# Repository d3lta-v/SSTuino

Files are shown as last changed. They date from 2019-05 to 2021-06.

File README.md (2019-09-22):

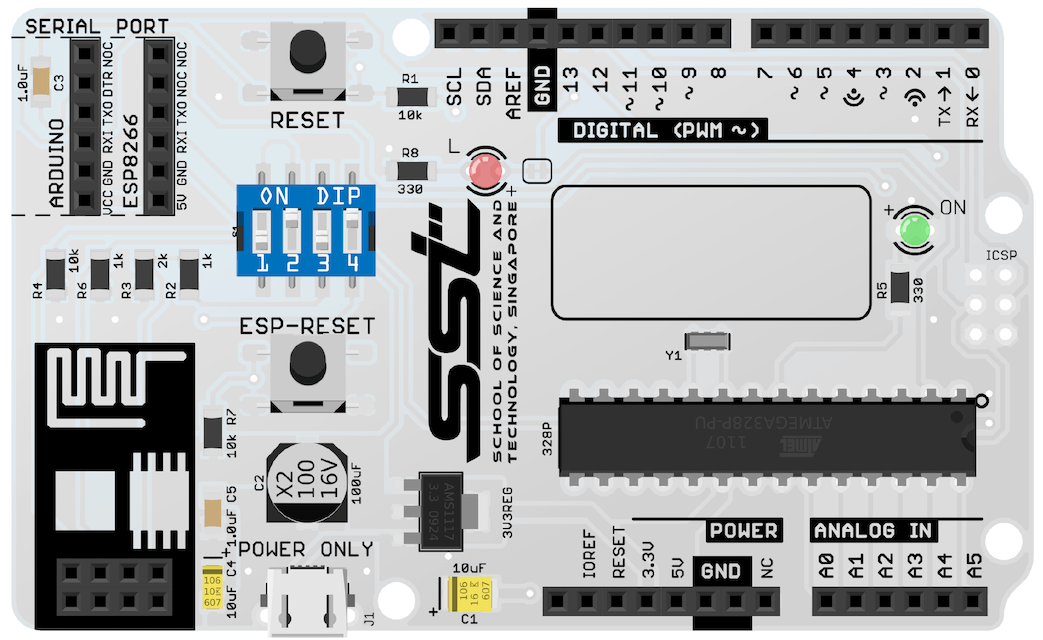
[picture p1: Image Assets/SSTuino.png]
SSTuino


Designed by FourierIndustries LLP | Designed, assembled and tested in Singapore

# SSTuino

SSTuino is an easy to use Wi-Fi enabled microcontroller, designed and fabricated by SST Alumni. Users can write programs to connect or control things over the Internet. It is derived from the SPEEEduino 1.1 with some improvements.

**SSTuino Official Website: [https://sstuino.fourier.industries](https://sstuino.fourier.industries)**

Related projects:

* [SSTuino Companion Library](https://github.com/d3lta-v/SSTuino_Companion)
* [Ultra Light Wi-Fi Interface](https://github.com/d3lta-v/ULWI)
* [ESPblaster](https://github.com/d3lta-v/ESPblaster)

## Technical information

### Repository Layout

* **SSTuino**: EAGLE files for SSTuino
* **Image Assets**: Image assets for websites related to the SSTuino and markdown pages.

### Startup states table

This table controls the various startup states of the ESP8266-01 Wi-Fi module, which allows it to operate, or be reprogrammed with your custom firmware, or even be electrically isolated from the rest of the SSTuino entirely.

|  | GPIO0 (1) | GPIO2 (2) | ESP-RX connect to D4 (3) | ESP-TX connect to D2 (4) | ESP-RESET Button |
|---|:---:|:---:|:---:|:---:|:---:|
| Wi-Fi Enable | ⬆️ | ⬆️ | ⬆️ | ⬆️ | Leave open |
| Disconnect ESP-01 | ❎ | ❎ | ⬇️ | ⬇️ | Leave open |
| Reset ESP-01 | ❎ | ❎ | ❎ | ❎ | Press down |
| Flash ESP-01 | ⬇️ | ⬆️ | ⬇️ | ⬇️ | Press down, set switches, release |

## Contributing

Contributing to the SSTuino Git Repository requires you to have EAGLE 8.4 or newer which supports Managed Libraries.

SSTuino primarily uses EAGLE's Managed Libraries made by Sparkfun, but also contain our own custom footprints and SMD component footprints from Cytron.

## Our team

* Chief Designer: Pan Ziyue ([@sammy0025](https://twitter.com/sammy0025))
* Assistants/Advisers: Goh Qian Zhe ([@QianZheGoh](https://twitter.com/QianZheGoh))
* The awesome folks at Arduino, Sparkfun and Adafruit for technical reference and ECAD models.

OSHW

Open Source Hardware (OSHW)

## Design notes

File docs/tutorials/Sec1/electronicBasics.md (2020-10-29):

---
title: How to not burn your LEDs!
date: 2019-07-03
author: Goh Qian Zhe
---

# How to not *burn* your LEDs!

Before we go into electronics, here is what will happen when if you do not handle them well.

sparkfunGIF

## Some essentials...

In your SSTunino kit, we have provided some components for you to use, and is listed inside the [parts list page](https://d3lta-v.github.io/SSTuino/tutorials/partsList.html). **Note:** If there are any components missing from the kit when you first recieve it, please approach your ICT teachers.

This tutorial will cover the details of the components that are included in the SSTuino Kit, along with some theory behind electronics to help you to build your first circuit in the meantime. This tutorial page is very useful as you can reference to the components in the event you forget what it is.

## Table of Contents

* [SSTuino Board](#sstuino-board)
* [USB C to Micro USB Cable](#usb-c-to-micro-usb-cable)
* [CP2102 MicroUSB Serial Converter](#cp2102-microusb-serial-converter)
* [ESP01S WiFi Chip](#esp01s-wifi-chip)
* [The Resistor](#the-resistor)
* [Light Emitting Diode (LED)](#light-emitting-diode-led)
* [Breadboard](#breadboard)
* [Wires](#wires)
* [Push Button](#push-button)
* [Light Dependant Resistor](#light-dependant-resistor)
* [Buzzer](#buzzer)
* [Potentiometer](#potentiometer)
* [Ultrasonic Sensor](#ultrasonic-sensor)
* [TMP36 Temperature Sensor](#tmp36-temperature-sensor)
* [PIR Proximity Sensor](#pir-passive-infra-red-sensor)
* [DHT11 Temperature and Humidity Sensor](#dht11-temperature-and-humidity-sensor)
* [Servo](#9g-micro-servo)
* [RGB LEDs](#rgb-led-common-cathode)
* [Last but not least](#last-but-not-least)

## SSTuino Board

<p align="center">
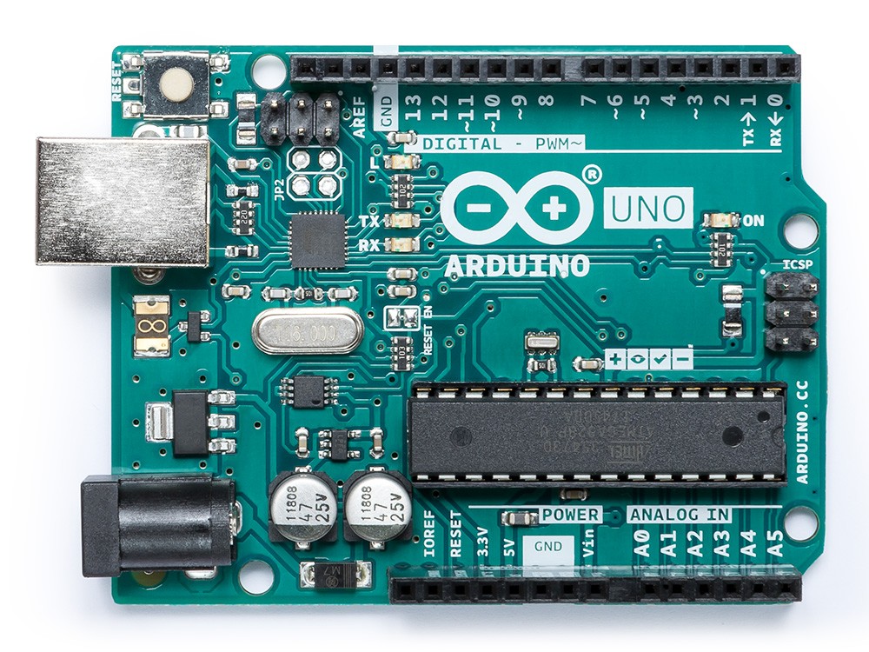
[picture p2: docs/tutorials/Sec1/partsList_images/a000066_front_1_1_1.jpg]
  
   
</p>

*Notice any difference?*

For students who are familliar with the Arduino UNO, you would realise that it looks pretty simillar to the SSTuino. This is because that the SSTuino is an adapted design from the Arduino UNO. This device shares a lot of similarities as the UNO such as:

- Coding compatability
- Shield compatability as the SSTuino shares the same I/O Pins as the Arduino Uno
- Sharing the most of the same components

The major design difference with this board is that it has a extended board footprint to accept a WiFi chip, resulting the SSTuino to be an Internet-Of-Things (IoT) enabled product. This means that the SSTuino can connect to the internet to send/recieve data!

## USB C to Micro USB Cable

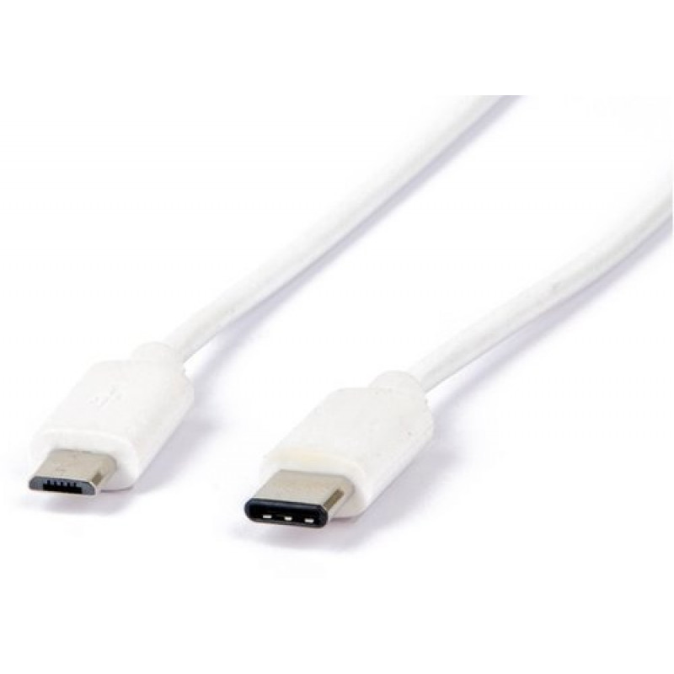
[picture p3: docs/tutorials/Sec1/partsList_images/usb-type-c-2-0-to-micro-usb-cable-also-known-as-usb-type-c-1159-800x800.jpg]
USBC to MicroUSB


The USB C to Micro USB Cable is a unique cable that helps you connect your USB C Mac to the CP2102 MicroUSB Serial Converter. As this type of cable is less commonly seen in the market, please take good care of this wire as it is not easy to obtain one.

## NEU (New Enhanced UART) CP2102

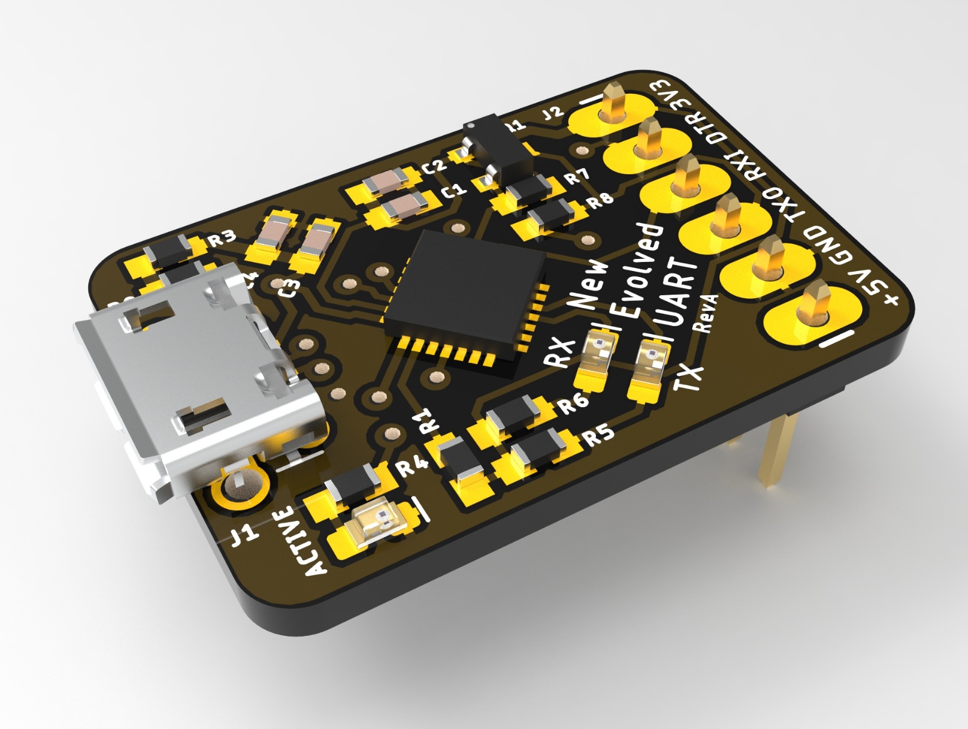
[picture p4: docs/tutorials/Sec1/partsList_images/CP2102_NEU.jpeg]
MicroUSB CP2102


The CP2102 MicroUSB Serial Converter is a very important device to have as it is the communication tool between the computer and the microcontroller (SSTuino). We designed SSTuino to have a external Serial Converter as not only is it modular, where you could change the chip in the event it is spoilt, you could also use the CP2102 to communicate with other serial devices such as the ATTiny85 or the Raspberry Pi.

This is where you would use your USB C to Micro USB cable to plug into this chip for uploading of code from your computer to the SSTuino.

The NEU (New Enhanced UART) is a custom designed serial converter designed by Pan Ziyue for the SSTuino Innovator's Kit, and is designed to work with your Mac and SSTuino. As there are limited production quantities in each run, please refrain from losing the chip. Moreover each chip is expensive to manufacture so again please take good care of the chip.

## ESP01S WiFi Chip

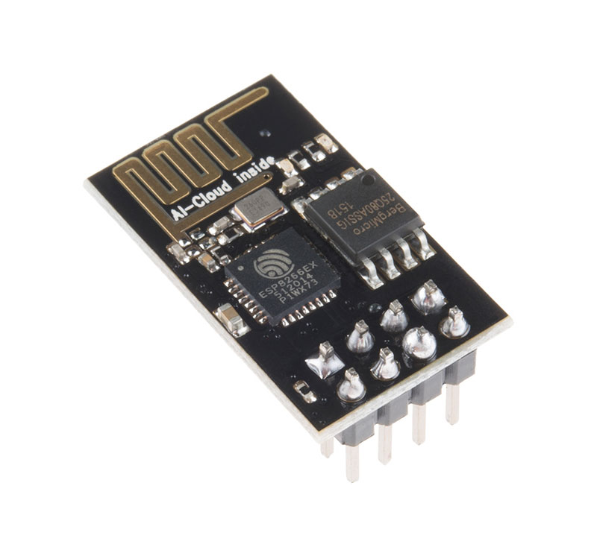
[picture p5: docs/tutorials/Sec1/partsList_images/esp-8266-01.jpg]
ESP-01S


The ESP01S WiFi Chip is what sets the SSTuino different from the Arduino UNO. It allows the SSTuino to be able to connect to the internet, allowing the SSTuino to have smart home, automation and internet connected sensor abilities.

Our team is developing more content to help you get started in developing IoT products, so do watch this space for more details.

## The resistor
### Ohms Law

For a more detailed read, click [here](https://www.allaboutcircuits.com/textbook/direct-current/chpt-2/voltage-current-resistance-relate/)

Ohm's Law is the most basic relationship between voltage, current and resistance. A circuit is formed when there is a conductive path for electric charge to move. 

The movement of the electric charge is **current**, expressed in Amperes (A). 

The force that enables the electric charge to move, or the potential energy is **voltage**, expressed in volts (v). 

In the circuit, there is bound to be some "friction" that resists the movement of electric charge, and that is **resistance**, expressed in Ohms (Ω). 

ohmLawTable

Resistors are essential in every circuit. They limit the flow of current in your circuit so *hopefully* there are no burnt components. 

### Types of resistors

For generic resistors, there is generally two types of resistors: Carbon Composite Resistor or Film Type Resistor. Carbon resistors are popular due to their extremely low cost and good accurancy with low enough tolerance (usually about +- 5%). Flim Type Resistor, while being slightly costlier, provide closer tolerances (up to +-1%) from the rated resistance.

<p align="center">
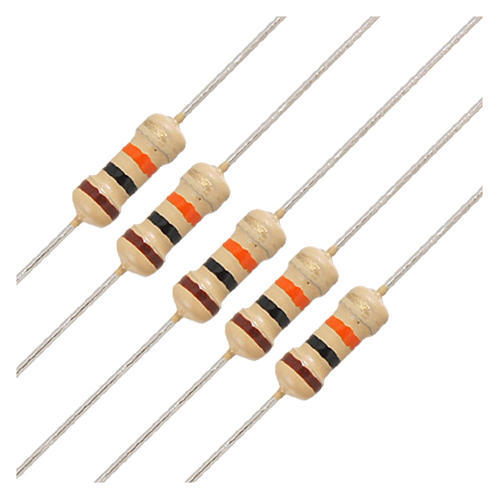
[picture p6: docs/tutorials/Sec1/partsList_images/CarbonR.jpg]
  
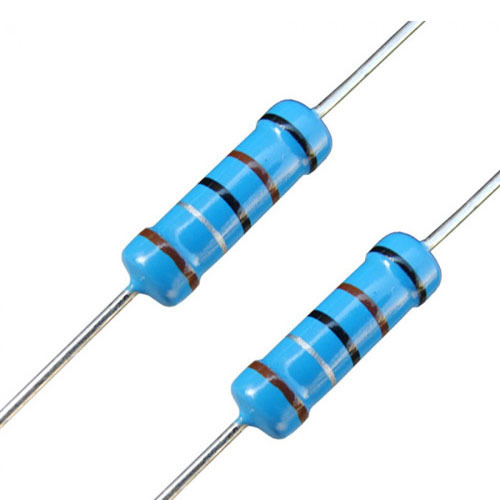
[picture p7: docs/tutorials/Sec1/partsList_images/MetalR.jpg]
   
</p>

*Carbon Film Resistors (left) and metal oxide resistors (right).*

The resistors provided in the kit is metal oxide resistors and have values of 330 Ohm and 10K Ohm. You can read the values of the resistor from the colour band on the component.

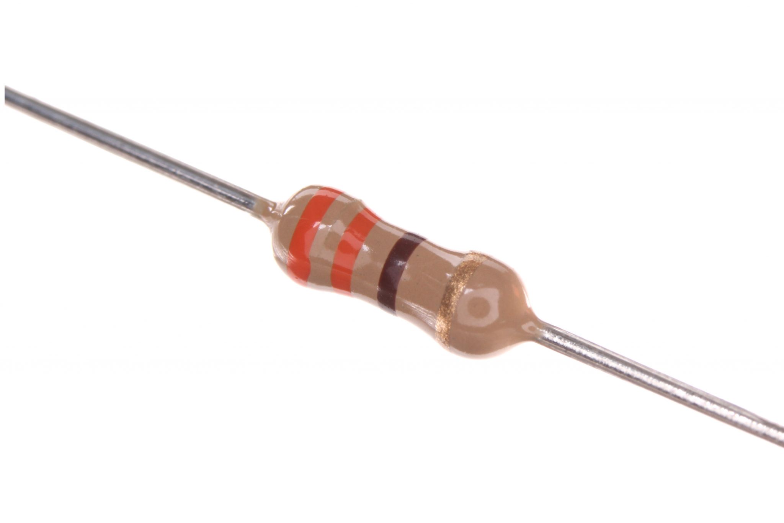
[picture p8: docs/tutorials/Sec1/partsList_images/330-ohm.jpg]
330Ohm


This is a **330 Ohm** resistor.

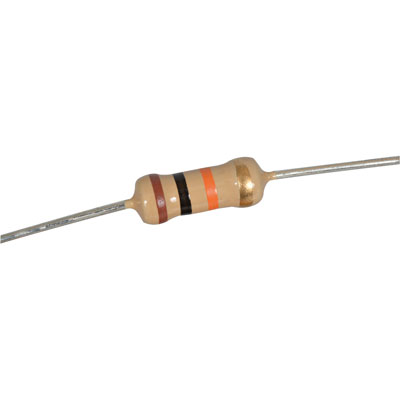
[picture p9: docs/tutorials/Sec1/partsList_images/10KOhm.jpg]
10KOhm


This is a **10K Ohm** resistor.

If you are wondering how to read the values of resistors, refer to the infograpic below:

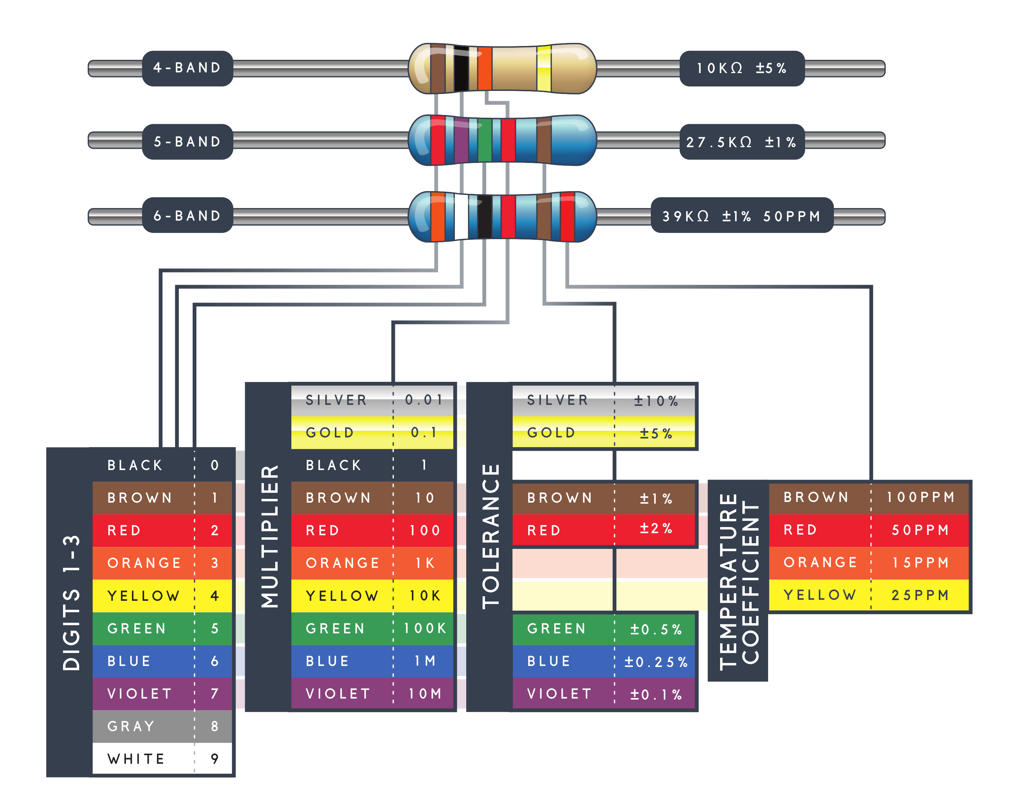
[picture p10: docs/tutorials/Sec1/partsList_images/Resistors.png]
resistorChart


## Light Emitting Diode (LED)

Somehow or another, you would realise that you would need something to light up! Say hello to the LED! LEDs are small, efficient lightbulbs (that are rather bright). They are found in a large variety of devices like mobile phones, computer screens, the headlamps of the car and even spotlights!

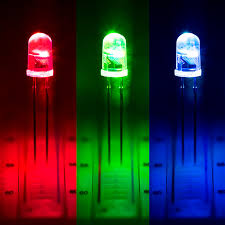
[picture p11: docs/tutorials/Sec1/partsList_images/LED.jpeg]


So, you might be wondering how should you place an LED in a circuit? Here are the 3 most important things to take note:

### Polarity is important

As LEDs are essentially diodes, it will only allow current flow in one direction. This is why if you take a look at your SSTuino Innovator's Kit, you would realised that your LEDs have legs that are of different lenghths. Does the different lengths of legs indicate manufacturing defect? On the contary, the legs are specifically manufactured like this so that the you can identify the polarity of the LED easily.

The longer leg of the LED is the **positive** leg and is called the **anode**. The shorter leg of the LED is the **negative** leg and is the **cathode**. 

*But what if you just nice happen to connect it the wrong way? Would it explode?* 

The LED would not light up, so not to worry. You can just simply reverse the polarity of the LED (i.e flip the thing around) and it will work again!

### More current = More light!

As the LED is brighter (with the same voltage applied), the current draw would be higher. If you happen to purchase super-bright LEDs, you would realise that they drain your battery easily. With this, you can change the brightness of the LED by adjusting the amount of current that goes through it.

### BOOM!

As with most electronics, there is always a limit to everything. Once an LED draws current beyond a certain limit, you can see the colour change and then... it dies. RIP.

So to prevent tragic things like this from happening, we introduce resistors into the circuit to limit the amount of current the LED can draw. But what resistor would be most suitable?

## Some simple circuit theory...

Let us assume that we have some LEDs, resistors and a power source. Without any knowledge about datasheets and calculation, how should we go about connecting them together?

connection

It is that simple.

Moreover, a good resistor value for LEDs is 330Ohms (can be more or less), so we can simply use this resistor. *Easy, right?*

## Breadboard

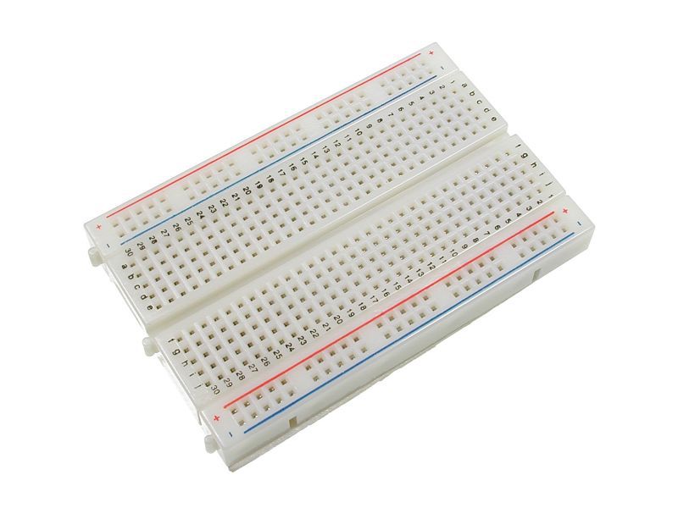
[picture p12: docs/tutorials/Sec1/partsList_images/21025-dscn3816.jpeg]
Breadboard


So you happened to see a retangular shaped block with holes in it and wondered what it was? This block is called a **breadboard** or **prototyping board**. The breadboard is a very important part of your prototype when you develop new things!

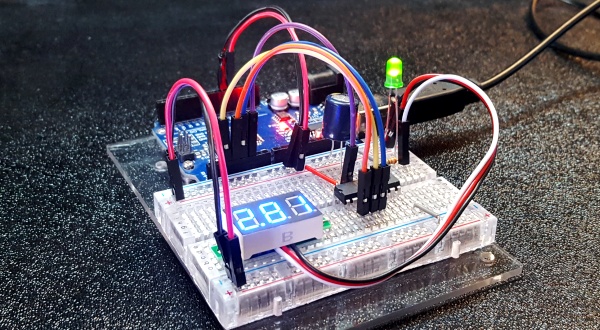
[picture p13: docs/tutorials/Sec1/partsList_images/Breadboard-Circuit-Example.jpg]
Breadboard with circuit


In your ICT lessons, your teacher would go through with you on how to connect up your circuit. Moreover, you would be using TinkerCAD to simulate and view your *virtual* circuit before actually building it, preventing any (touch wood) *magic smoke*.

The layout of the breadboard is done such that you can assemble your circuits easily.

<p align="center">
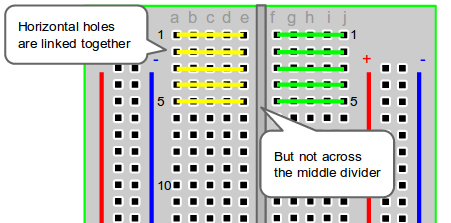
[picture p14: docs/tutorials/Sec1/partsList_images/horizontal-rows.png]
  
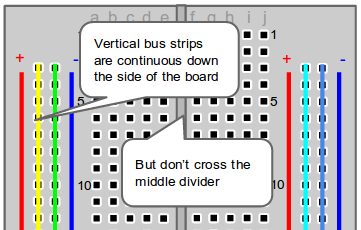
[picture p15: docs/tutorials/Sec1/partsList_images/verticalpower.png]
   
</p>

## Wires

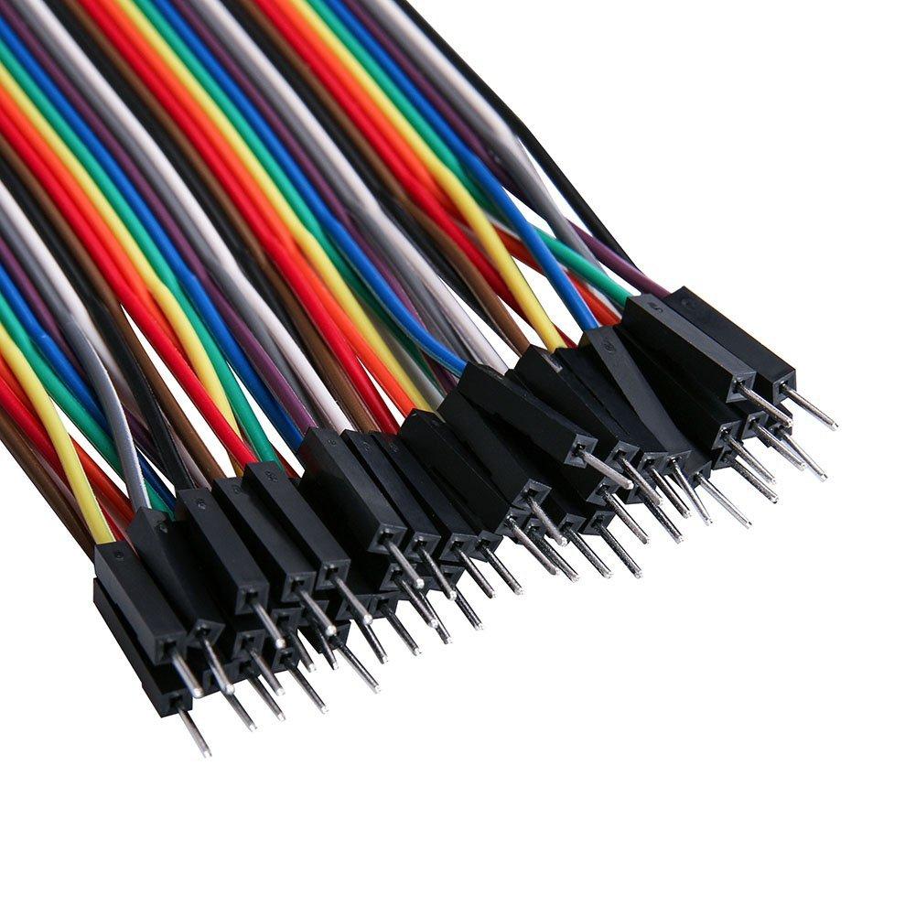
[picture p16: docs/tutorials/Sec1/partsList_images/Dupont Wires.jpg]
Wires


Wires are the most important part of your circuit. Without them, you would not be able to have electricity flowing through your circuit as there is simply nothing connecting them together! The wires provided in the kit are Male - Male Dupont wires (*I dont think I have to explain why the ends of the wire is male, right?* *wink*), and are the right size for you to be able to connect from your SSTuino to the breadboard or the component.

## Push Button

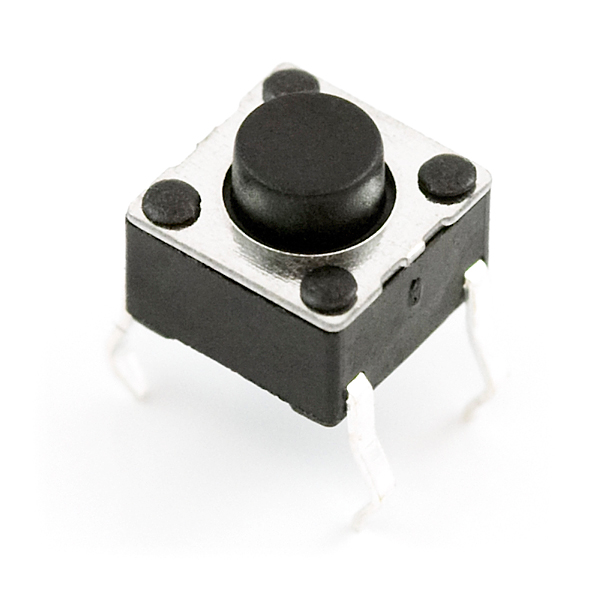
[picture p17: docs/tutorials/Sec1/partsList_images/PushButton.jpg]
Push Buton


This push button is a very simple example of a switch. But before you connect this push button into your house's mains, please do not do so :). The push button is meant for the breadboard instead.

When the push button is pressed down, the circuit is closed and current would flow through the two terminals of the button. Likewise, when the push button is not pressed down, the circuit will be open and current would not flow through the two terminals of the button. One good example would be your Macbook keyboard. As you depress the key, the circuit is closed and the computer can detect wether the key is pressed down or not

## Light Dependant Resistor

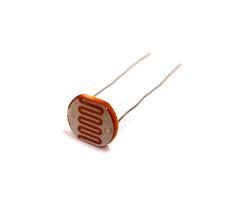
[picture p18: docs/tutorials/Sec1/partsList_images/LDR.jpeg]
LDR


As the name suggests, the Light Depedant Resistor (or Photoresistor) is a component that changes resistance when the light intensity changes. For the LDR that is provided in the kit, the resistance of the LDR **decreases** when the light intensity **increases**.

Like a normal resistor, there is no polarity for the LDR and can be connected in both sides.

## Buzzer

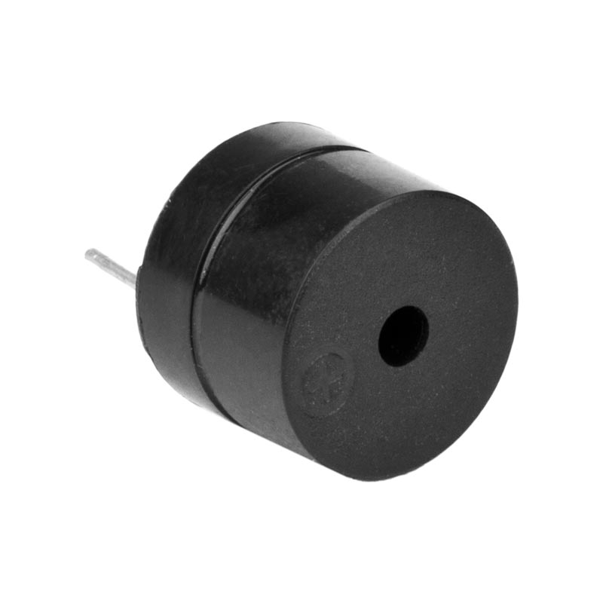
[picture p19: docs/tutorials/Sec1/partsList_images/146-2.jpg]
Buzzer


This buzzer is a Piezo Buzzer. If you try to open up the buzzer, you would see that there are a few embedded components inside the buzzer. What happens when you connect it to power is that it is converted to an oscilating signal, which is amplified and applied to the piezo disc. This causes the material to expand and contract rapidly, which results in sound waves being produced. 

**Note:** The sound from the Piezo buzzer can be quite sharp and loud. Do be careful when using these components.

## Potentiometer

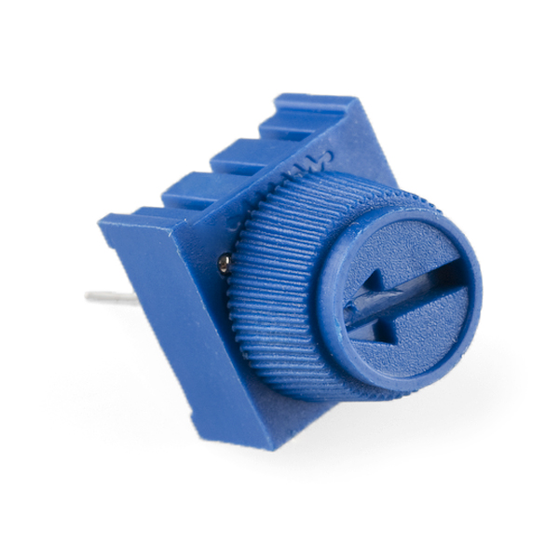
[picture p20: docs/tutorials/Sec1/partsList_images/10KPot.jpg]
10K pot


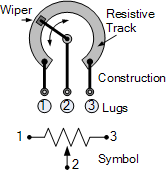
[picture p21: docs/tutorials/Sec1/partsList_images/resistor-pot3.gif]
Pot Sch


The potentiometer is a variable resistor, with a adjustable knob. As the knob is turned from one side to another, the resistance changes. Potentiometers are used for controlling devices, such as the brightness of the LED, and with the appropriate circuit, the speed of a motor.

## Ultrasonic Sensor

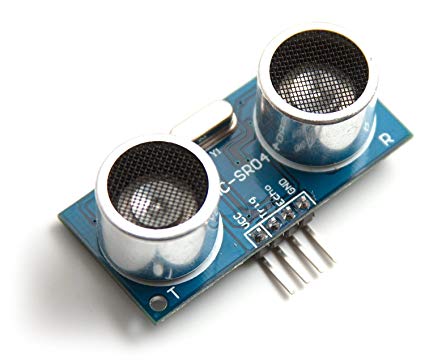
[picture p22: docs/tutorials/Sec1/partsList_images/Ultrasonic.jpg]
Ultrasonic


The ultrasonic sensor is a device that measures distance by emitting ultrasonic waves, waits for the wave the bounce back and then measure the time taken.

## TMP36 Temperature Sensor

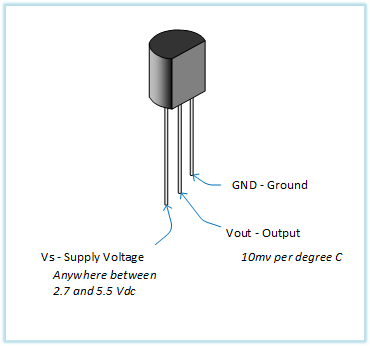
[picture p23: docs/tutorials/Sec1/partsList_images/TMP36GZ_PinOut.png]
TMP36Pinout


The TMP36 temperature sensor is a rather accurate sensor despite is low price. For more information, visit the [Adafruit Website](https://learn.adafruit.com/tmp36-temperature-sensor/overview).

**Note:** You may notice that this package may resemble that of other components such as transistors. **Please do not mix them up and read the respective manuals carefully.** The component model would be marked out on the **flat** side of the component for this package. Use the model number to search for the pinouts for you to make sure you are connecting the component the right way.

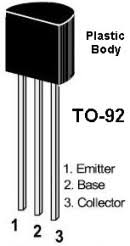
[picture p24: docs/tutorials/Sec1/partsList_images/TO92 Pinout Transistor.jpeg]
TransistorPinout


This shape and pinouts is called the TO-92 Package and is a very cheap and easy to manufacture method for transistors.

## PIR - Passive Infra-Red Sensor

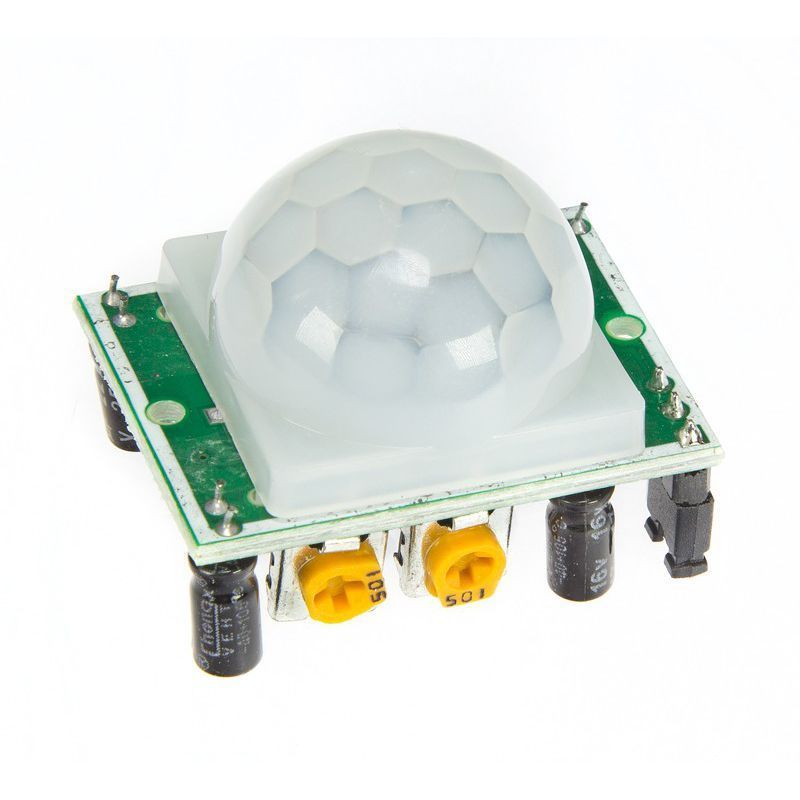
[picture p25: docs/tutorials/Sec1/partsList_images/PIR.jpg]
PIR


PIR sensors are low-power, inexpensive and easy to deploy devices that detect if a person is in range of the sensor. A common use would be the light sensor installed in toilets that automatically turns on the lights when someone steps into the toilet.

To find out more about how it works, check out this detailed explanation from Adafruit: [https://learn.adafruit.com/pir-passive-infrared-proximity-motion-sensor/how-pirs-work](https://learn.adafruit.com/pir-passive-infrared-proximity-motion-sensor/how-pirs-work)

## DHT11 Temperature and Humidity Sensor

DHT11

The DHT11 Temperaure and Humidity sensor is an excellent hobbyist sensor, albeit with low refresh rates. It is also cheap to purchase and has relatively good accuracy for basic data logging. The data from the sensor can also be easily read from any microcontroller.

## 9g Micro Servo

servo

This Micro Servo has a lot of cool uses! Being a servo, it has precise control from 0 to 180º and is a very good component for prototyping.

## RGB LED (Common Cathode)

RGB LED

The RGB LED is a more complex version of the conventional coloured LED. It combines 3 LEDs (Red, Green and Blue) into one package. By configuring the intensity of the various LEDs, you can create lots of different colours from this LED.

## Last but not least

 This tutorial is meant for you to know that with every component that you use, you will need to decide for yourself wether it fits the circuit or not; be it simple components like LEDs and buzzers to more advanced (*and more expensive*) components like LCD displays and sensors!

One thing that is great when you explore the Arduino ecosystem is the immense amount of community support. When in doubt, always ask. As an individual learning 21st century digital skills, there are lots of platforms where your queries can be answered. It is just a matter of wether you would want to go and find the correct resources or not.

Therefore, before giving up on your design, maybe consider:

* Refering to your component manual. They will include essential infomation about the properties of the component
* Google the issue. Usually people would have posted this issue online in places like forums (StackOverflow, Arduino forum, Reddit etc.)
* Ask around about that issue. You can also post your questions in the appropriate channels, and if the question is good, others can learn from the issues that you faced!

If you would like to know more about:

* Ohm's Law : [(Link)](https://learn.sparkfun.com/tutorials/voltage-current-resistance-and-ohms-law/all)
* LEDs : [(Link)](https://learn.sparkfun.com/tutorials/light-emitting-diodes-leds/all#introduction)

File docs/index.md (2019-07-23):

---
---

## SSTuino Official Webpage

Populated PCB

SSTuino is an easy to use Wi-Fi enabled microcontroller, designed and fabricated by SST Alumni. Users can write programs to connect or control things over the Internet. It is derived from the SPEEEduino v1.1 with some improvements.

### Documentation

For documentation on this project, please refer to our [Github Wiki](https://github.com/sammy0025/SSTuino/wiki) (currently WIP) for more information.

For tutorials regarding SST lessons, please refer to the tutorials here:

* [https://d3lta-v.github.io/SSTuino/tutorials/](https://d3lta-v.github.io/SSTuino/tutorials/)
* [https://sites.google.com/sst.edu.sg/sstuino/home](https://sites.google.com/sst.edu.sg/sstuino/home)

OSHW

Open Source Hardware (OSHW)

### Interested to make a difference?

Students who are interested to deveop our product further can express their interest in **[this form](https://forms.gle/ntMWiXFDy3Ya1Pq5A)**.

### Our team

The Team

*Pan Ziyue (Left) and Goh Qian Zhe*

### Support or Contact

Pan Ziyue: [random.rrr3@gmail.com](mailto:random.rrr3@gmail.com)

Goh Qian Zhe: [goh_qian_zhe@s2012.sst.edu.sg](mailto:goh_qian_zhe@s2012.sst.edu.sg)

If you need anything to be replaced, please email us!

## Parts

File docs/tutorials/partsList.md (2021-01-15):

---
title: Parts List
date: 2019-04-18
author: Goh Qian Zhe
---

# Parts List for the SSTuino Innovator Kit (2021)

This parts list applies to the kits for the 2021 batch.

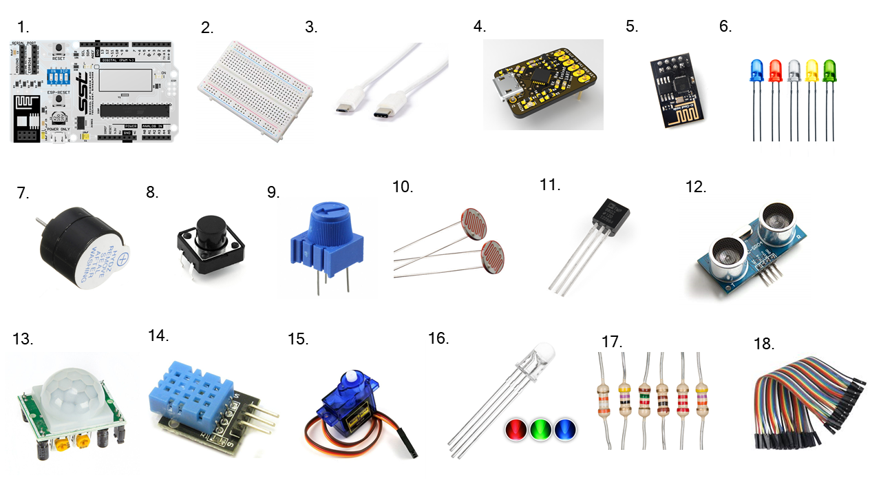
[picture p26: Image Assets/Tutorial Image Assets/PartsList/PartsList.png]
Parts List


| No. | Component Name | Quantity  |
|--- |:---:| ---:|
| 1 | SSTuino Board | 1 |
| 2 | Breadboard | 1 |
| 3 | USB C to MicroUSB Cable | 1 |
| 4 | NEU (New Enhanced UART) | 1 |
| 5 | ESP01S WiFi Chip | 1 |
| 6 | Assortment of LEDs | 1 bag |
| 7 | Buzzer | 1 |
| 8 | Push Button | 2 |
| 9 | Potentiometer (10K Ohm) | 1 |
| 10 | Light Dependent Resistor | 1 |
| 11 | TMP36 Temperature Sensor | 1 |
| 12 | Ultrasonic Sensor | 1 |
| 13 | PIR Proximity Sensor | 1 |
| 14 | DHT11 Temperature and Humidity Sensor| 1 |
| 15 | Servo | 1 |
| 16 | RGB LEDs | 1 |
| 17 | 330Ohm and 10KOhm resistor reel | approx 25 |
| 18 | Dupont cables (wires) | 1 |

In the event of any missing components for the kit, feel free to bring this up to your ICT teacher.

The explanation of the components included in the kit is in this particular tutorial: [*How to not **Burn** your LEDs*](https://d3lta-v.github.io/SSTuino/tutorials/Sec1/electronicBasics.html)

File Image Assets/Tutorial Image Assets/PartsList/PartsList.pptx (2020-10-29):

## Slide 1

1.

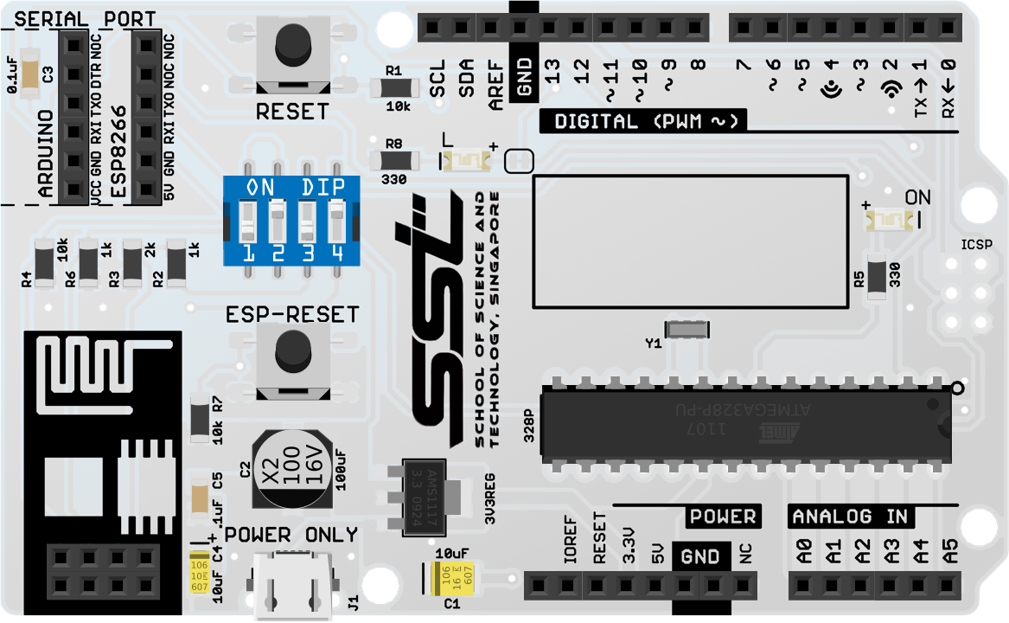
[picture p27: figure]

2.

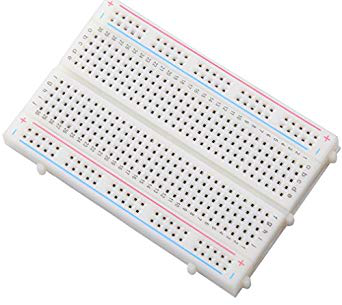
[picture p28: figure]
Image result for mini breadboard

3.

Image result for usb c to micro usb cable

4.

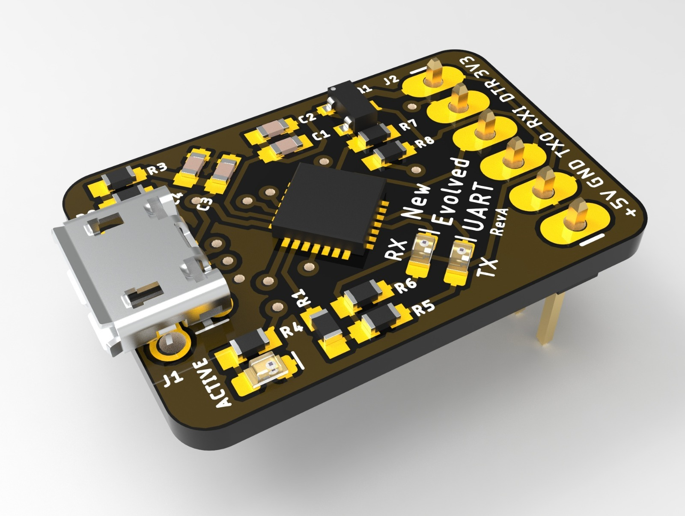
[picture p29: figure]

5.

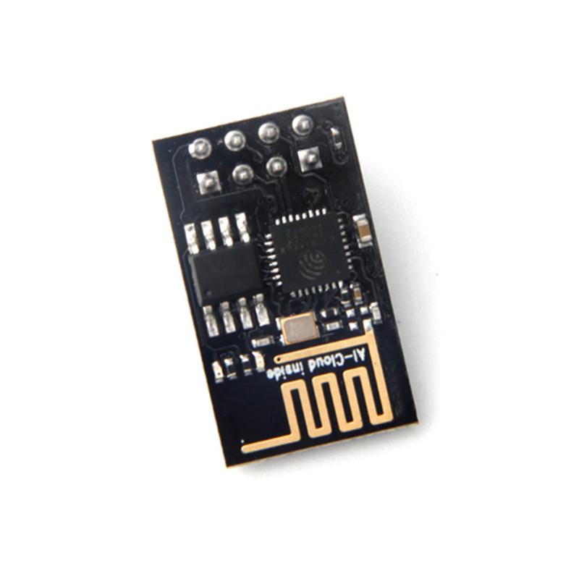
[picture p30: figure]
Image result for ESP 01

6.

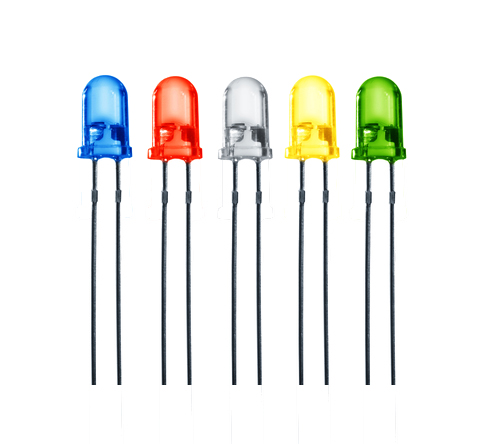
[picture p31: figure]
Image result for LEDs

7.

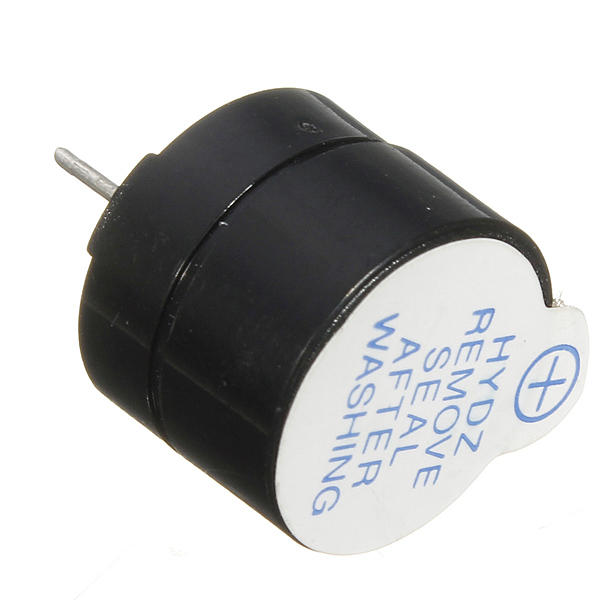
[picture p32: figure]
Image result for 5v buzzer

8.

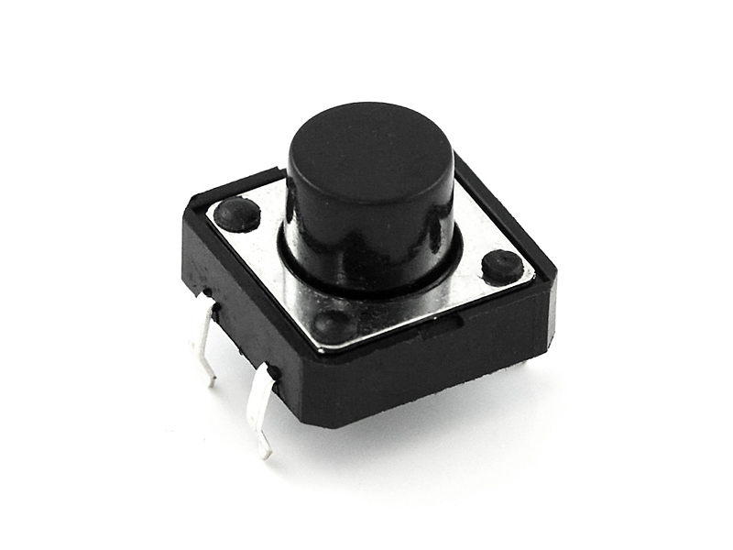
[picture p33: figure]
Image result for push button

9.

Image result for BOURNS 3386F potentiometer

10.

Image result for ldr
Image result for tmp36

11.

12.

Image result for ultrasonic sensor

13.

14.

15.

16.

17.

18.

HC-SR501 PIR Motion Sensor Module - Elektor
Using DHT11 - Hackster.io
SG90 Micro Servo
Electrobot 100 Pcs 5mm RGB LED Diode Lights Tricolor (Multicolor Red Green Blue 4 pin Common Cathode Clear DC 20mA/Color) Super Bright Lighting Bulb Lamps Electronics Components Light Emitting Diodes: Amazon.in: Industrial
Image result for resistors
Image result for dupont wires

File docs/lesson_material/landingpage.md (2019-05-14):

---
title: Setup
date: 2019-04-18
author: Goh Qian Zhe
permalink: /tutorial/
---
# Tutorials
Tutorials can help you get started with using your SSTuino, or bring you further.

## Before you start
Before you begin playing around with the SSTuino kit here are some things to do:

* Click here to access list of items provided in your kit.
* [Click here to setup your laptop and SSTuino kit ready for use.](https://d3lta-v.github.io/SSTuino/gettingStarted/)

## Sec 1 Tutorials

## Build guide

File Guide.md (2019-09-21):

# Getting started with the SSTuino

*This section has unconfirmed steps/the steps require further testing. However, just follow though this guide, as it currently works with most of the Macs for SST.*

SSTuino is an easy to use Wi-Fi enabled microcontroller, designed and fabricated by SST Alumni. Users can write programs to connect or control things over the Internet. It is derived from the SPEEEduino 1.1 with some improvements.

This tutorial is a simple guide on how to get started with the SSTuino. Further guides will be posted and linked to this page in the future.

## Setting up...

Here are a list of things you require to start using the SSTuino. **Installation of the Arduino IDE and Silicon Labs driver for the CP2102 provided in the SST kit will be covered in the later sections**
* A computer loaded with the Arduino IDE, available [here](http://https://www.arduino.cc/en/Main/Software)
* For MacOS users (and Windows users who have to manually install the driver), please download the Sillicon Labs driver from [this website](https://www.silabs.com/products/development-tools/software/usb-to-uart-bridge-vcp-drivers)
* The ESP01 Module (WiFi Chip)
* USB to serial converter. The ones included in the **SST kit** is the CP2102.

## Installation of the Arduino IDE

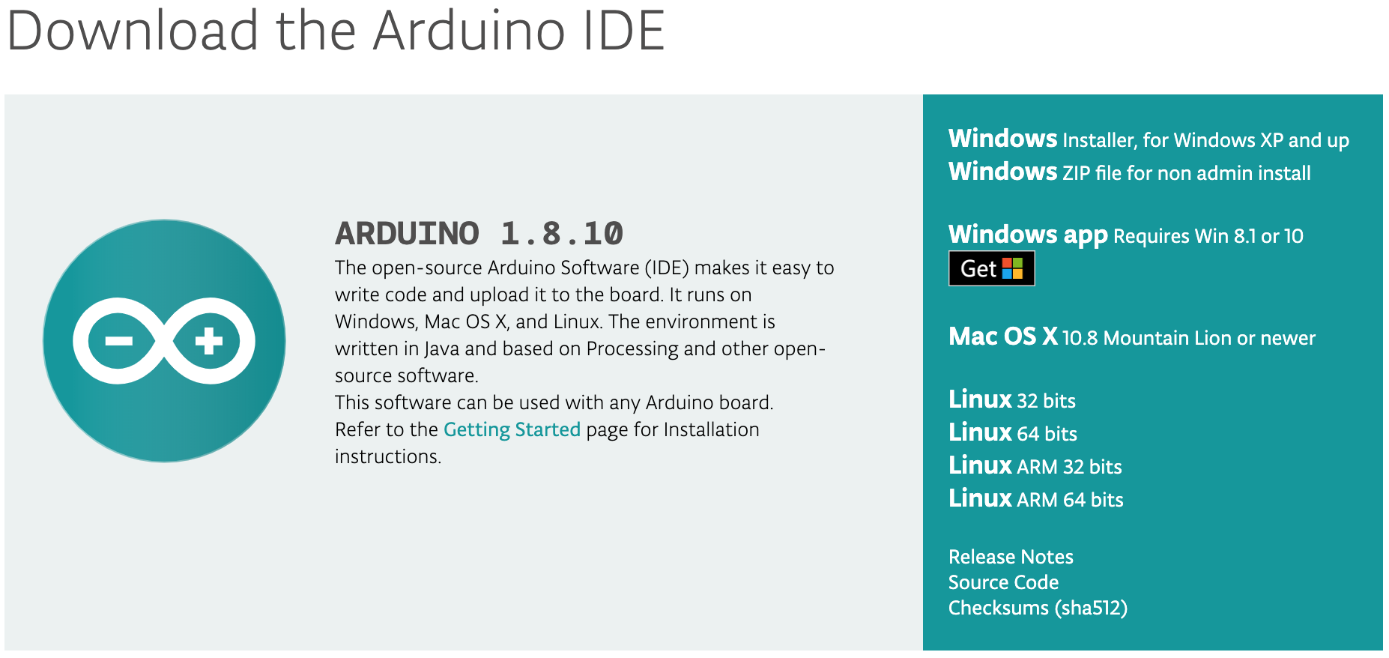
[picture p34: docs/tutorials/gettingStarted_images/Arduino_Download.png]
Arduino.cc Download Page


*  Go to the the downloads page [here](http://https://www.arduino.cc/en/Main/Software)
*  Download the version of the application you require.
   * For MacOS users download the Mac OS X version (10.7) and newer.
   * For Windows users, there are quite a few options:
      * For all devices, you can download either the installer or the zip file. I personally prefer the zip file (as it can be done as a non-admin install, and it is convinent.) However, it is your personal preference for the installation method.
      * Alternatively, for Windows 8.1 and 10, you can go to the Microsoft Store and download it.

### Installation for MacOS
After download of the zip file from the Arduino website, simply copy the .app file into your *Applications* folder. 

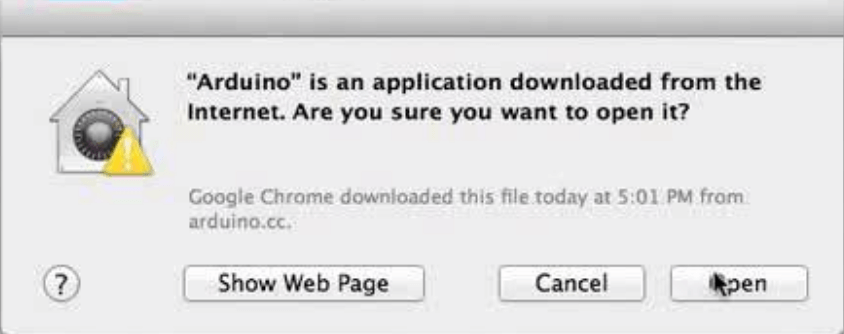
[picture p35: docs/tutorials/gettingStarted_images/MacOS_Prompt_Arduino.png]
MacOS prompt


In any event the system asks you whether to open the app, just click open

## Installation of the CP2102 Driver
We are using the CP2102 USB to serial converter for our SSTuino.

### Installation for MacOS

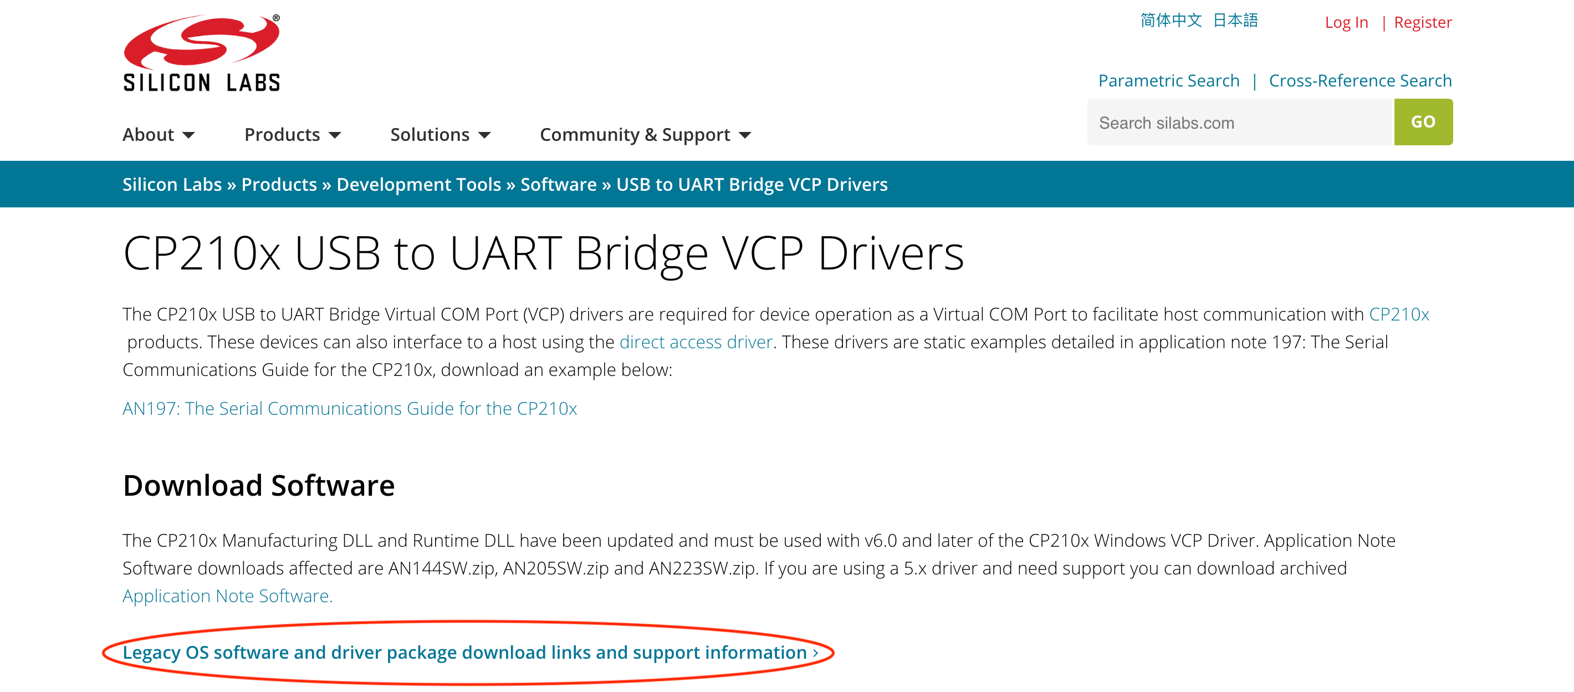
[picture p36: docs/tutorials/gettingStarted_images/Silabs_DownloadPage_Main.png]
Silabs_Download_Main


For MacOS users, the Silicon Labs driver has to be manually downloaded and installed. The driver can be downloaded [here.](https://www.silabs.com/products/development-tools/software/usb-to-uart-bridge-vcp-drivers)
After the page has loaded click the link circled in the picture. *Note - this procedure is not finalised. This method will be used for the time being due to incompatability with the new Macbooks.*

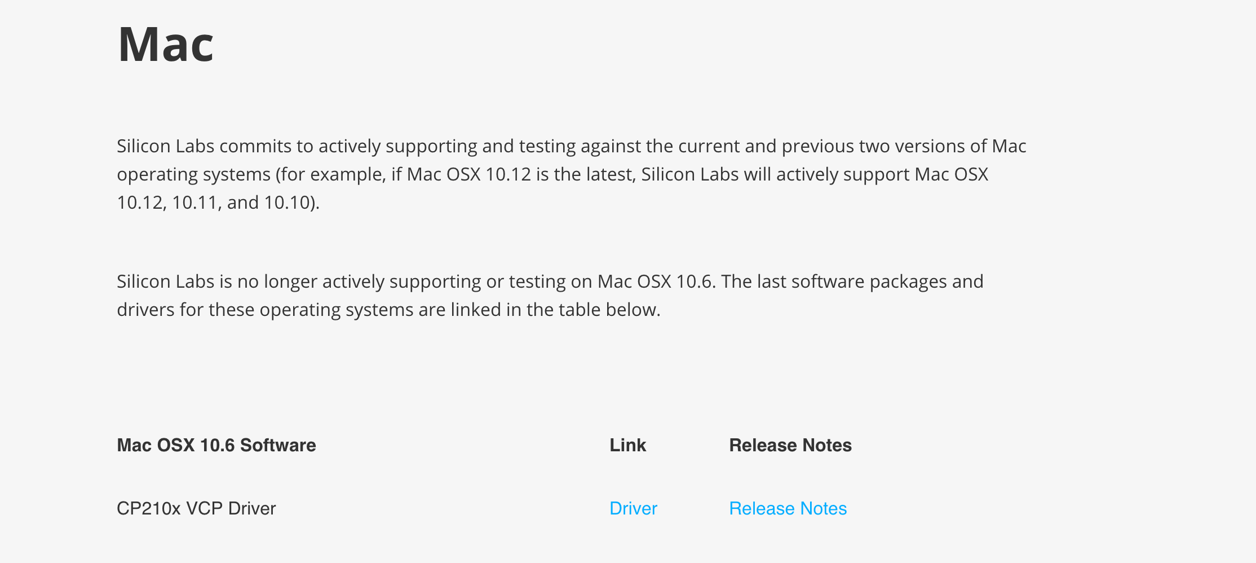
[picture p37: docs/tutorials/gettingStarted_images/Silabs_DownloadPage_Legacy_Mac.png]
Silabs_Download_Mac_legacy


Navigate to this area and download the driver.

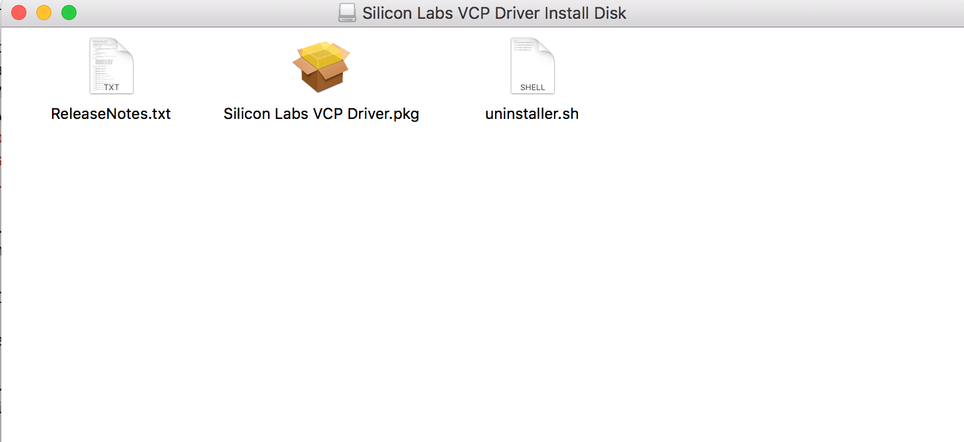
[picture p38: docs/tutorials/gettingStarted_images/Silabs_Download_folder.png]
Silabs_Download_Folder


After the driver has been downloaded, *unzip* the file and launch the **disk image.** You will now see three files, as pictured below. Run the package (.pkg) file.

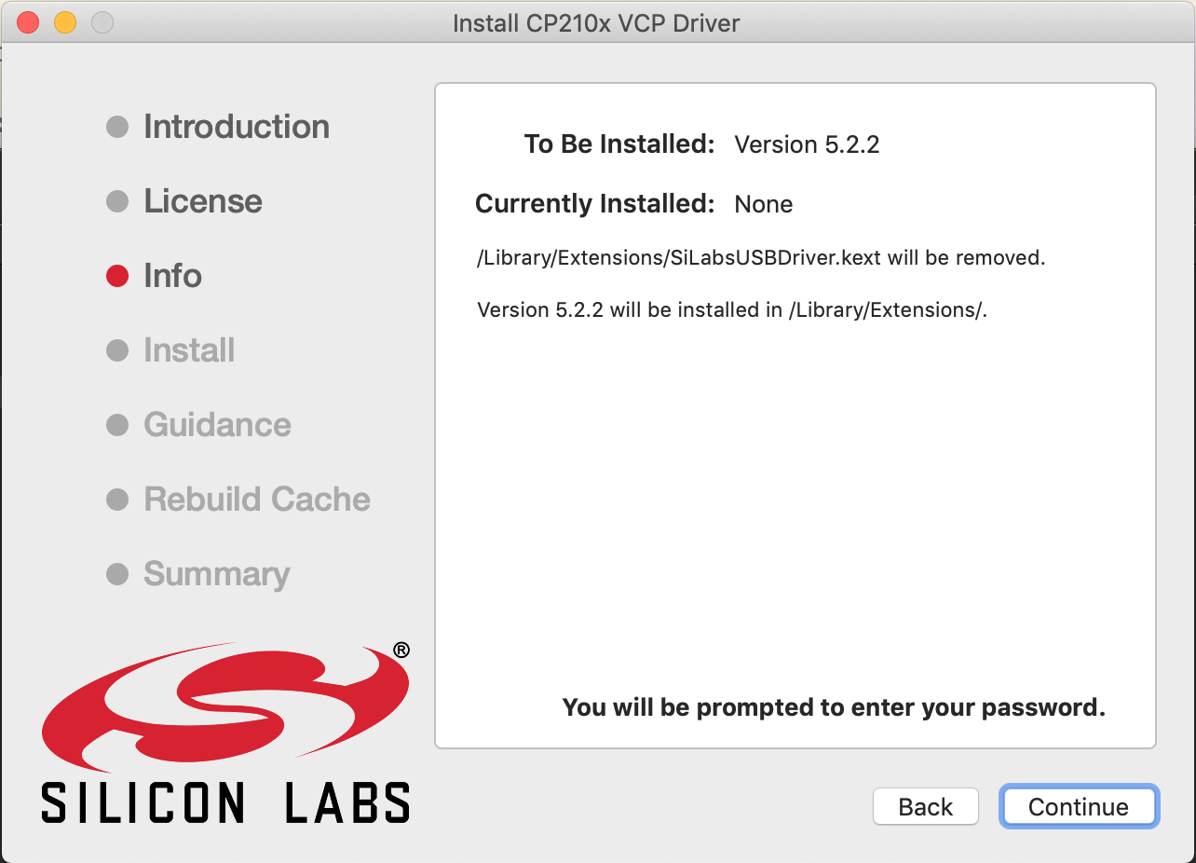
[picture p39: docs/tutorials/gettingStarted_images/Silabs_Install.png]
Silabs_Installation_App


Install the drivers.  **This requires elevated admin rights (devices with parental controls will not be able to install unless an admin allows the installation.)**

During installation, you may encounter a pop-up which would ask you to go to your system preferences. Click ok first. *This is still undergoing tests as we have issues with this part.* 

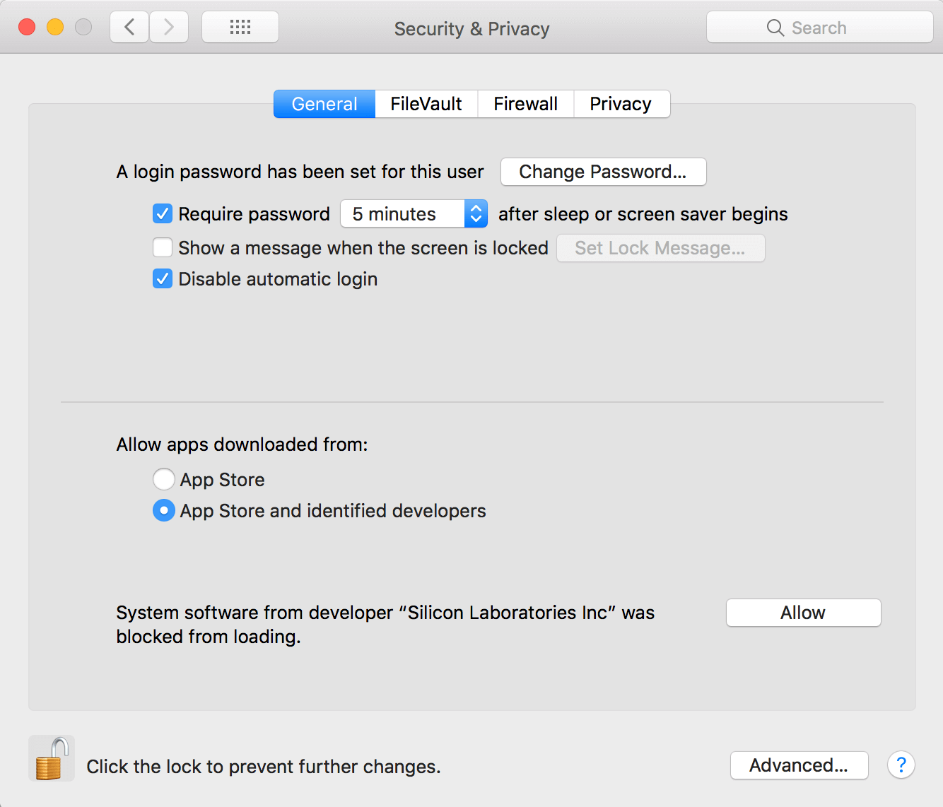
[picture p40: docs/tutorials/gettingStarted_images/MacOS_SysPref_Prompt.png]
SiLabs Prompt


While the installer is running, go to System Preferences -> Security and Privacy and allow the Silicon Labs prompt. 

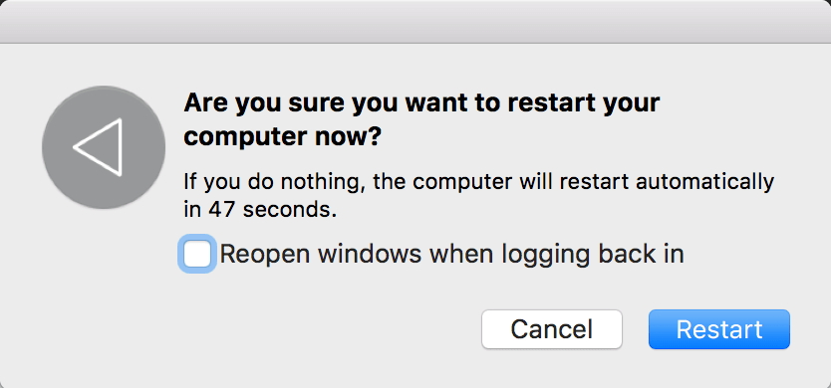
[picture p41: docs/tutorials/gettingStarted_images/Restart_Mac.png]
Restart Mac


After the installation has finished, simply restart your mac.

To check if the USB to serial converter can be detected, go to Terminal and type in this line

`ls /dev/tty.*`

and press *enter/return.*

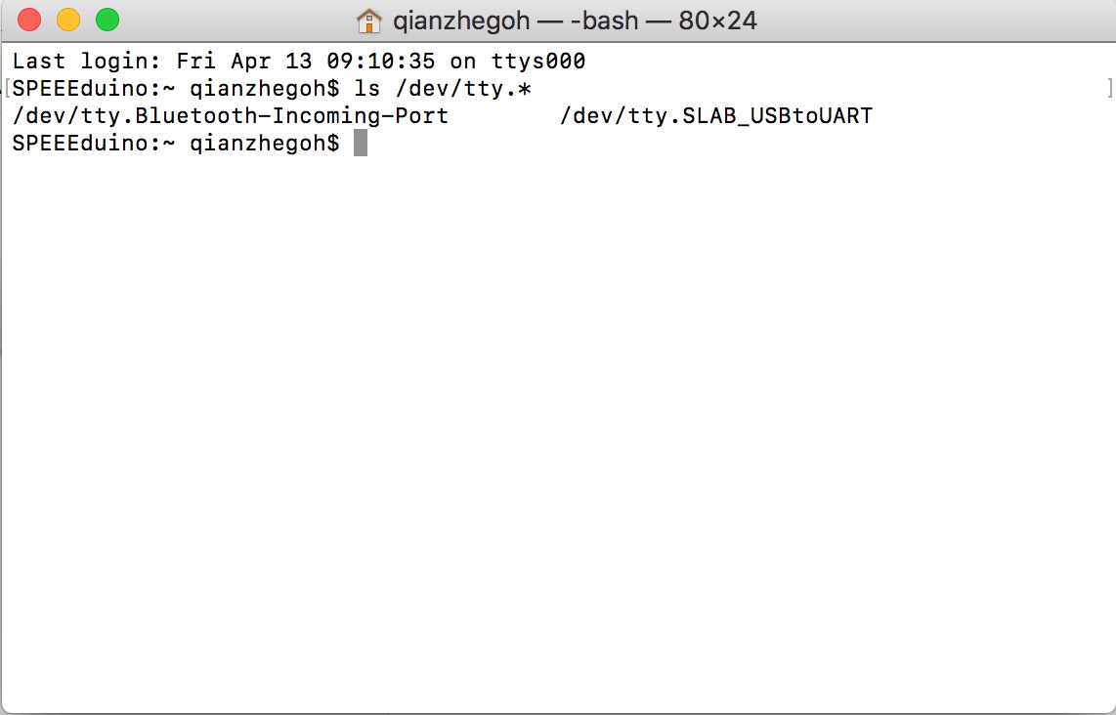
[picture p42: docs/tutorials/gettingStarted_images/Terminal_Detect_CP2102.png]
Terminal detect CP2102


You should see the device called `/dev/tty.SLAB_USBtoUART` appear.

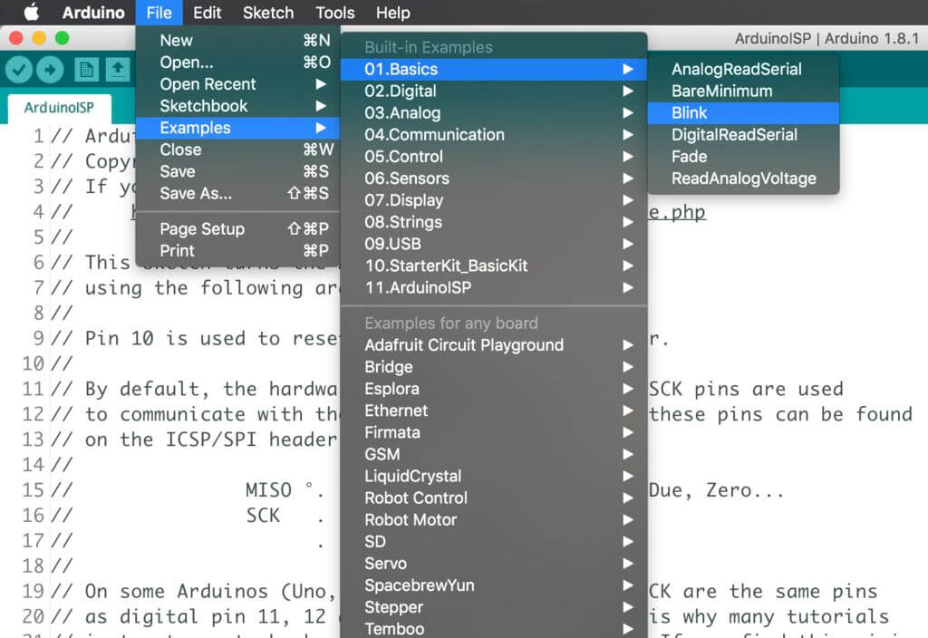
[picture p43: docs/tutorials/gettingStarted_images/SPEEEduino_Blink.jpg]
SPEEEduino_Blink


After you see the device appear, now we can start doing something basic! Launch your Arduino IDE, go to
`File -> Examples -> 01. Basics -> Blink`
Blink is a very simple example code included in the Arduino IDE. Due to the resemblance of the SSTuino with the Arduino (especially the Uno), any code that can be used with the Arduino Uno can be used with the SSTuino, with the exception that the SSTuino has a WiFi module attached. It is normally also the example code I use to check if the device is working.

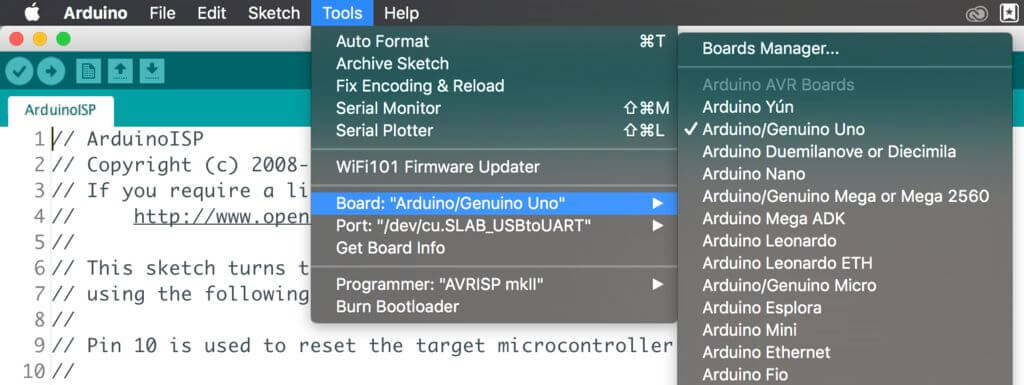
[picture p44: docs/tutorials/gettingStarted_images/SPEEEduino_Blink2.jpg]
SPEEEduino_Blink2


Before uploading the example code, make sure that you have selected the Arduino Uno as the device. Again, this is due to the resembalance of the SSTuino with the Arduino Uno, and most code that can be run on that platorm can also be run on the SSTuino.

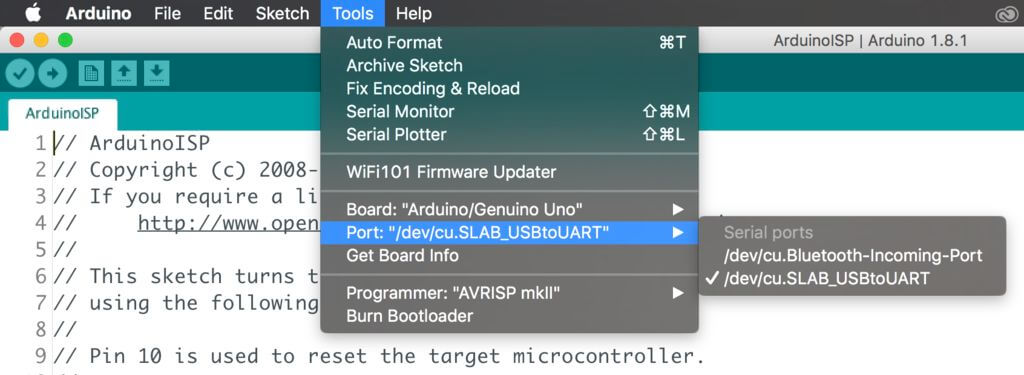
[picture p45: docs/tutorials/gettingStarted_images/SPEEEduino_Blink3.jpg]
SPEEEduino_Blink3


Also, please make sure that you have the correct port as shown above. Since this board is designed for SST, and used in the MacOS environment, the port that appears should be the same as shown in the picture above.

Now you can upload your code and you should see your onboard LED blinking! Have fun!

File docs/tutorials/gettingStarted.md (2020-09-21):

---
title: Setup
date: 2019-04-18
author: Goh Qian Zhe
---

# Getting started with the SSTuino

SSTuino is an easy to use Wi-Fi enabled microcontroller, designed and fabricated by SST Alumni. Users can write programs to connect or control things over the Internet. It is derived from the SPEEEduino 1.1 with some improvements.

This tutorial is a simple guide on how to get started with the SSTuino.

> Note: This article was last updated on 25th October 2019.

## Setting up...

**Note**: Please take your time and carefully go through this tutorial as it is the most crucial step to get your product working. It is also recommended to set this up before the SSTuino lessons starts with your parents to allow the smoothest possible experience. Learning devices with **parental control** will need to have their parents approve the driver installation.

Here are a list of things you require to go through this tutorial.

1. Your learning device
2. An active internet connection
3. The SSTuino Innovator's Kit

## Installation of the CP2102 Driver

We are using the NEU (New Enhanced UART) for our SSTuino. It is our custom made CP2102 USB to serial converter for the computer to "talk" to the SSTuino. To use the NEU with the MacOS, a firmware is reqruied to be installed.

### Installation for MacOS

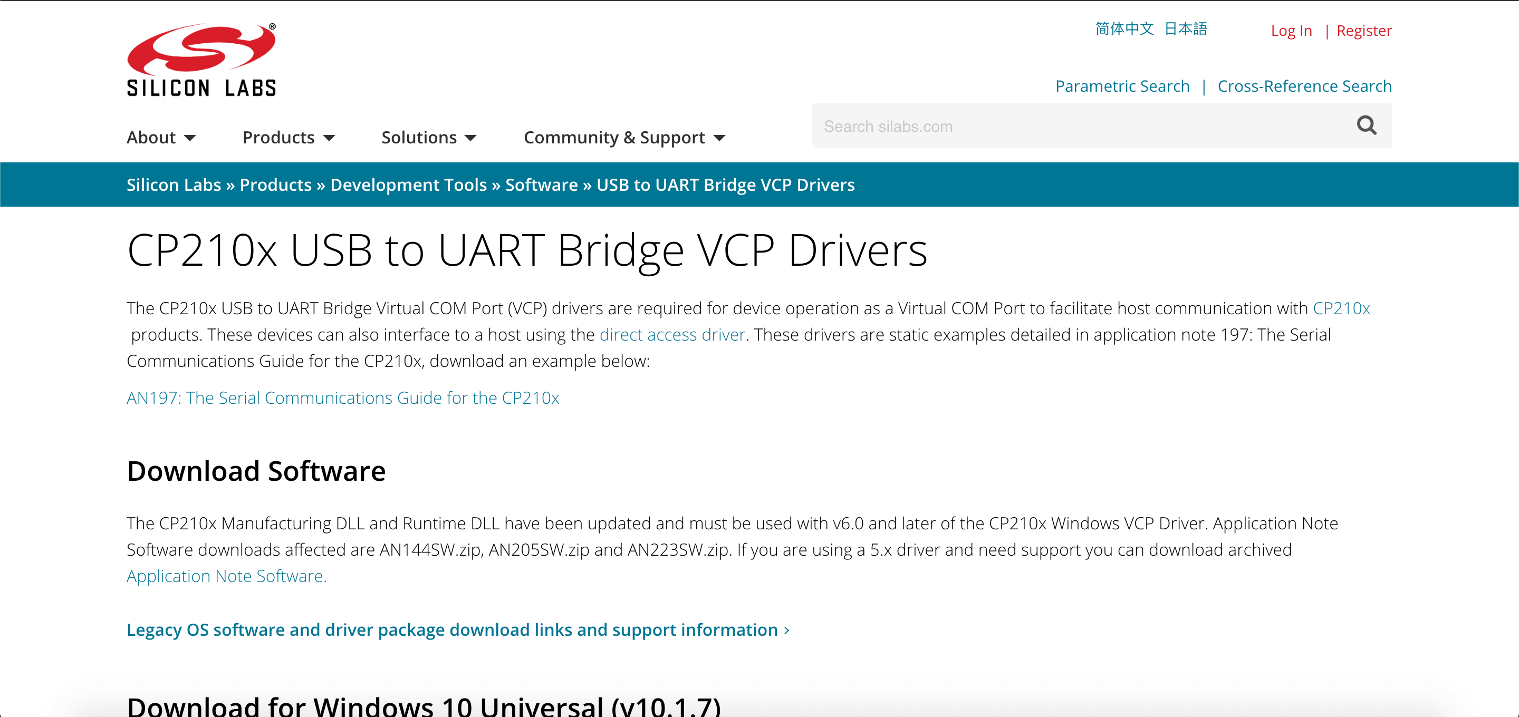
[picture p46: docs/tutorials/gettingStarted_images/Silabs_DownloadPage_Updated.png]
Silabs_DownloadPage_Updated


For MacOS users, the Silicon Labs driver has to be manually downloaded and installed. The driver can be downloaded here: [https://www.silabs.com/products/development-tools/software/usb-to-uart-bridge-vcp-drivers](https://www.silabs.com/products/development-tools/software/usb-to-uart-bridge-vcp-drivers)

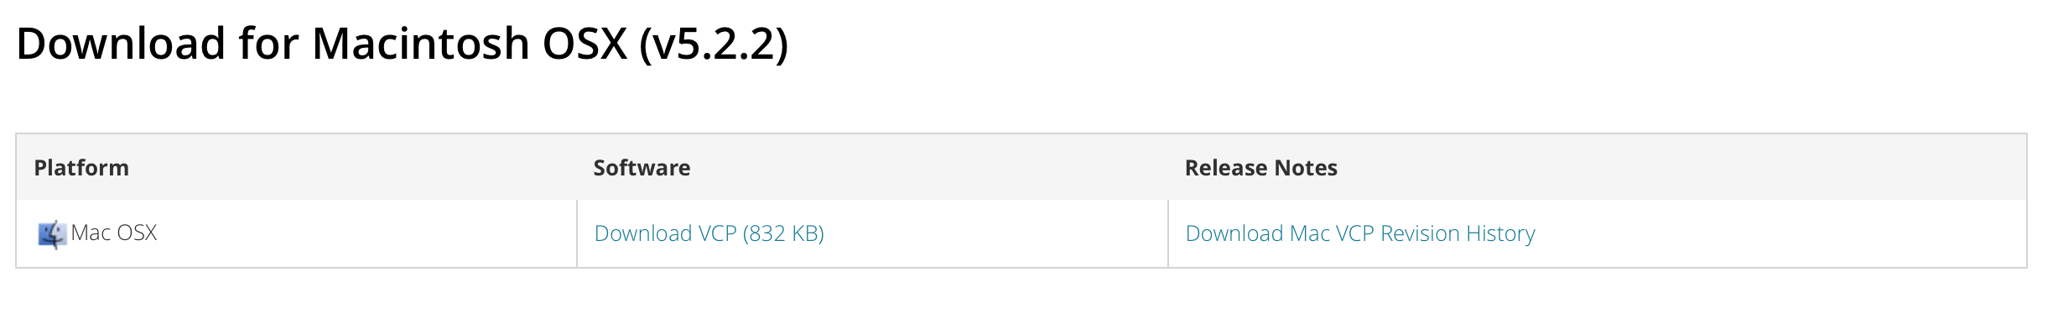
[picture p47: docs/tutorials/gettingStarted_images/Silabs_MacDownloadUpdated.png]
Silabs_MacDownloadUpdated


Navigate to this area and download the driver. After the driver has been downloaded, launch the `SiLabsUSBDriverDisk.dmg` located inside the folder you have downloaded. You will need to run the `Install CP210x VCP Driver` app, as demonstrated below: 

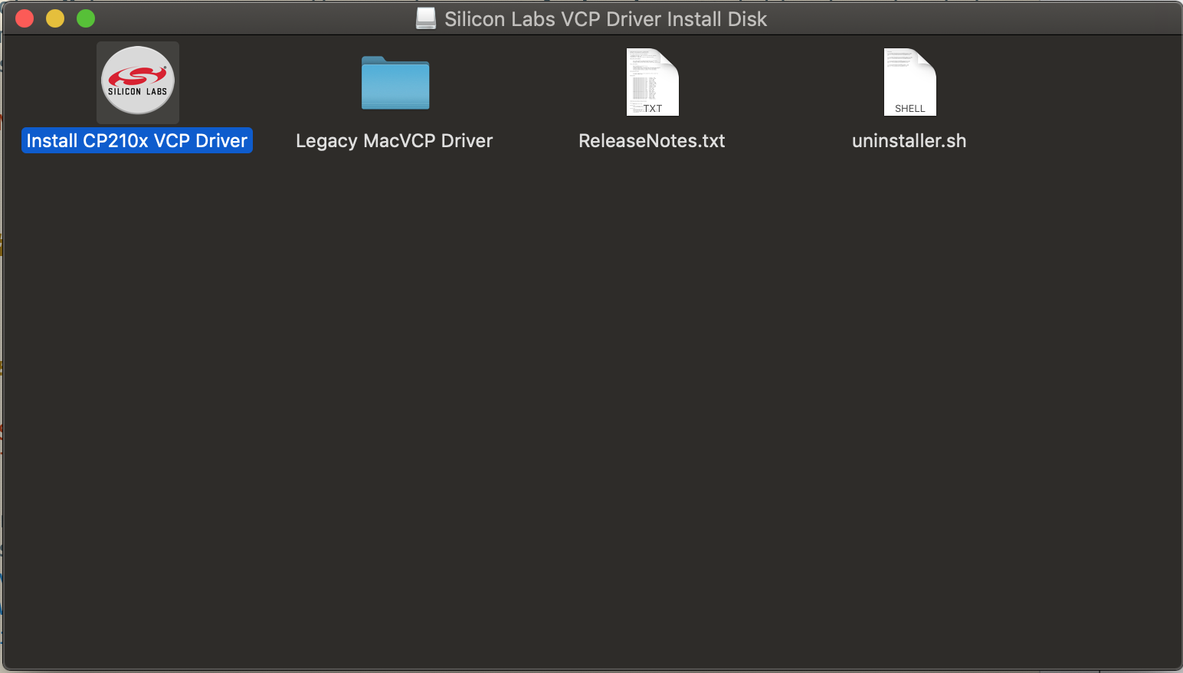
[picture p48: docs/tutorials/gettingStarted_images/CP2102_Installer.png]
CP2102_Installer


Follow the instructions from the installation app. Note that you will be prompted to enter your password.

Silabs_Install

## Installation of the Arduino IDE

Arduino.cc Download Page

- Go to the the downloads page here: [https://www.arduino.cc/en/Main/Software](https://www.arduino.cc/en/Main/Software)
- Download the version of the application you require.
    - For MacOS users download the Mac OS X version 10.8 Mountain Lion and newer. For MacOS Catalina users, please download the newest version available, as versions before 1.8.10 will not work with MacOS Catalina.

After download of the zip file from the Arduino website, simply copy the .app file into your **Applications** folder. 

>Note: Make sure you copy the app to your **Applications** folder for elevated admistrative rights. Those learning devices with parental controls will have a password prompt for administrative access.

MacOS prompt

In any event the system asks you whether to open the app, just click open.

### Installation of the SSTuino Companion Library

We have some additional examples that are specially catered for the SSTuino. 

First, we need to install a library to your Arduino IDE. Simply copy and paste this command into your Terminal:

```sh
curl -fsSL https://sstuino.fourier.industries/library_install.sh | bash
```

...and hit enter! The installation should complete without any errors. You can always update your library by running the same command if there is a new release of the library available.

## Ready to roll?

After these two important things are installed, you should be pretty much ready for our further tutorials! If you are ready, proceed on to the next tutorial: [Hello World!](helloWorld.md)

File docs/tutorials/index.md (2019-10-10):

---
title: Tutorials
date: 2019-04-18
author: Goh Qian Zhe
---

# Tutorials

Tutorials can help you get started with using your SSTuino, or bring you further.

## Before you start

Before you begin playing around with the SSTuino kit here are some things to do:

* [Click here to access list of items provided in your kit.](partsList.md)
* [Click here to setup your laptop and SSTuino kit ready for use.](gettingStarted.md)
* [Click here to make your SSTuino come to life!](helloWorld.md)

## Sec 1 Tutorials

* [How to not *burn* your LEDs! - Explanation of components inside your SSTuino Innovator's Kit.](Sec1/electronicBasics.md)
* [My first circuit! - Setting up TinkerCAD and creating a few basic circuits without programming.](Sec1/tinkercad.md)
* [Introduction to Arduino Programming - Basic Arduino programming and some explanation.](Sec1/sstuinoProgram.md)
* [My SSTuino can read! - DigitalRead and DigitalWrite](Sec1/digitalRead.md)
    * This tutorial covers:
        * Pull up resistors
        * Push Buttons
        * If/Else Statements
        * Flashing Lights
        * Variables
        * Drag Race / AND and OR Operators
        * Toggle Switch
* [Data at my fingertips! - AnalogRead and AnalogWrite](Sec1/dataInput.md)
    * This tutorial covers:
        * Potentiometer
        * Light Dependent Resistor/Photoresistor
        * Ultrasonic Distance Sensor
        * TMP36 Temperature Sensor
* [The SSTuino can connect to the internet?! - Interfacing the SSTuino with Adafruit.io](Sec1/sstuinoIoT.md)
    * This tutorial covers:
        * [What is the Internet of Things (IoT) all about?](Sec1/sstuinoIoT.md/#what-is-the-internet-of-things-iot-all-about)
        * [Creating your Adafruit.io account](Sec1/sstuinoIoT.md/#creating-your-adafruitio-account)
        * [Connecting SSTuino to Adafruit.io](Sec1/sstuinoIoT.md/#connecting-sstuino-to-adafruitio)
        * [MQTT Example](Sec1/sstuinoIoT.md/#mqtt-example)
        * [Controlling your SSTuino!](Sec1/sstuinoIoT.md/#controlling-your-sstuino)
        * [Connect SSTuino to Thunkable!](/Sec1/sstuinoIoT.md/#connect-sstuino-to-thunkable)

## Additional Tutorials

Coming soon!

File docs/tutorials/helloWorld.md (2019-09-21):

---
title: Hello, World!
date: 2019-05-26
author: Goh Qian Zhe
---

# Hello, World!

So, you have just completed the setup of your computer and familarised yourself with the SSTuino Kit. What would be the next step?

**Before you begin**

Do not plug anything wrongly or [expensive failures](https://youtu.be/WFZwI10HEsw?t=591) may happen...

## Connecting up your SSTuino

1. Insert the CP2102 and WiFi Chip as shown.
plugIn
2. Plug in the cable to the CP2102 and your computer (mac).
3. Watch it light up!

## Preflight Checks...

We first check if the USB to serial converter is detected by System Information. If it is detected, it would look something like this:

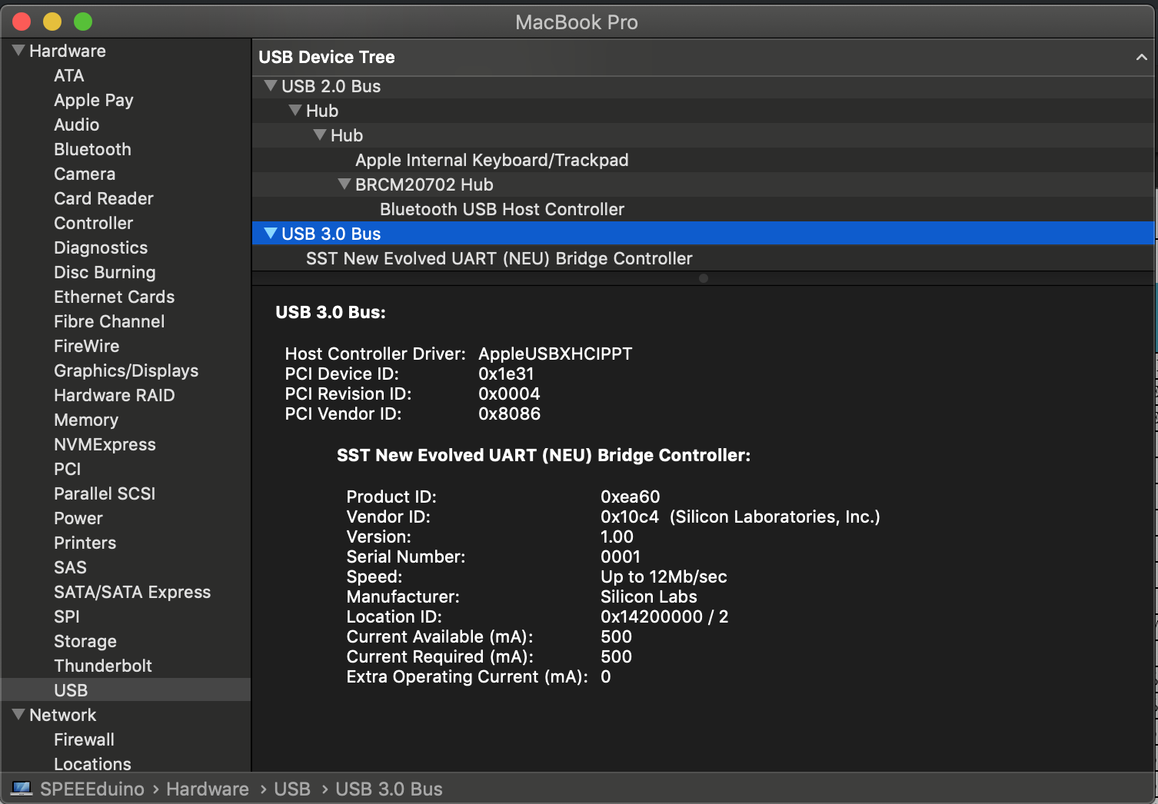
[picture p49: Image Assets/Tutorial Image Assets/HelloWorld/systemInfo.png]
System Info


Nice name right?

We first check if the USB to serial converter can be detected. To do so, launch the Terminal app from your mac and type in this line:

`ls /dev/tty.*`

and press *enter/return.*

Terminal detect CP2102

You should see the device called `/dev/tty.SLAB_USBtoUART` appear.

## Almost there!

You are almost ready to launch! But first, open the Arduino app you downloaded from [this tutorial](https://d3lta-v.github.io/SSTuino/tutorials/gettingStarted.html).

SPEEEduino_Blink

Once the app is open, go to:

`File -> Examples -> 01. Basics -> Blink`

Blink is a very simple example code included in the Arduino IDE. Due to the resemblance of the SSTuino with the Arduino (especially the Uno), any code that can be used with the Arduino Uno can be used with the SSTuino, with the exception that the SSTuino has a WiFi module attached. It is normally also the example code I use to check if the device is working.

SPEEEduino_Blink2

Before uploading the example code, make sure that you have selected the Arduino Uno as the device. 

SPEEEduino_Blink3

Also, please make sure that you have the correct port as shown above. Since this board is designed for SST, and used in the MacOS environment, the port that appears should be the same as shown in the picture above.

Now you can upload your code and you should see your onboard LED blinking! Have fun!

## But wait, there's more!

How about I change how the LED blinks?

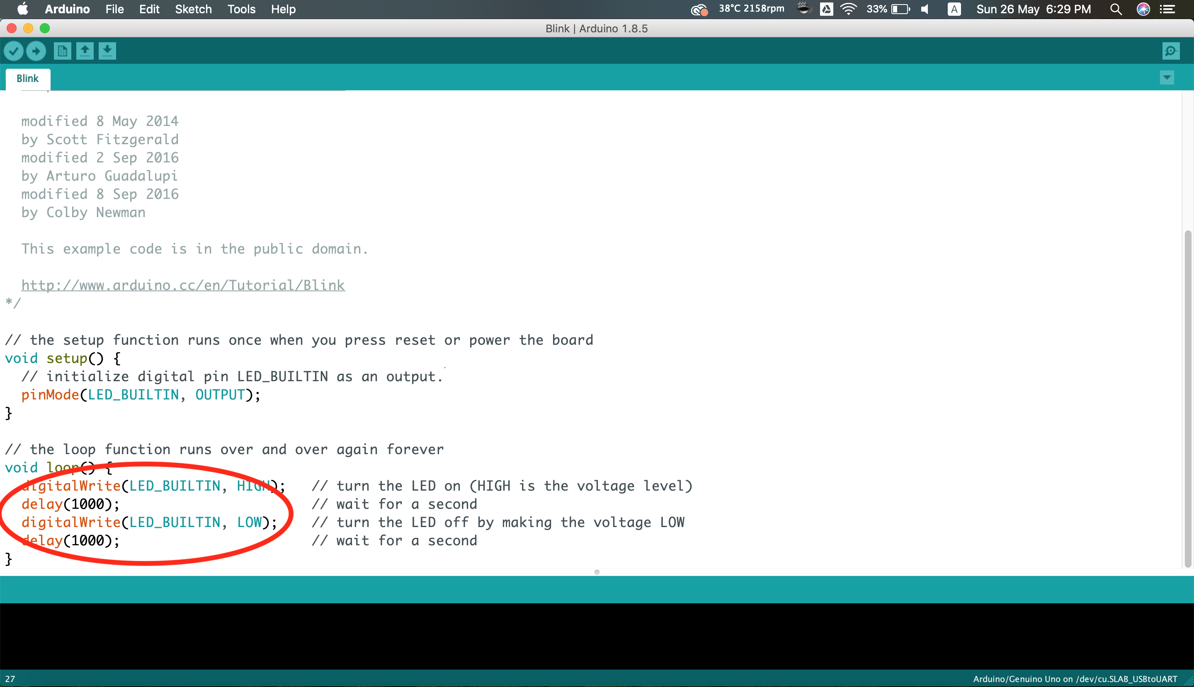
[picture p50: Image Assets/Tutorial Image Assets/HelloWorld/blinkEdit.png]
blinkEdit


In the circled section you can see a few lines of code.

```C++
void loop() {
  digitalWrite(LED_BUILTIN, HIGH);   // turn the LED on (HIGH is the voltage level)
  delay(1000);                       // wait for a second
  digitalWrite(LED_BUILTIN, LOW);    // turn the LED off by making the voltage LOW
  delay(1000);                       // wait for a second
}
```
So what did the `HIGH` and `LOW` mean? Digital electronics only have 2 states. Think of it as a switch. When it is `HIGH` it means that it is turned **on**. When it is `LOW`, it is turned **off**.

The `delay(1000);` tells the microcontroller to wait for a second. This means that this entire section of code tells the LED to turn on for 1 second and then turn off for 1 second!

 The `1000` is in miliseconds, and you can change that value, before uploading the code again! Bear in mind that if you have too small or too large of a number, you would either not see the LED not doing anything, or takes ages to do something.

*So, have fun and enjoy the tutorials that lie ahead!*

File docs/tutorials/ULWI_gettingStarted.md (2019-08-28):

---
title: [Advanced] ULWI Setup
date: 2019-08-28
author: Goh Qian Zhe
---

# Getting started with ULWI

**Ultra Light Wi-Fi Interface Firmware - ULWI**

The ULWI firmware aims to convert the original AT command line interface of the ESP8266 into an extremely lightweight and robust command-reply style interface, with a command set inspired by assembly mnemonics.

This firmware is developed for devices that intend to interface to the ESP8266 in a master-slave configuration, whereas the device in question acts as the master while the ESP8266 acts as the slave.

This firmware is designed to be optimised for the SPEEEduino and SSTuino family of Arduino-ESP8266 hybrid boards, with a 9600/8-N-1 software serial link connecting the ATmega328 with the ESP8266, with an ATmega328P acting as the master to the ESP8266.

## What you will need
- Your mac (this tutorial was written for MacOS, testing not done for Windows yet.)
- SSTuino
- CP2102 NEU

## Installing dependancies...

We will need to install some stuff before we can continue.

### Installing Mongoose OS Tools

First, install Homebrew by copying this into your Mac Terminal:

`/usr/bin/ruby -e "$(curl -fsSL https://raw.githubusercontent.com/Homebrew/install/master/install)"`

Next, install and initiate mos tool using these commands in the Terminal:

`brew tap cesanta/mos`

`brew install mos`

`mos`

This should appear:

mos

### Installing Coolterm

Download coolterm here: https://freeware.the-meiers.org/

Install and open the app.

### Connecting the board

With your Rev A SSTuino, connect the NEU to the ESP pins:

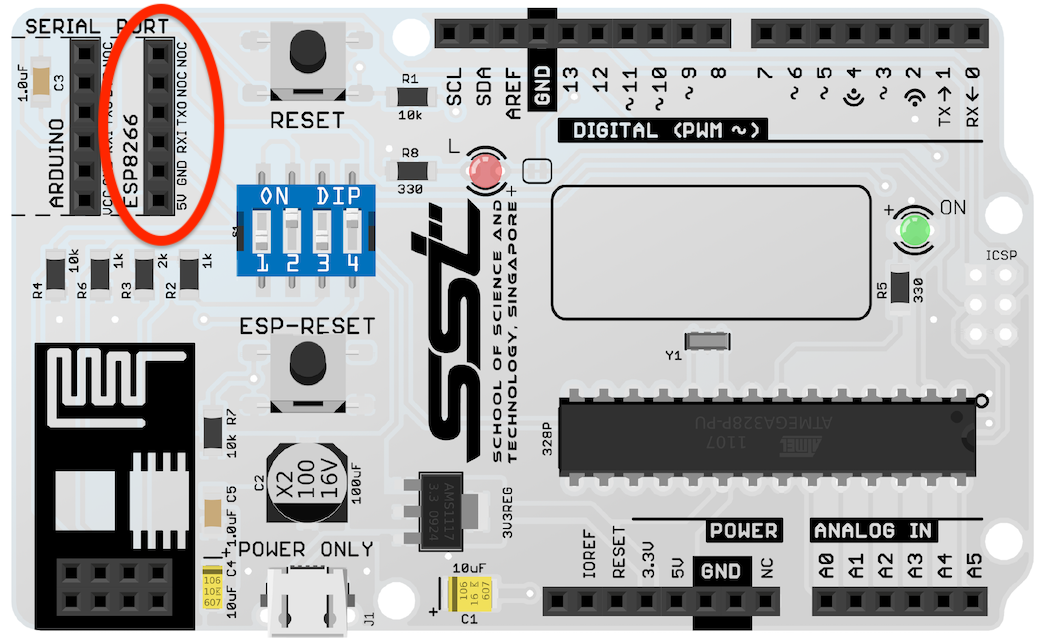
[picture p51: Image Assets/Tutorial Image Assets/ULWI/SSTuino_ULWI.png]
LMAO


For the DIP switches, set it to ON, ON, OFF, OFF

### Cloning the GitHub Repo

For new users, I recommend downloading the GitHub Desktop App.

Create an account in Github.com and go to the ULWI repo: https://github.com/d3lta-v/ULWI 

At the top right hand corner, there is the clone or download option. With the Github Desktop installed, click on Open in Desktop.

### Flashing Firmware

After the repo has been cloned, run the flash.command file and it should be working properly.

### Connecting with CoolTerm

Open CoolTerm and connect to the SLAB_USBtoUART thing, then select baud rate 115200.

you can start testing...

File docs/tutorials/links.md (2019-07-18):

---
title: Useful Links
date: 2019-07-17
author: Goh Qian Zhe
---

# Useful Links

* Arduino Website - [https://www.arduino.cc/](https://www.arduino.cc/)
* TinkerCAD - [https://www.tinkercad.com](https://www.tinkercad.com)
* Thunkable - [https://thunkable.com/#/](https://thunkable.com/#/)
* CP2102 Drivers - [https://www.silabs.com/products/development-tools/software/usb-to-uart-bridge-vcp-drivers](https://www.silabs.com/products/development-tools/software/usb-to-uart-bridge-vcp-drivers)
* Blockly Games - [https://blockly-games.appspot.com/](https://blockly-games.appspot.com/)
* Sparkfun Website - [https://www.sparkfun.com/](https://www.sparkfun.com/)
* Adafruit Website - [https://www.adafruit.com/](https://www.adafruit.com/)
* SG Botic (Local arduino store) - [https://www.sgbotic.com/](https://www.sgbotic.com/)
* RS Online Singapore - [https://sg.rs-online.com/web/](https://sg.rs-online.com/web/)
* Element 14 Singapore - [https://sg.element14.com/](https://sg.element14.com/)
* Continental Electronics (Physical Store, located at Basement 1, Sim Lim Tower (near Bugis/Rochor/Jalan Besar MRT)) - [http://www.continental.sg/](http://www.continental.sg/)

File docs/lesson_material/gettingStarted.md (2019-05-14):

---
title: Setup
date: 2019-04-18
author: Goh Qian Zhe
permalink: /gettingStarted/
---
# Getting started with the SSTuino

SSTuino is an easy to use Wi-Fi enabled microcontroller, designed and fabricated by SST Alumni. Users can write programs to connect or control things over the Internet. It is derived from the SPEEEduino 1.1 with some improvements.

This tutorial is a simple guide on how to get started with the SSTuino.

## Setting up...

**Please take your time and carefully go through this tutorial as it is the most crucial step to get your product working.**

**For Learning Devices with parental control, not to worry, you can do this tutorial out of class with your parents.**

Here are a list of things you require to go through this tutorial.

1. Firstly, and most importantly, yourself.
2. Your learning device or computer.
3. An active internet connection.
4. The SSTuino kits.

## Installation of the Arduino IDE

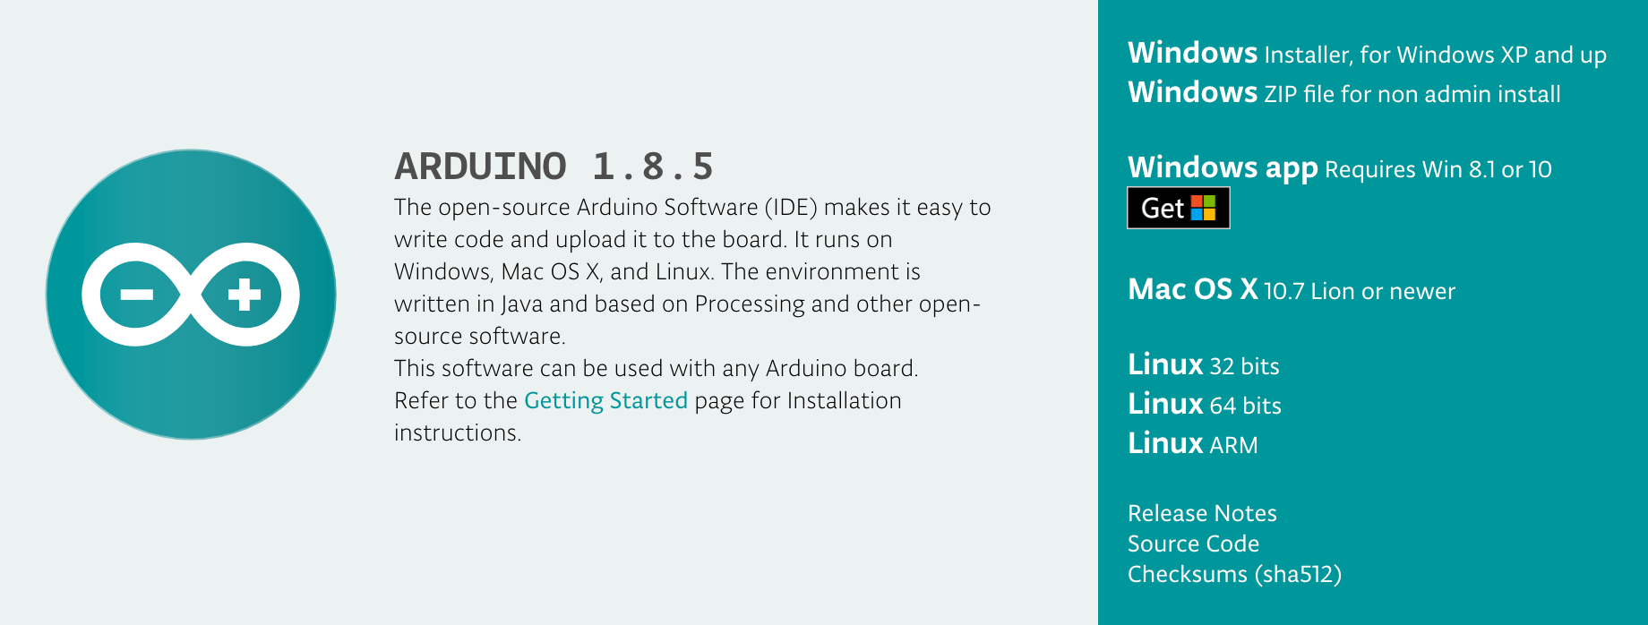
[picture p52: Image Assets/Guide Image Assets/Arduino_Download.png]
Arduino.cc Download Page


 - Go to the the downloads page here: [https://www.arduino.cc/en/Main/Software](https://www.arduino.cc/en/Main/Software)
 - Download the version of the application you require.
    - For MacOS users download the Mac OS X version (10.7) and newer.
    - For Windows users, there are quite a few options:
       - For all devices, you can download either the installer or the zip file. I personally prefer the zip file (as it can be done as a non-admin install, and it is convinent.) However, it is your personal preference for the installation method.
       - Alternatively, for Windows 8.1 and 10, you can go to the Microsoft Store and download it.

### Installation for MacOS
After download of the zip file from the Arduino website, simply copy the .app file into your *Applications* folder. 

MacOS prompt

In any event the system asks you whether to open the app, just click open

## Installation of the CP2102 Driver
We are using the CP2102 USB to serial converter for our SSTuino.

### Installation for MacOS

Silabs_DownloadPage_Updated

For MacOS users, the Silicon Labs driver has to be manually downloaded and installed. The driver can be downloaded here: [https://www.silabs.com/products/development-tools/software/usb-to-uart-bridge-vcp-drivers](https://www.silabs.com/products/development-tools/software/usb-to-uart-bridge-vcp-drivers)

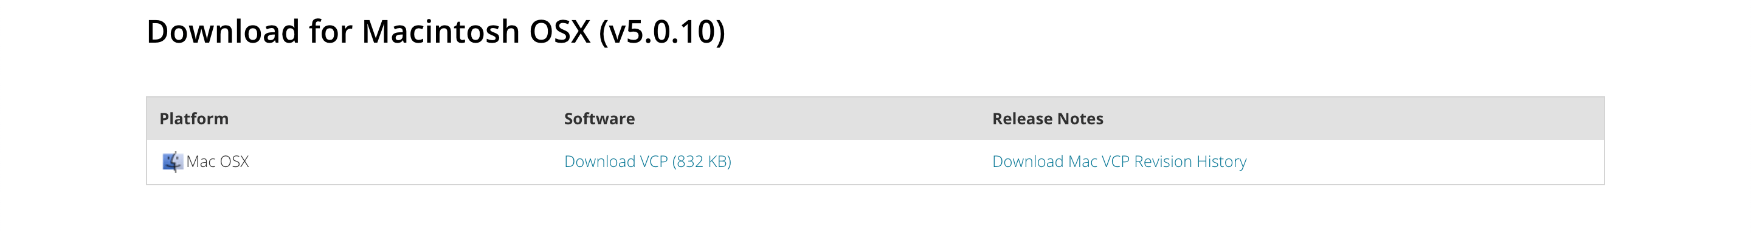
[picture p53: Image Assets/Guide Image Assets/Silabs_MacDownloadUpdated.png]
Silabs_MacDownloadUpdated


Navigate to this area and download the driver.

Silabs_Download_Folder

After the driver has been downloaded, *unzip* the file and launch the **disk image.** You will now see three files, as pictured below. Run the package (.pkg) file.

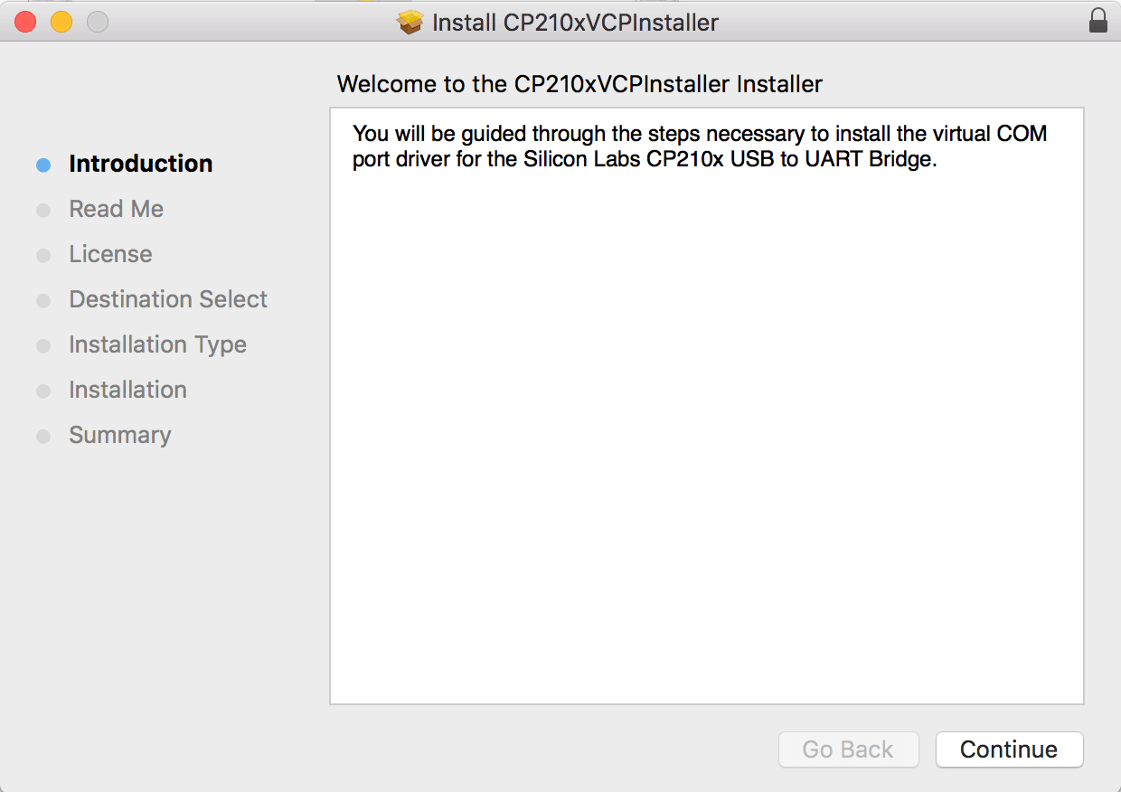
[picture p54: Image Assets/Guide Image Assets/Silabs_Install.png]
Silabs_Installation_App


Install the drivers.  **This requires elevated admin rights (devices with parental controls will not be able to install unless an admin allows the installation.)**

During installation, you may encounter a pop-up which would ask you to go to your system preferences. Click ok first.

SiLabs Prompt

While the installer is running, go to System Preferences -> Security and Privacy and allow the Silicon Labs prompt. 

Restart Mac

After the installation has finished, simply restart your mac.

## Setting up your SSTuino with your Mac

Your teacher will guide you through this process. You will need your SSTuino Kit with you.

To check if the USB to serial converter can be detected, go to Terminal and type in this line

`ls /dev/tty.*`

and press *enter/return.*

Terminal detect CP2102

You should see the device called `/dev/tty.SLAB_USBtoUART` appear.

SPEEEduino_Blink

After you see the device appear, now we can start doing something basic! Launch your Arduino IDE, go to
`File -> Examples -> 01. Basics -> Blink`
Blink is a very simple example code included in the Arduino IDE. Due to the resemblance of the SSTuino with the Arduino (especially the Uno), any code that can be used with the Arduino Uno can be used with the SSTuino, with the exception that the SSTuino has a WiFi module attached. It is normally also the example code I use to check if the device is working.

SPEEEduino_Blink2

Before uploading the example code, make sure that you have selected the Arduino Uno as the device. Again, this is due to the resembalance of the SSTuino with the Arduino Uno, and most code that can be run on that platorm can also be run on the SSTuino.

SPEEEduino_Blink3

Also, please make sure that you have the correct port as shown above. Since this board is designed for SST, and used in the MacOS environment, the port that appears should be the same as shown in the picture above.

Now you can upload your code and you should see your onboard LED blinking! Have fun!

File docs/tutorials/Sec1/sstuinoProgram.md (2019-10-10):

---
title: Introduction to Arduino Programming
date: 2019-07-18
author: Goh Qian Zhe
---

# Introduction to Arduino Programming

So, let us move on into the programming stage of the SSTuino Innovator's Kit!

## Table of Contents

* [Virtual Programming](#virtual-programming)
* [Pin 13](#pin-13)
* [Blink!](#blink)
* [How does the code work?](#how-does-the-code-work)
* [It WORKS!!!](#it-works)

## Virtual Programming

Before we go into programming with the Arduino app, let us take things slow with the coding functionality on TinkerCAD!

The Arduino programming language is very simillar to the [C/C++ Language](https://en.wikipedia.org/wiki/C%2B%2B) and are actually C/C++ functions that can be called into your code. When the code is uploaded onto the SSTuino, the compiler inside the Arduino IDE will convert it to something that the microcontroller can read.

Create a new circuit on TinkerCAD, and set it up like this:

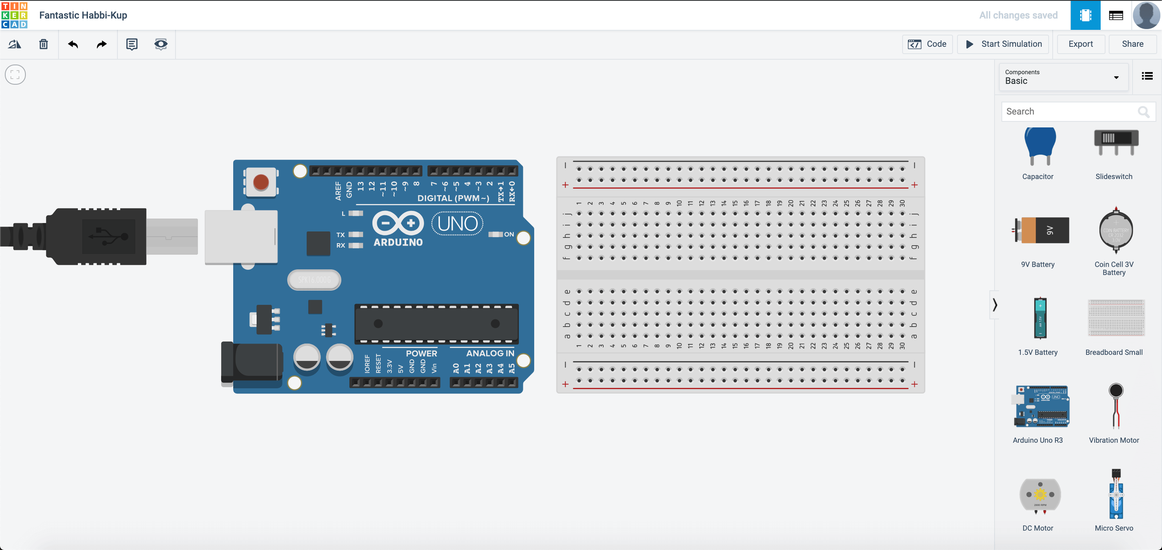
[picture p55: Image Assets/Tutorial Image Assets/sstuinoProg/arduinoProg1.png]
arduinoProg1


Once you set it up and press start simulation, notice the LED on the Arduino blinking? Why does this happen?

arduinoProg2

The reason this happens is that TinkerCAD places in a sample code when you insert the Arduino into the circuit.

> Stop the simulation and press the **CODE** button. You should see something like this:

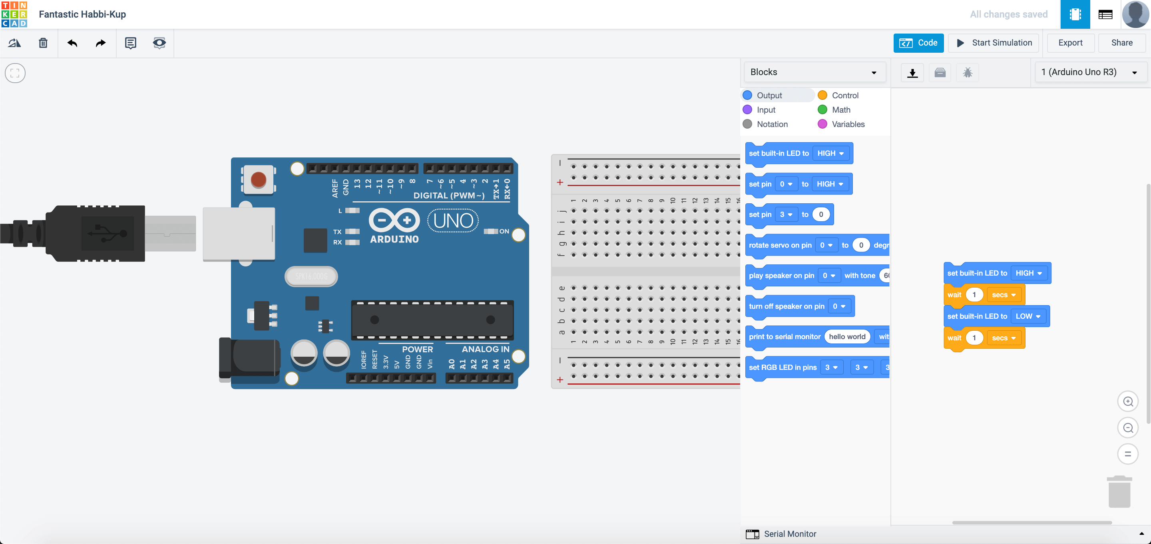
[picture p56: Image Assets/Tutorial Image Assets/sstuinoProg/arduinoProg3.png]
arduinoProg3


TinkerCAD is very simple to use as you can use block coding to program the Arduino. You would have had experience in block coding with Scratch, Thunkable and Blockly Games. The programming environment would be very simillar to those you had used before.

If you would like to program with text in TinkerCAD, you can also do so like this:

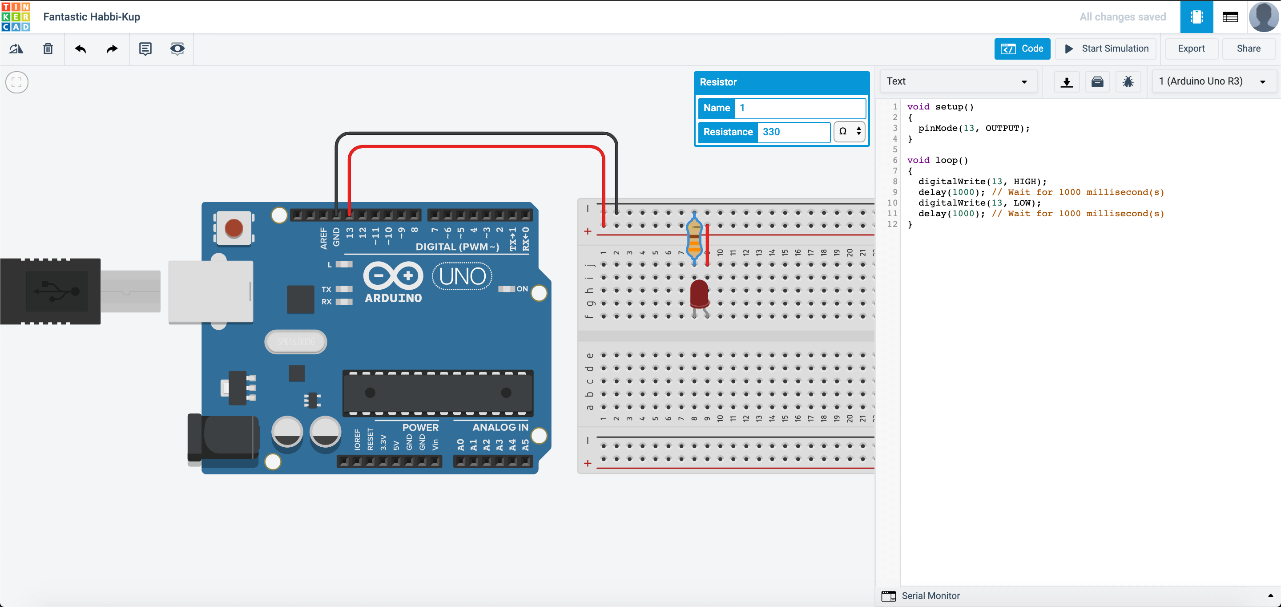
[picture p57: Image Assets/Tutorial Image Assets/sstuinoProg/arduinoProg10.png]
arduinoProg10


They also have another format called Blocks + Code. The text code changes according to the blocks that you place.

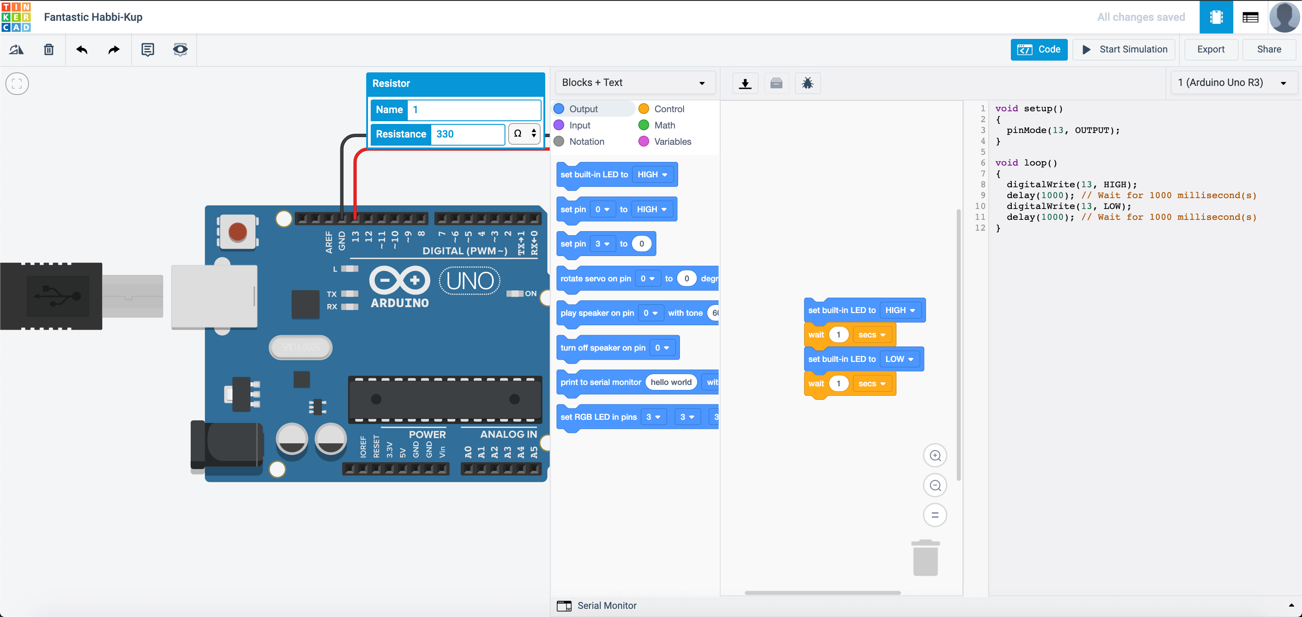
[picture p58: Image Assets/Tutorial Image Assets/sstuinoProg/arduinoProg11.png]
arduinoProg11


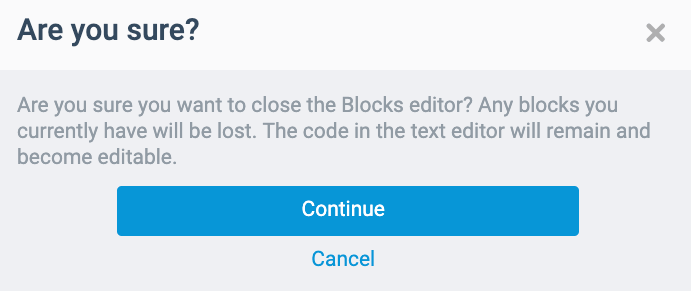
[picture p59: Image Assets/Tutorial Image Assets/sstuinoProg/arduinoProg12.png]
arduinoProg12
> **Note:** In TinkerCAD, when you program in blocks, the text that you coded will be deleted, and when you program in text, the blocks that you placed will be deleted when you change the programming mode. This is to prevent any internal application error with the website.

So what does this block of code do? It tells the Arduino to:

* Turn on the `built-in` LED for one second
* Turn off the `built-in` LED for one second

and it repeats all over until you turn off the circuit by unplugging the Arduino from the power source.

In programming, **HIGH** means to turn something on or give it power, while **LOW** means to turn something off or to not give it power. For this code, there are only **2 STATES, HIGH or LOW**. This means that it is either on or off and there is no value in between (either 1 or 0).

Now change the value of the `wait ___ seconds` to something that you like. What happens then?

## Pin 13

Now, let us connect up the circuit:

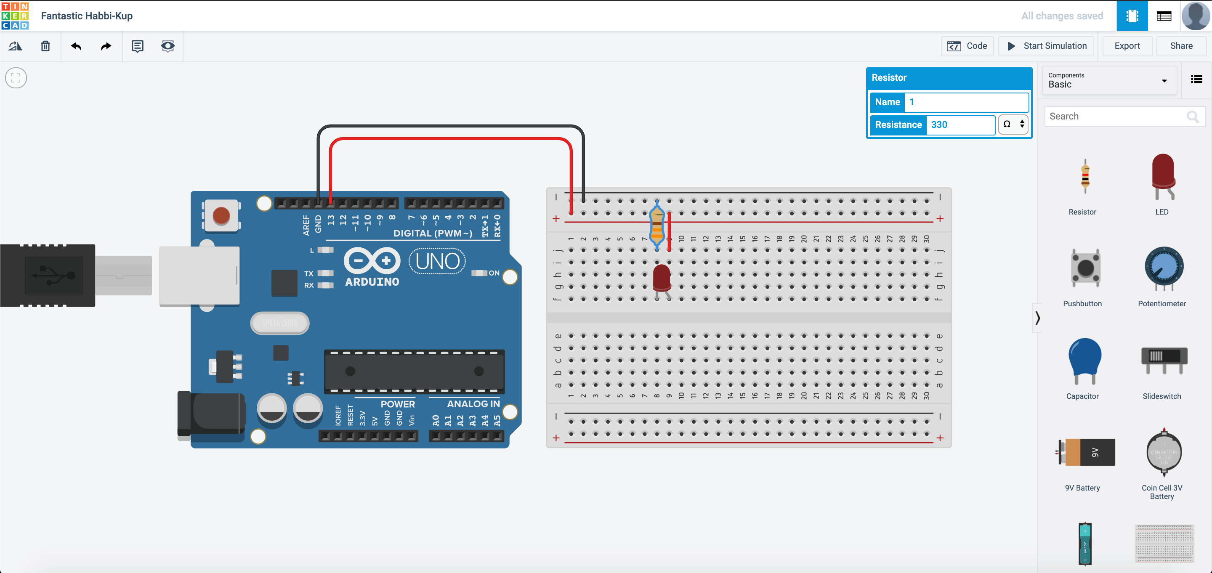
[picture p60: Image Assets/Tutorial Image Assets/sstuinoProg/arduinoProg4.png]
arduinoProg4


After you start simulation, it should look something like this:

arduinoProg5

*Wait a minute...* How come the LED attached turns on and off even though I did not program it? Well the reason behind it is that the `built-in` LED pin is also connected to pin 13. This means in the program, `LED_BUILTIN` is also pin 13.

## Blink!

In TinkerCAD, another awesome feature is the ability to download the program that you have coded just now! You just have to press the download button as shown here:

> Go to code, and press the download button

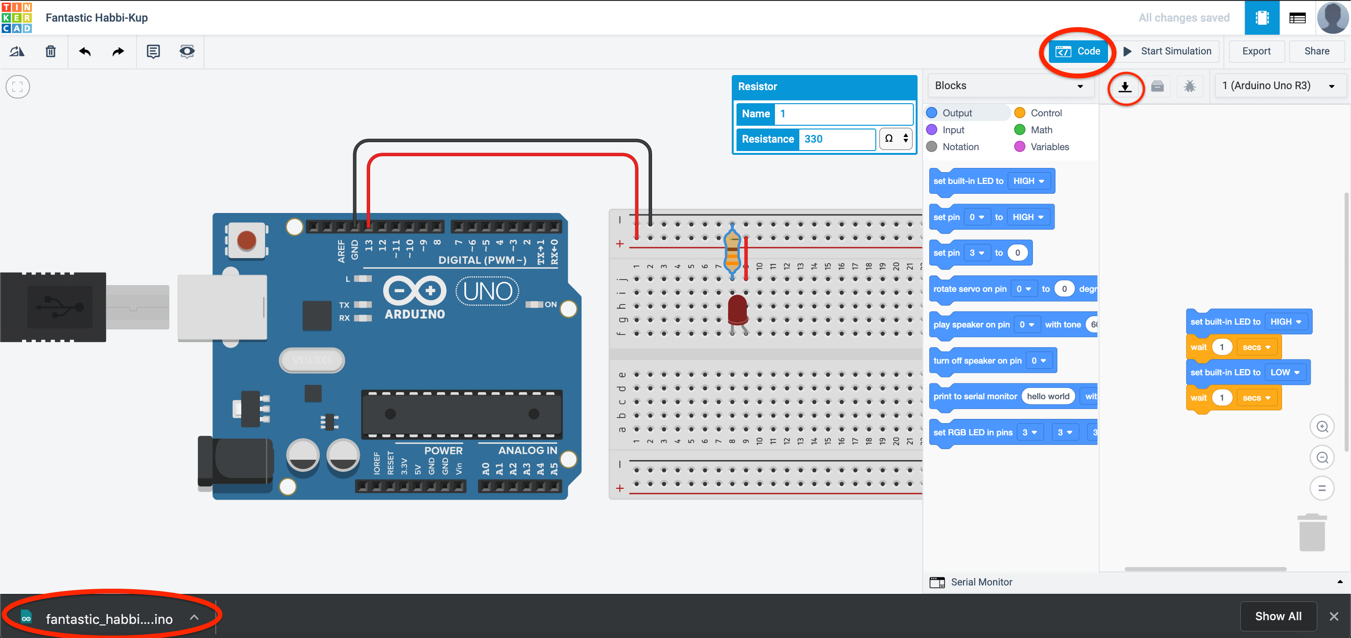
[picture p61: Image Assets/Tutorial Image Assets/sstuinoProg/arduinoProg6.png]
arduinoProg6


A `.ino` file will be downloaded on your mac and can be used on the Arduino IDE. Open the file and you would see this:

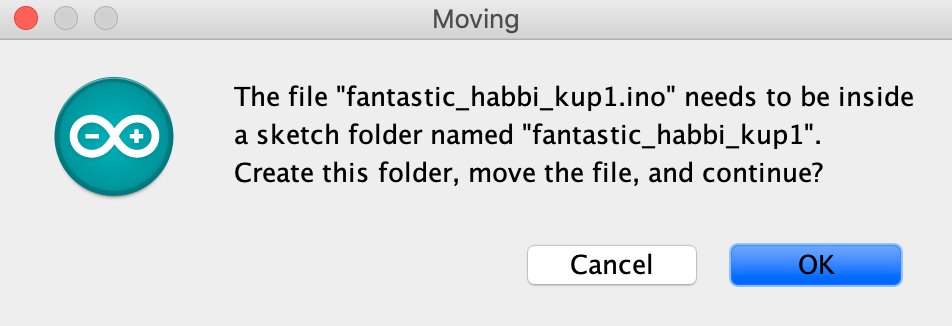
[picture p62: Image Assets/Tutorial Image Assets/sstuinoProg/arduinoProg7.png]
arduinoProg7


Click **OK**.

A folder will then be created and you will be able to see this code appear.

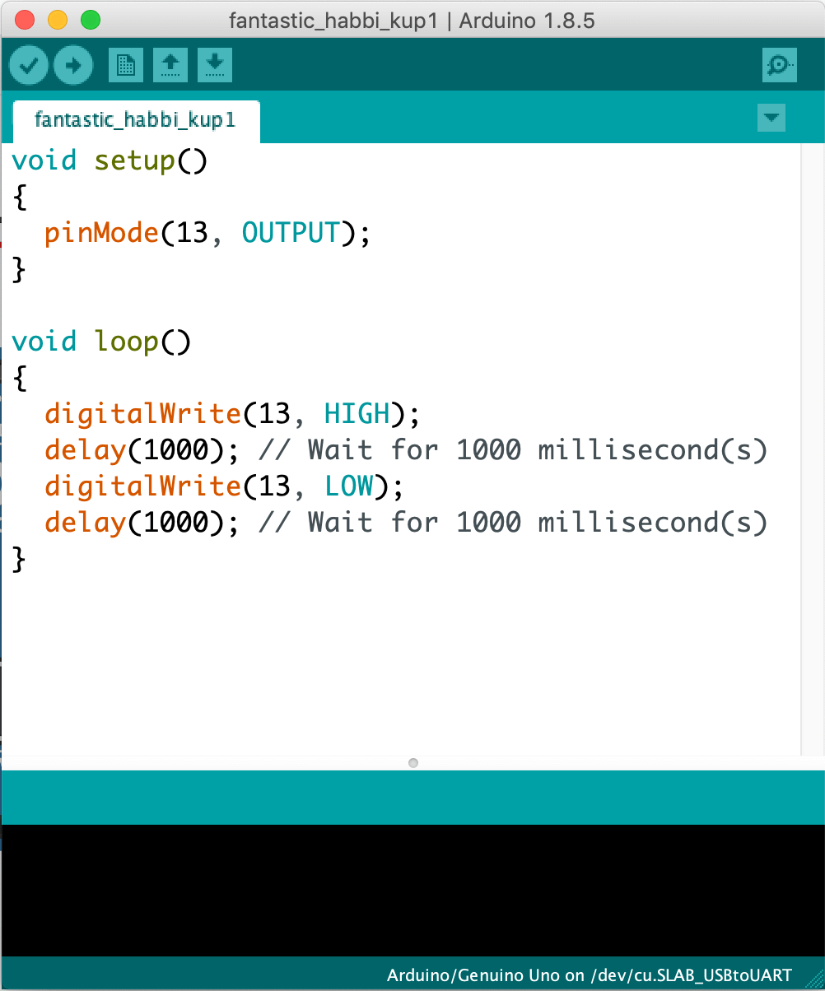
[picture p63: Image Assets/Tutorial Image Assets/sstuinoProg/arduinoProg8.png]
arduinoProg8


## How does the code work?

You would probably have noticed that this code looks rather different than the blocks you see in TinkerCAD. The Arduino app that you are using right now is called an **Integrated Development Environment** or **IDE** for short and is one of the places that you can program your SSTuino in.

For example, I use another IDE called Visual Studio Code to modify this website for you! (in [Markdown](https://en.wikipedia.org/wiki/Markdown))

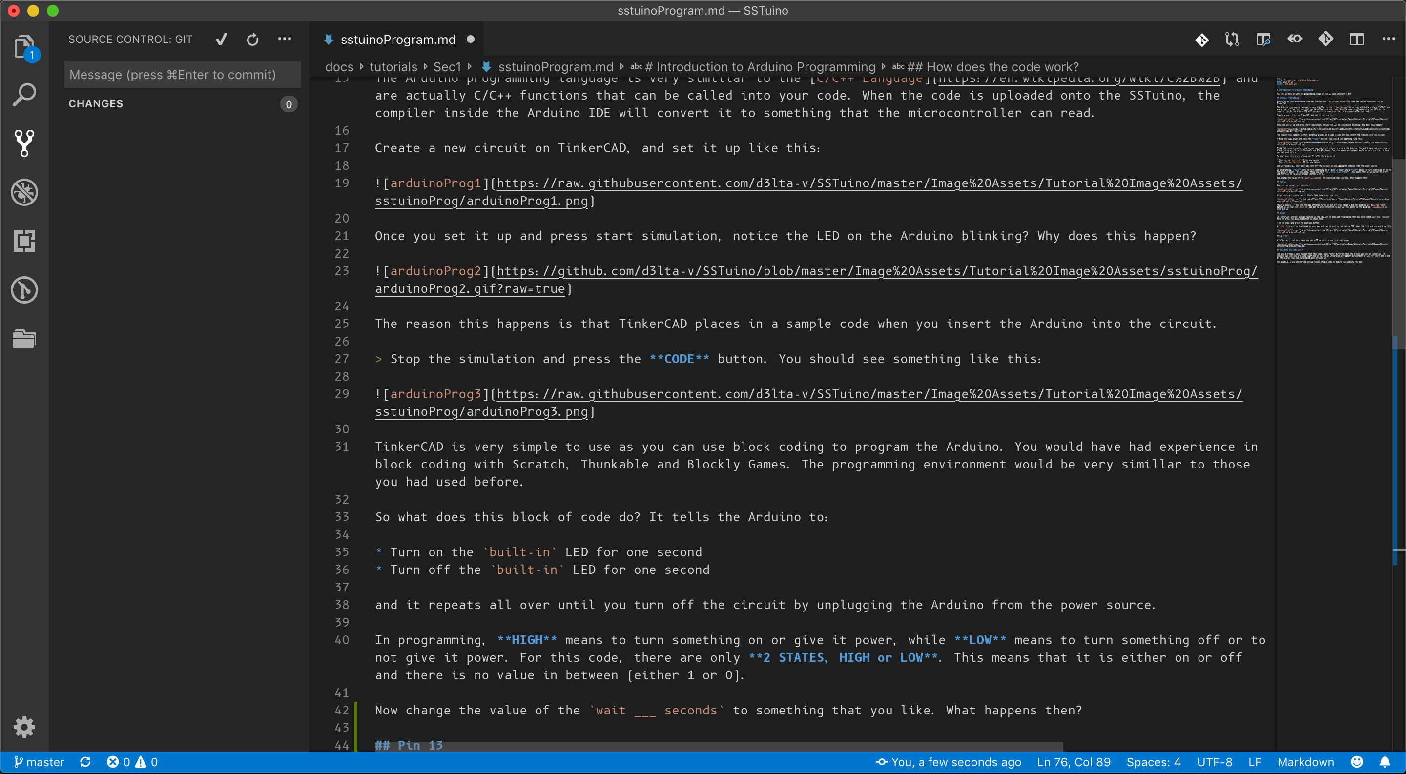
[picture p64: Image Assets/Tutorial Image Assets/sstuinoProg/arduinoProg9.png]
arduinoProg9


Let us analyse the code we see here

arduinoProg8

Here is an explanation on how most basic Arduino code works:

``` c++
// These two slashes indicate a comment
/* This also indicates a comment 
The brackets () indicate a function e.g. int main()
*/
void setup() //This is only run once when the device first powers up
{ //<- The curly brackets are very important. Place them carefully to avoid confusion.
    pinMode(13,OUTPUT); 
    /*
    Why is pinMode written as so? That is due to the practice of using camelCase for writing code.
    We declare pin 13 as the output pin. It can also be written as pinMode(LED_BUILTIN, OUTPUT).
    The state "OUTPUT" must be written in CAPITAL LETTERS.
    
    It is also very important to place a semicolon ";" when you finish your "sentence", just like
    your English sentences.
    */
    
}

void loop() //loop = runs forever till the end of time (or until you turn off the power)
{
  digitalWrite(13, HIGH);// Turn on pin 13
  delay(1000); // Wait for 1000 millisecond(s)
  digitalWrite(13, LOW);// Turn off pin 13
  delay(1000); // Wait for 1000 millisecond(s)

  /* 
  The section above will turn on and off the LED. Note the CAPITAL LETTERS on the "HIGH" and "LOW"
  */
}
```

Learn more about camelCase here: [https://en.wikipedia.org/wiki/Camel_case](https://en.wikipedia.org/wiki/Camel_case)

Learn more about the "()" :[http://www.cplusplus.com/reference/functional/function/operator_func/](http://www.cplusplus.com/reference/functional/function/operator_func/)

If you want to read up about C++: [http://www.cplusplus.com/](http://www.cplusplus.com/)

Arduino language reference: [https://www.arduino.cc/reference/en/](https://www.arduino.cc/reference/en/)

## It WORKS!!!

Now, let us connect our SSTuino like this:

>**NOTE:** To prevent damage to your computer or the components, please **disconnect all power from the SSTuino board** when you are wiring up your circuit!

Connect the SSTuino to your mac after you have finished assembling the circuit.

In your Arduino IDE, go to

> Tools -> Port -> /dev/tty.SLAB_USBtoUART

port

Make sure to select the correct board:

board

And now you can upload with this button:

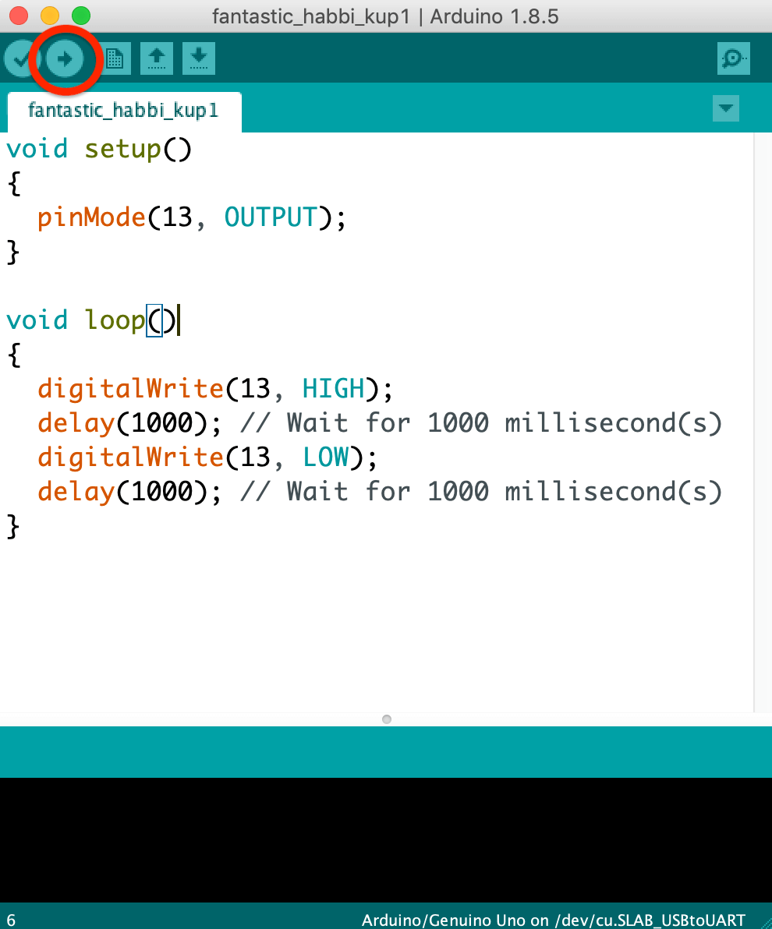
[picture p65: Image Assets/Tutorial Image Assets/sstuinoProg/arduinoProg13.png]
arduinoProg13


You should see your circuit light up like this:

arduinoProg14

## The SSTuino can read?!

In the next tutorial series, we will be looking at how to make the SSTuino recieve inputs from your components, and then have a reaction from that.

**[Click here to access the next tutorial](https://d3lta-v.github.io/SSTuino/tutorials/Sec1/digitalRead.html)**

Have fun!

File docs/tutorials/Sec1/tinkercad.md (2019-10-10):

---
title: My first circuit!
date: 2019-07-03
author: Goh Qian Zhe
---

# My first circuit!

In this tutorial, we will attempt a few simple circuits with a simple to use online simulator, TinkerCAD. After which, we will apply the circuits that we have created into real circuits with components in our SSTuino Kit.

## Table of Contents
* [Hello TinkerCAD](#hello-tinkercad)
* [Sign in to TinkerCAD](#sign-in-to-tinkercad)
* [Our First Circuit!](#our-first-circuit)
* [Your first circuit with the SSTuino Kit!](#your-first-circuit-with-the-sstuino-kit)
* [Add a button!](#add-a-button)
* [The photoresistor](#the-photoresistor)
* [Time to turn it up!](#time-to-turn-it-up)

## Hello TinkerCAD!

Say you have an amazing idea at hand and would like to realise it, to which you are thinking: "Hmm, how can I evolve my idea into a real product?"

Meet TinkerCAD, one of the most popular classroom tools for creating simple designs from scratch. It is a simple to use 3D design tool that requires no downloading of software, as it is an online design program.

In this tutorial, we will go through the setting up process of TinkerCAD and have fun with a mini project!

## Sign in to TinkerCAD

Signing in to TinkerCAD is easy.

* Go to [tinkercad.com](https://www.tinkercad.com/) and then click on Sign In

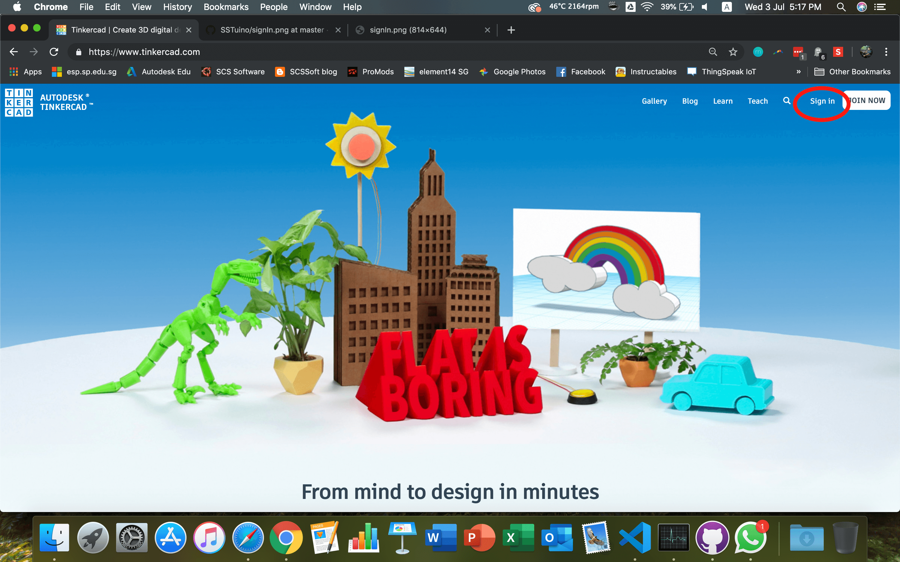
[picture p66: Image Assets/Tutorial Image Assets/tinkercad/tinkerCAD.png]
tinkerCAD


* Go to the login screen

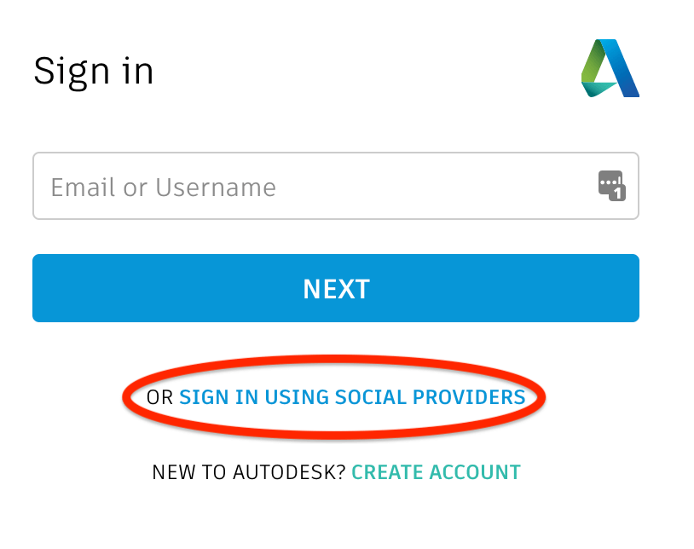
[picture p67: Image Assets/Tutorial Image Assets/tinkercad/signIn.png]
signIn


* Select sign in using social provider, and select your Google Account. 

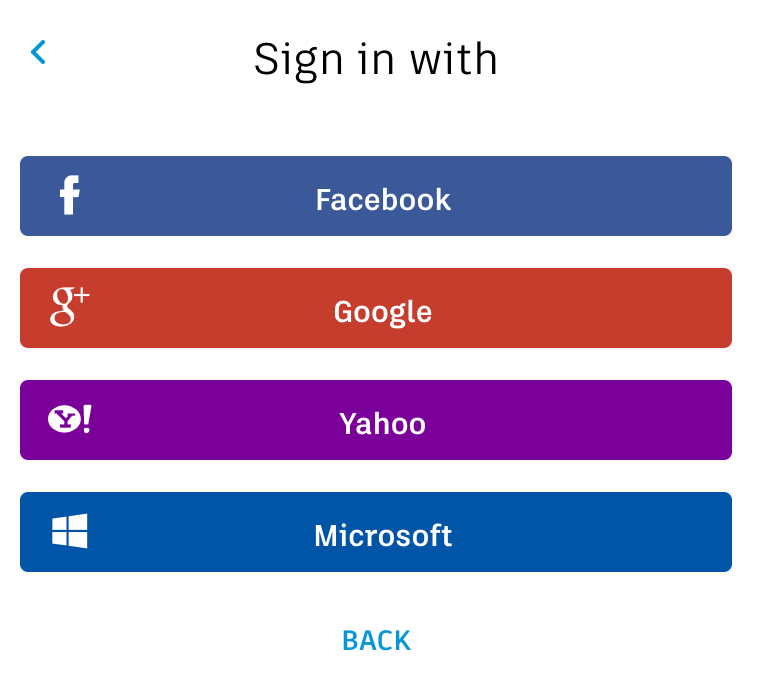
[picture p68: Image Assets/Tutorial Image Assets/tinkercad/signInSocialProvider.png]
socialProvider


* You are signed in! Your projects will appear here in the future!

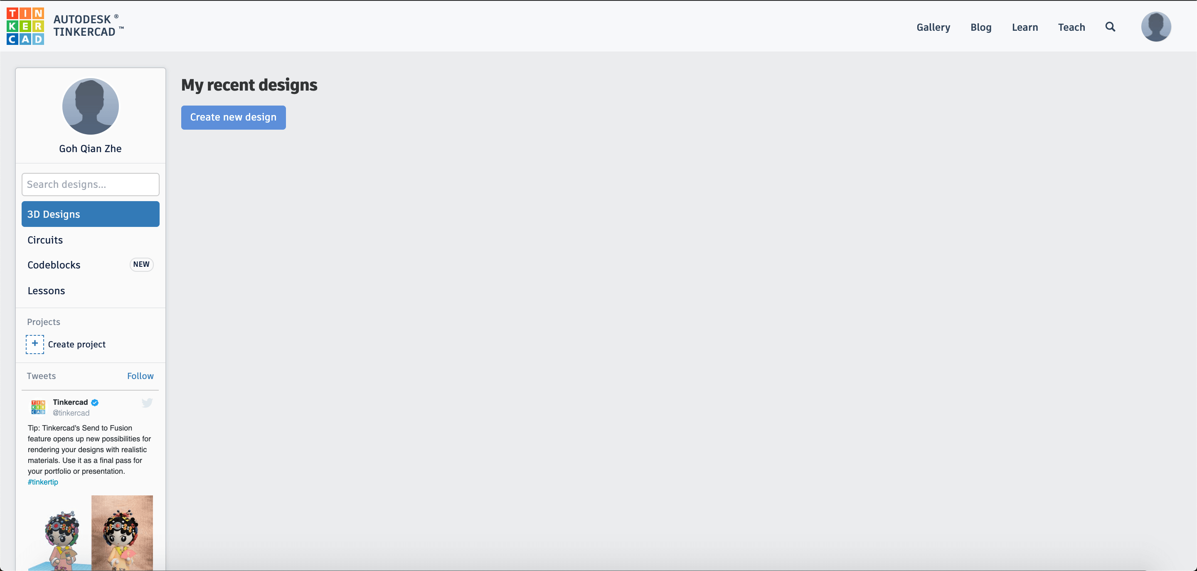
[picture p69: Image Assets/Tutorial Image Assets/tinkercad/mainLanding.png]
mainLanding


## Our first circuit!

Back to the topic of burning LEDs, here is one huge benefit of using TinkerCAD. As TinkerCAD can simulate circuits, we can test whether we use the correct components and connected it correctly before actually building it.

To start building our circuit, after you have logged in to your TinkerCAD account, navigate to 

> Circuits -> Create new Circuit

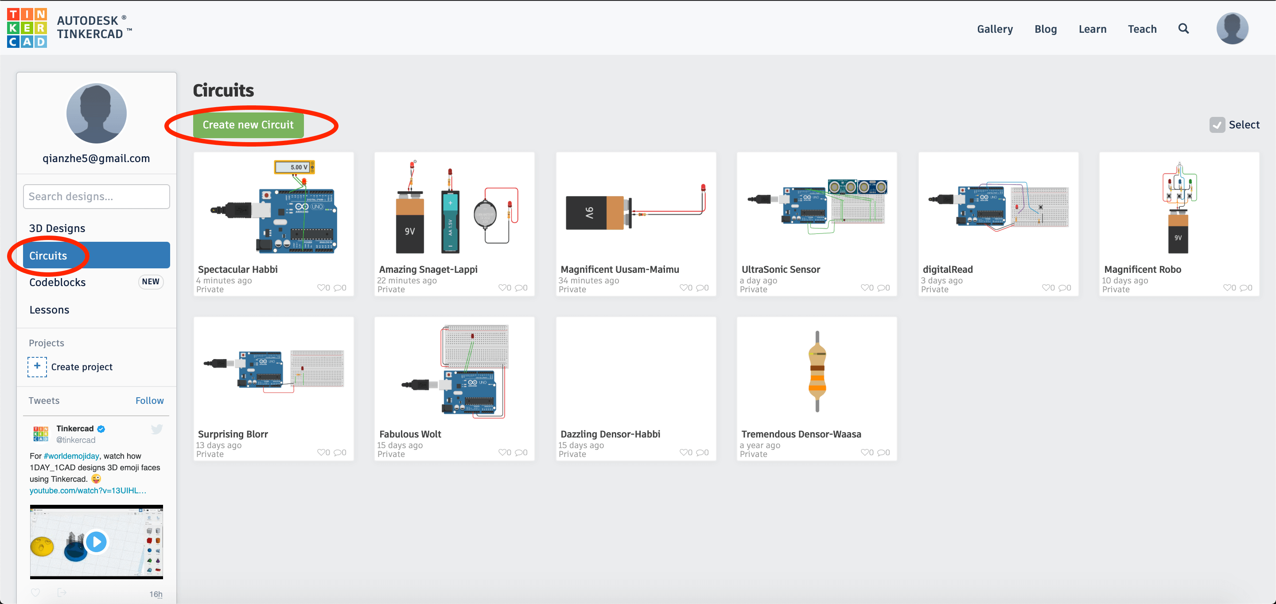
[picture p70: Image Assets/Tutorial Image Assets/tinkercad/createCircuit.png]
createCircuit


It is a very good habit to create a new circuit after you have finished your previous tutorial. This is to help you to be able to remember previous tutorials done when you would like to use it next time. After you have created the new circuit, it should look like this:

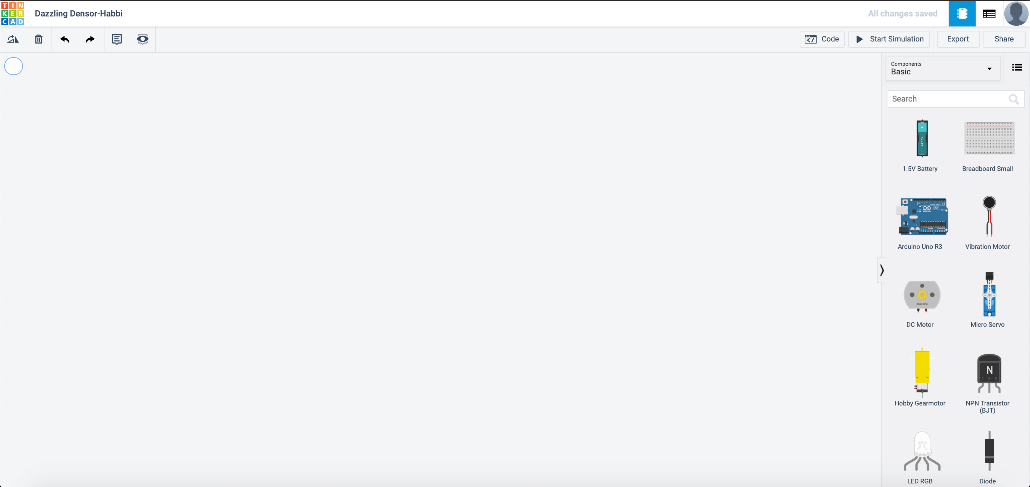
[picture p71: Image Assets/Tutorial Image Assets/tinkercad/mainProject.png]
mainProject


Here are the essential buttons of building electronic circuits with TinkerCAD.

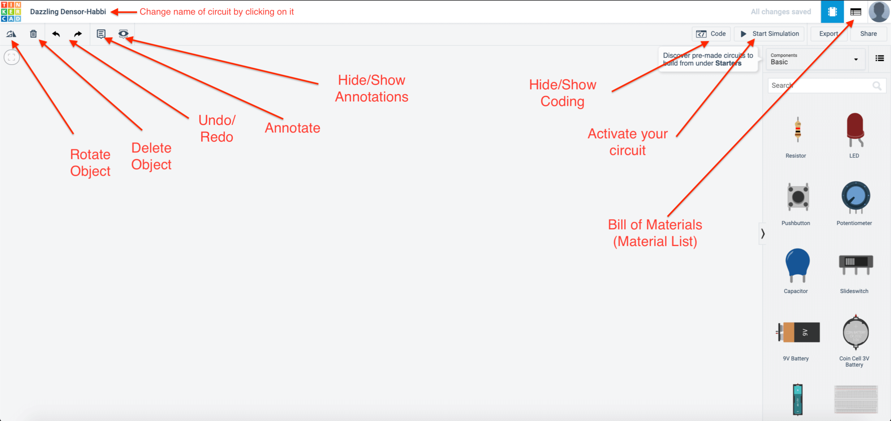
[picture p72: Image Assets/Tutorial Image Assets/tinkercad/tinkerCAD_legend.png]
!TinkerCAD_legend


Let us bring out a 9V battery then connect it as follows.

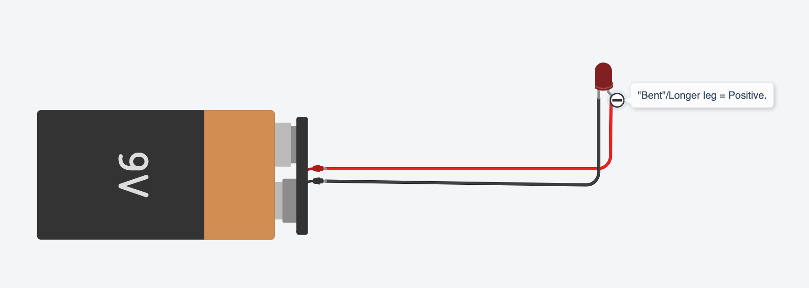
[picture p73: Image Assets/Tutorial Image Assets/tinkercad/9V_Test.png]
9V_Test


After you have connected the circuit, click on **Start Simulation** on the top right hand corner of the website.

Once it lights up, this happens.

9V_Test2

The reason this happens is due to the incorrect resistor being used. Remember **[Ohm's Law?](https://d3lta-v.github.io/SSTuino/tutorials/Sec1/electronicBasics.html#the-resistor)** When the resistance is too low the current would be too high.

Instead, connect a resistor like this:

9V_Test3

With the resistor attached, the LED lights up without burning up. :) Now you try this with different resistor values. What kind of changes happen?

Now, let us try this out using different types of batteries.TinkerCAD mainly provides 3 types of batteries: 9V, 3V and 1.5V. Connect your circuit up as shown.

9V_Test5

After you connect up the circuit, this happens:

9V_Test4

Why would this happen? This is because that LEDs have a minimum voltage to light up. If you look at the spec sheet located here:

[https://www.sparkfun.com/datasheets/Components/LED/COM-09590-YSL-R531R3D-D2.pdf](https://www.sparkfun.com/datasheets/Components/LED/COM-09590-YSL-R531R3D-D2.pdf)

> Forward Voltage: Min 1.8V, Max 2.2V. Suggested current:16 - 18mA

This means that the 1.5V battery would be barely able to light up the circuit, and only the 2 other battery types will be able to light up.

---

# Your first circuit with the SSTuino Kit!

So you have built yourself some very simple circuits. Now let us build circuits, but with an Arduino!

In TinkerCAD, create a new circuit. In this new circuit, drag out an Arduino Uno, a breadboard, one resistor and a LED. Connect it in this manner, with the **Positive(+)** connect to **5V** and the **Negative(-)** connect to **GND**. 

arduino1

If you had read [this tutorial](https://d3lta-v.github.io/SSTuino/tutorials/Sec1/electronicBasics.html), you should have known how the breadboard works.

Press **Start Simulation** and see your circuit light up!

arduino2

Now, copy your circuit from TinkerCAD onto your SSTuino Innovator's Kit. 

>**NOTE:** To prevent damage to your computer or the components, please **disconnect all power from the SSTuino board** when you are wiring up your circuit!

It should look something like this:

arduino8

Let us go back to the simulation and change the circuit like this:

arduino7

What would happen and why?

## Add a button!

Now time for you to "control" your circuit. Set up your circuit like this:

arduino4

What this circuit allows you to do is to turn on and off your LED. This push button works something like this: When you press the button, the circuit is closed and current can flow to the LED, which makes the LED light up. When the button is not pressed, the circuit is considered open and current will not flow to the LED, which makes the LED not light up.

Copy this circuit over to your SSTuino board setup.

>**NOTE:** To prevent damage to your computer or the components, please **disconnect all power from the SSTuino board** when you are wiring up your circuit!

arduino3

To futher spice up your circuit, you can consider adding more LEDs to the circuit. How would you add the LEDs to the circuit? What kind of reaction does your circuit have?

## The photoresistor

The photoresistor is a resistor that reacts to light. It changes resistance when the amount of light it detects changes.

Create a new circuit and set up your circuit like this:

arduino5

What this circuit allows you to see is the difference in LED brightness as you cover the photoresistor or shine a torch on it. 

arduino6

Copy this circuit over to your SSTuino board setup.

>**NOTE:** To prevent damage to your computer or the components, please **disconnect all power from the SSTuino board** when you are wiring up your circuit!

What happens to the LED brightness as you play with the photoresistor? Record and post a video onto Instagram and place a hashtag `#sstuino`! 

## Time to turn it up!

We are going to move into the programming stage of the SSTuino Innovator's Kit, so please move to the **[next tutorial](https://d3lta-v.github.io/SSTuino/tutorials/Sec1/sstuinoProgram.html)**

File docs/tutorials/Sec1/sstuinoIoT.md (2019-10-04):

---
title: The SSTuino can connect to the internet?!
date: 2019-09-15
author: Goh Qian Zhe
---

# The SSTuino can connect to the internet?!

This tutorial will cover the use of the WiFi functionality on the SSTuino board. We will be using it to interface it with a online IoT plaform - Adafruit IoT. Along with Thunkable, the IoT platofrm and the SSTuino, we can essentially create your own automated sensor suite or smart home project. The SSTuino is the main interface of the sensor/controllers, and collects all the sensor data and/or controlls all connected components like LEDs, fan etc.

This tutorial will require the use of the WiFi chip.

## Table of Contents
* [What is the Internet of Things (IoT) all about?](#what-is-the-internet-of-things-iot-all-about)
* [Creating your Adafruit.io account](#creating-your-adafruitio-account)
* [Connecting SSTuino to Adafruit.io](#connecting-sstuino-to-adafruitio)
* [MQTT Example](#mqtt-example)
* [Controlling your SSTuino!](#controlling-your-sstuino)
* [Connect SSTuino to Thunkable!](#connect-sstuino-to-thunkable)

## What is the Internet of Things (IoT) all about?

<div class="embed-container">
<iframe width="560" height="315" src="https://www.youtube.com/embed/BQzBpUdHvi4" frameborder="0" allow="accelerometer; autoplay; encrypted-media; gyroscope; picture-in-picture" allowfullscreen></iframe>
</div>

You may have seen weird things like smart fridges and smart toasters appear in a electronics store, but what is it really about? The term *Internet of Things* covers everything that is connected to the internet, but it is also increasingly used to define objects that communicate with each other. By connecting these devices together to an automated system, the system gathers information, analyses the information and creates an action to help with a certain task - for example a smart thermostat to help optimise the air conditioner operation in your room, saving on the amount of electricity used.

SSTuinoIoT1

The Internet of Things industry is starting to get very popular in a lot of industries, and is also very popular with DIY makers who use microcontrollers such as the Arduino or the Raspberry Pi to automate lots of everyday stuff.

## Creating your Adafruit.io account

Welcome to Adafruit IoT:

<div class="embed-container">
<iframe width="560" height="315" src="https://www.youtube.com/embed/SiDYTLzV0yU" frameborder="0" allow="accelerometer; autoplay; encrypted-media; gyroscope; picture-in-picture" allowfullscreen></iframe>
</div>

To create your adafruit.io account go to this tutorial by Adafruit here:

**[https://learn.adafruit.com/welcome-to-adafruit-io/getting-started-with-adafruit-io](https://learn.adafruit.com/welcome-to-adafruit-io/getting-started-with-adafruit-io){:target="_blank"}**

## Connecting SSTuino to Adafruit.io

First, we need to install a library to your Arduino IDE. Simply copy and paste this command into your Terminal:

```sh
curl -fsSL https://sstuino.fourier.industries/library_install.sh | bash
```

...and hit enter! The installation should complete without any errors. You can always update your library by running the same command if there is a new release of the library available.

### Hold your horses...

By having custom made firmware and library for theSSTuino. we would like to bring something to light: MQTT. This **MQTT** Term will be used frequently in our internet of things tutorials for the SSTuino.

MQTT stands for **M**essage **Q**ueuing **T**elemetry **T**ransport. It is a lightweight publish and subscribe system where you can publish and receive messages as a client. 

MQTT is a simple messaging protocol, designed for constrained devices with low-bandwidth. So, it’s the perfect solution for Internet of Things applications. MQTT allows you to send commands to control outputs, read and publish data from sensor nodes and much more.

Therefore, it makes it really easy to establish a communication between multiple devices.

By having a fimware upgrade on the WiFi chip and having a new library for the SSTuino, we would like to bring something to light: MQTT. Watch this video to find out more!

<div class="embed-container">
<iframe width="560" height="315" src="https://www.youtube.com/embed/EIxdz-2rhLs" frameborder="0" allow="accelerometer; autoplay; encrypted-media; gyroscope; picture-in-picture" allowfullscreen></iframe>
</div>

Ok, back to the main topic...

## MQTT example

We are going to make your previous **[TMP36 Temperature Sensor](https://d3lta-v.github.io/SSTuino/tutorials/Sec1/dataInput.html#temperature-sensor)** smart and connect to the internet!

For our MQTT example, let us create a new feed:

SSTuinoIoT2

In your Arduino IDE, go to

> File > Examples > SSTuino Companion > `Adafruit_MQTT_Pub`

SSTuinoIoT3

The example should look something like this:
SSTuinoIoT4

Remember this?

arduinoPot23

This is the code that we used:

arduinoPot24

Go to that particular example and open the code in TinkerCAD, in **Blocks + Text** mode. We are going to do some mix-and-match to make it work with Adafruit.io.

SSTuinoIoT35

The code can be split into 3 parts. The red part is declaration, the green part is setup, and the blue part is the loop.

SSTuinoIoT8

So the red declaration portion goes into this part of the MQTT example:

<p align="center">
  
   
</p>

The green setup code goes into this part of the MQTT example:

<p align="center">
  
   
</p>

The blue loop code goes into this part of the MQTT Example:

<p align="center">
  
   
</p>

Your code should look something like this after the edit:

``` Cpp
/*
  Adafruit IO with MQTT
  For the SSTuino boards.
  This example sketch publishes to Adafruit IO every 7.5 seconds using MQTT.
  This can be a foundation to use for uploading sensor data to the cloud for
  an IoT sensor.
  This example code is in the public domain.
  https://d3lta-v.github.io/SSTuino/
*/

#include "SSTuino_Companion.h"

#define SSID          "SSID GOES HERE"
#define PASSWORD      "WIFI PASSWORD GOES HERE"
#define IO_USERNAME   "AIO USERNAME GOES HERE"
#define IO_KEY        "AIO KEY GOES HERE"
#define FEED_KEY      "FEED KEY GOES HERE"

SSTuino wifi = SSTuino();

int temp = 0;

void setup()
{
  Serial.begin(9600);

  // Open the link between the two devices
  wifi.openLink();

  // Verify that the link is ok between the two devices
  if (!wifi.smokeTest()) {
    Serial.println(F("Unable to establish link with Wi-Fi chip. Halting.")); 
    while (true){};
  }

  wifiConnect();

  setupMQTT();

  pinMode(A0, INPUT);
  Serial.begin(9600);
}

void loop()
{
  temp = (-40 + 0.488155 * (analogRead(A0) - 20) + 0);
  Serial.println(temp);

  transmitData(String(temp));
  delay(7500); // you can replace this delay with something longer or shorter,
               // but 7.5s interval is preferred to prevent flooding Adafruit IO
}

void wifiConnect(void)
{
  // Connects to Wifi and displays connection state
  wifi.connectToWifi(F(SSID), F(PASSWORD));
  Serial.println(F("Connecting to Wi-Fi..."));

  delay(10000); // 10 seconds optimal for wifi connection to fully establish

  Status wifiStatus = wifi.getWifiStatus();
  if (wifiStatus != SUCCESSFUL) {
    Serial.println(F("Failed to connect to Wi-Fi"));
    while (true){};
  } else {
    Serial.println(F("Wi-Fi connected"));
  }
}

void setupMQTT(void)
{
  // Setup MQTT
  Serial.println(F("Setting up MQTT..."));
  bool mqttSuccess = wifi.enableMQTT(F("io.adafruit.com"), true, IO_USERNAME, IO_KEY);
  if (!mqttSuccess) {
    Serial.println(F("Failed to enable MQTT. Halting."));
    while (true){};
  }
  delay(10000); // Wait for MQTT to fully connect

  // Check if MQTT is connected
  if (!wifi.isMQTTConnected()) {
    Serial.println(F("MQTT did not connect successfully!"));
    while (true){};
  } else {
    Serial.println(F("MQTT connected!"));
  }
}

void transmitData(const String& value)
{
  if (wifi.mqttPublish(F(IO_USERNAME "/feeds/" FEED_KEY), value)) {
    Serial.println(F("Successfully published data!"));
  } else {
    Serial.println(F("Failed to publish data!"));
  }
}
```

Now go to your Adafruit.io and get your API key and feed key.

Your API Key should look something like this:

SSTuinoIoT6

Your Feed key should look someting like this: 

SSTuinoIoT7

> **Important**: Please do not share API keys. Other users can use your account or flood data to it if your API key is public

Fill in your Wifi SSID (The name of the WiFi), password, Adafruit.io username, IO key and feed key in this section:
> Note that Enterprise WiFi networks such as `SST_Student` will not work on the WiFi Chip due to insufficient memory to use the more complicated protocol. Instead you would have to use your mobile hotspot. Note that hotspots with a Apostrophe `'` like `Qian Zhe's iPhone` will not work. Please change the name of the network. A good example is `SINGTEL-2001`

SSTuinoIoT5

Let us now upload the code to the SSTuino. We will need the WiFi Chip (Flashed by Qian Zhe or Ziyue) to be installed on the SSTuino like this:
> Make sure that the small white switches are all ON (push upwards)

SSTUinoIoT12

After the code has successfully uploaded, open up the serial monitor to verify that a link to Adafruit.io has been established. 

SSTUinoIoT13

Go to your Adafruit.io temperature feed and you should be able to see data points come up in the feed.

SSTUinoIoT14

Let us now create our new Adafruit.io dashboard. I'll name it `My Smart Home`, and place a gauge as follows:

SSTUinoIoT15

SSTUinoIoT16

SSTUinoIoT17

SSTUinoIoT18

SSTUinoIoT19

After you have configured your dashboards, your guage will look like this!

SSTUinoIoT20

## Controlling your SSTuino!

Since we have managed to send temperature data from the SSTuino to Adafruit.io, now let us try controlling something on the SSTuino from Adafruit.io!

First, let us create a new feed in Adafruit.io. Name it `trigger`. We are going to use another example this time, the MQTT Subscribe example. In the example, the SSTuino will wait on commands from the Adafruit.io platform.

SSTuinoIoT38

Next go to your dashboards, and use the previous dashboard: **My Smart Home**. In the dashboard we will place in a switch, which is configured to change the `trigger` feed we had created just now.

<p align="center">
  
   
</p>

SSTuinoIoT41

Next we will place in a feed, which is configured to read the `trigger` feed we had created just now.

First, let us create a new circuit in TinkerCAD. We will connect our LED to `PIN6`, as shown:

SSTUinoIoT21

Our code will look something like this:

SSTUinoIoT22

After the creation of your new circuit, open the example `Adafruit_IO_MQTT_Sub`

SSTUinoIoT23

Just like the TMP36 example, we will need to combine the code from TinkerCAD into our examples, just that this time there will be a little twist...

Once the example is open, it will look something like this:

SSTUinoIoT24

From our TinkerCAD, open up **Blocks + Text**.

SSTUinoIoT25

We are now going to integrate this code from TinkerCAD to our MQTT Subscribe example. It is very simillar to our previous TMP 36 example. As there are no declarations in this code, just leave the comment alone.

SSTUinoIoT26

We will now copy the setup code into the program. Remember to only copy the contents inside the brackets.

<p align="center">
  
   
</p>

Let us now insert the Void loop code into the program. Remember to only copy the contents inside the brackets.

<p align="center">
  
   
</p>

We will now need to do some editing to the loop code. When you look at the loop code, you would probably realise that the `if (0 == 0)` is not correct and not logical. This is because that we will be comparing a string, which is not possible in TinkerCAD.

>A string is a data type used in programming, such as an integer and floating point unit, but is used to represent text rather than numbers. Find out more here: 
<div class="embed-container">
<iframe width="560" height="315" src="https://www.youtube.com/embed/3A3TFVDrLCA" frameborder="0" allow="accelerometer; autoplay; encrypted-media; gyroscope; picture-in-picture" allowfullscreen></iframe></div>

Let us have a look at the line above the loop code that we pasted in just now. It looks something like this: `Serial.println(receivedRawData)`. The variable `receivedRawData` is a **String** and it is the data sent from the Adafruit IO platform. 

From your Adafruit IO, you would have seen that if the switch is **ON**, the readout from the feed will also be **ON**. so what we will do is that we will change the `if (0 == 0)` to `if (receivedRawData == "ON")`. This means that when I receive a message from Adafruit.io for ON, I will turn on the LED. Else, I will turn off the LED. Your edited loop code should look something like this:

SSTUinoIoT31

Here is the text code you have just done:

```Cpp
/*
  Adafruit IO with MQTT

  For the SSTuino boards.

  This example sketch subscribes to Adafruit OP using MQTT.
  This can be a foundation to use for automation over the Internet.

  This example code is in the public domain.

  https://d3lta-v.github.io/SSTuino/
*/

#include "SSTuino_Companion.h"

#define SSID          "SSID GOES HERE"
#define PASSWORD      "WIFI PASSWORD GOES HERE"
#define IO_USERNAME   "AIO USERNAME GOES HERE"
#define IO_KEY        "AIO KEY GOES HERE"
#define FEED_KEY      "FEED KEY GOES HERE"

SSTuino wifi = SSTuino();

String receivedRawData = "    ";

/*    
  Insert your custom variable declarations here
*/

void setup()
{
  Serial.begin(9600);

  // Open the link between the two devices
  wifi.openLink();

  // Verify that the link is ok between the two devices
  if (!wifi.smokeTest()) {
    Serial.println(F("Unable to establish link with Wi-Fi chip. Halting.")); 
    while (true){};
  }

  wifiConnect();

  setupMQTT();

  pinMode(6, OUTPUT);
  
}

void loop()
{
  bool newDataReceived = false;
  wifi.mqttPollNewData(&newDataReceived, F(IO_USERNAME "/feeds/" FEED_KEY), 500);
  /* The above code "mutates" the newDataReceived variable, which means it
     doesn't have to return anything */

  if (newDataReceived == true) {
    // Print out the new data when you received it
    receivedRawData = wifi.mqttGetSubcriptionData(F(IO_USERNAME "/feeds/" FEED_KEY));
    Serial.print(F("New data received: "));
    Serial.println(receivedRawData);
  }

  if (receivedRawData == "ON") {
    digitalWrite(6, HIGH);
  } else {
    digitalWrite(6, LOW);
  }
}

void wifiConnect(void)
{
  // Connects to Wifi and displays connection state
  wifi.connectToWifi(F(SSID), F(PASSWORD));
  Serial.println(F("Connecting to Wi-Fi..."));

  delay(10000); // 10 seconds optimal for wifi connection to fully establish

  Status wifiStatus = wifi.getWifiStatus();
  if (wifiStatus != SUCCESSFUL) {
    Serial.println(F("Failed to connect to Wi-Fi"));
    while (true){};
  } else {
    Serial.println(F("Wi-Fi connected"));
  }
}

void setupMQTT(void)
{
  // Setup MQTT
  Serial.println(F("Setting up MQTT..."));
  bool mqttSuccess = wifi.enableMQTT(F("io.adafruit.com"), true, IO_USERNAME, IO_KEY);
  if (!mqttSuccess) {
    Serial.println(F("Failed to enable MQTT. Halting."));
    while (true){};
  }
  delay(10000); // Wait for MQTT to fully connect

  // Check if MQTT is connected
  if (!wifi.isMQTTConnected()) {
    Serial.println(F("MQTT did not connect successfully!"));
    while (true){};
  } else {
    Serial.println(F("MQTT connected!"));
  }

  // Setup MQTT subscribe
  if (wifi.mqttSubscribe(F(IO_USERNAME "/feeds/" FEED_KEY))) {
    Serial.println(F("Successfully subscribed!"));
  } else {
    Serial.println(F("Failed to subscribe. Halting."));
    while (true){};
  }
}
```

Now let us add a slider onto the dashboard. The values should range from 0 - 255.

SSTUinoIoT42

Let us remove this portion of code from the program

```C++
  if (receivedRawData == "ON") {
    digitalWrite(6, HIGH);
  } else {
    digitalWrite(6, LOW);
  }
```

Instead, replace it with this

``` C++
  analogWrite(6, receivedRawData.toInt())
```

You may have seen something unfamillar. The `toInt()` function converts the value of the string `recievedRawData` into an integer (Whole number) for the pwm to be able to output.

After you have edited the code, simply upload it to the SSTuino, wait for the MQTT to subscribe and there you go!

## Connect SSTuino to Thunkable!

Now we have managed to control your SSTuino from Adafruit.io, let us use our Thunkable to view our SSTuino statistics and to control our SSTuino!

For this portion of the tutorial, we managed to do up a Thunkable template for you! Simply go to this link here:

**[https://x.thunkable.com/copy/678d79fc0c561ef77e5e6a4fcbd5788e](https://x.thunkable.com/copy/678d79fc0c561ef77e5e6a4fcbd5788e)**

You will just need your AIO username, AIO Key and feed key to get started!

SSTUinoIoT43

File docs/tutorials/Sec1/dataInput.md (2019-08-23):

---
title: Data at my fingertips!
date: 2019-05-29
author: Goh Qian Zhe
---

# Data at my fingertips!

In this tutorial, we are going to read data from various sensors, and use it to trigger certain actions. We will learn the `analogRead`, `analogWrite` functions in this tutorial too.

Sensors that will be covered
* Potentiometer
* Light Dependent Resistor/Photoresistor
* Ultrasonic Distance Sensor
* TMP36 Temperature Sensor

## Reading from potentiometer

The potentiometer is essentially a variable resistor. But instead of having 2 pins, it has 3 pins. The potentiometer that is provided in the kit is a 10K Ohm potentiometer, which means that when the knob is turned fully to one end it is 0 Ohm, while at the other end it is 10K Ohm.

arduinoPot

Potentiometers are used frequently and comonnly on electronic devices. A simple example would be the volume knob on speakers, or the light dimmers in your houses!

**[Further read:](https://www.electronics-tutorials.ws/resistor/potentiometer.html)**

This is the potentiometer that we will be using in this tutorial:

arduinoPot1

It is the Bourns 3386F Potentiometer that can be found **[here](https://www.digikey.sg/product-detail/en/bourns-inc/3386F-1-103TLF/3386F-103TLF-ND/1232544)**

Let us fire up TinkerCAD, create a new circuit and configure your circuit like this:

arduinoPot2

Note that the potentiometer in TinkerCAD and the one provided in the kit is different, as they are different types of potentiometers, but they serve the same purpose and would not have any difference. Next up, in the coding section, we would want to program it such that the serial monitor outputs the reading of the potentiometer.

arduinoPot3

After you are done with the circuit and code, simply run the simulation and open the serial monitor. As you twist the knob of the potentiometer, you should see the number change from 0 to 1023. Why this specific number? Well... Inside the SSTuino's chip, there is a Analog to Digital Converter, also known as ADC that has a resoloution of 10 bits. The higher the resoloution, the more precise the measurement is. If you use your calculator and then type in **2 to the power of 10** you will get 1024, which is the number of reading that you will get.

Copy this circuit over to your SSTuino board setup.

>**NOTE:** To prevent damage to your computer or the components, please **disconnect all power from the SSTuino board** when you are wiring up your circuit!

In your Arduino IDE, once you have uploaded the code, apart from opening the serial monitor, you can also open the serial plotter. It outputs the results to graphs.

## Speed Control

Since we have managed to get a reading from a analog pin from the SSTuino, we are going to make use of the reading to alter the blinking speed of an LED. We are going to first fire up TinkerCAD and edit the circuit to something like this: 

arduinoPot4

For the code, we are going to use the blink code and edit the `delay()` function. What we are trying to achieve is that when I turn the knob of the potentiometer, the speed of the blinking of the LED changes.

arduinoPot5

This is the result I should get:

Copy this circuit over to your SSTuino board setup.

>**NOTE:** To prevent damage to your computer or the components, please **disconnect all power from the SSTuino board** when you are wiring up your circuit!

In your Arduino IDE, once you have uploaded the code, apart from opening the serial monitor, you can also open the serial plotter. It outputs the results to graphs.

## SSTuino controlled dimmer

Next, we will use the SSTuino's PWM output function to control the brightness of the LED. On other pins, you can only turn the LED on or off. There are some pins with the wavy `~` sign, which means that it can output PWM signals. With digital electronics, it requires a bit of a trick to control something with analog means. 

PWM stands for Pulse Width Modulation. The pin would output a series of square waves, and depending on the duty cycle, adjusts the width of the square wave. What it essentially does is that it turns on and off the component very quickly, such that our eyes cannot see the difference. In the diagram below, you can see how the duty cycle is adjusted by changing the width of the square wave. When the duty cycle is 0, it turns off the component. From 0 to 100, it gradually increases the intensity, and is a full power when at 100% duty cycle.

arduinoPot7

To read up more about Pulse Width Modulation on Arduino, check out this link **[here](https://www.arduino.cc/en/Tutorial/PWM)**

For this exercise, we will use the same circuit and just edit the code:

arduinoPot6

I divide the input by 4 as the range of the PWM output is only from 0-255, which means that it is 8-bit.

This is the result I should get:

Copy this circuit over to your SSTuino board setup.

>**NOTE:** To prevent damage to your computer or the components, please **disconnect all power from the SSTuino board** when you are wiring up your circuit!

In your Arduino IDE, once you have uploaded the code, apart from opening the serial monitor, you can also open the serial plotter. It outputs the results to graphs.

## Beep Beep!

Let us play some tones with the SSTuino! We are now going to insert a piezo element into our circuit. Configure your circuit like this:

arduinoPot8

I am going to play 3 tones on the harmonic scale. Can you play up to 1 full scale? *(Do, Re, Mi, Fa, So, La, Ti Do!)*

arduinoPot9

## Pieno

We are now going to use the potentiometer to control the tone of the speaker. This means that as you turn the knob on the potentiometer, the pitch of the speaker will change. With the same circuit as the previous exercise, we are going to tweak the code for the Pieno.

First, we will need to create a new variable called pot. In this exercise, we are going to introduce to you another function: *map to range*. What basically happens is that the input and output range will mostly be different. In this case, the potentiometer has a range `from 0 to 1023`, but the speaker has a output range `of 35 to 127`. By mapping the range, we can make sure that when the potentiometer is at one end of the input range, the speaker is definitely also at one end of its output range.

arduinoPot10

After you have tried this out, run the simulation and create your own music!

## Enhancing the Pieno

Would it be possible to add more functions to the *pieno*? Sure thing! Let us add 2 more buttons to the circuit as shown:

arduinoPot11

These will be the two functions that we will add:
* A button to stop the music
* A button to make the tone beep intermittently

arduinoPot12

## A *slightly* smarter light sensor

For this exercise, we will be going back to the Light Dependant Resistor (LDR)/photoresistor. Previously [in this tutorial](), we managed to try out the photoresistor. Now we are going to make use of it as an input for the SSTuino to trigger something! You may remember that the purpose of the photoresistor was not really significant or useful, as it made the LED brighter when the environment was bright. But with some programming, we can make it work properly!

Let us move into TinkerCAD and create a new circuit, something that looks like this:

arduinoPot13

We will read the photoresistor value from the analog pin and output it to the serial monitor.

arduinoPot14

When running the simulation, open up the serial monitor. The result should look something like this:

arduinoPot15

While I change the light intensity of the LDR, the readings also change.

Now let us make it useful. We would want to make it such that when the environment darkens, the LED will light up. To do so, we edit our code to something like this:

arduinoPot16

In the `if` statement, the value where your LDR detects that the environment is dark varies. You may have a different value for your circuit and you will need to edit the value.

## Ultrasonic Sensor

The ultrasonic distance sensor uses ultrasonic waves - a very high pitched sound that we cannot hear to measure the distance it is from an object. It is in a **transducer** configuration, where the transmitter and reciever is on the same sensor.

arduinoPot17

One of the most common uses of ultrasonic distance sensor is in the automotive industry. They are usually used as reverse warning sensors but are increasingly used in self-driving vehicles, like Tesla's Autopilot for example. 

arduinoPot21

The ultrsonic sensor we are going to use is the HC-SR04, which is commonly used in Arduino circuits:

> Note that we need to use the 4 pin sensor instead of the 3 pin one, which can be found by typing *ultrasonic sensor* in the component search bar.

arduinoPot18

Let us go into TinkerCAD and create a new circuit. We are going to assemble it like this:

arduinoPot19

The coding part with blocks is rather simple, as the TinkerCAD team have simplified the code to just this line:

arduinoPot20

## Temperature Sensor

Temperature sensors are essential in electronics. Their uses are very broad, ranging from reading the temperature of the surrounding environment, to the temperature probes on your computer, to keep it from overheating! The temperature sensor that we are going to use in this exercise is the TMP36, an affordable yet accurate temperature sensor.

arduinoPot22

Let us go into TinkerCAD and create a new circuit. We are going to assemble it like this:

arduinoPot23

The code will look something like this:

arduinoPot24

We declared a variable called `temp` and we let the reading of the temperature sensor be the variable. Next, we add a `+` sign to it to calibrate the sensor. In the event the sensor reading is lower than the actual reading, we add a few degrees to bring it up.

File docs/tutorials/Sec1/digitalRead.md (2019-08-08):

---
title: My SSTuino can read!
date: 2019-07-19
author: Goh Qian Zhe
---

# My SSTuino can read?!

*Well, not literally reading English...* Microcontrollers like the SSTuino and the Arduino can read data from a large variety of channels, such as sensor data, internet data, and so on.

## Pull-up Resistors

Pull-up resistors are found in digital logic devices and microcontrollers. When a pin in say, the SSTuino is connected as an input and tries to read the state of the pin, it is very difficult to determine wether the pin is actually high or low, due to a lot of factors such as noise in the circuit. This phenomena is referred to as floating (more detailed explanation [here](https://learn.adafruit.com/circuit-playground-digital-input/floating-inputs)).

To eliminate this, we will place a pull-up resistor to ensure that the pin is either in its `high` or `low` state, while using a litle bit of current. Pull-up resistors are usually used on buttons and switches where there is a possibility of signal noise.

pullUp

If you would like to read more about this, visit this sparkfun guide here: 

[https://learn.sparkfun.com/tutorials/pull-up-resistors/all](https://learn.sparkfun.com/tutorials/pull-up-resistors/all)

## Buttons!

We are going to read very simple data from a push button, to know wether it has been pressed or not. Set up your circuit as shown:

arduinoButton1

Next, go to the coding section and then program it like this:

arduinoButton2

What this code does is that the Arduino would wait for the button to be pressed. If the button is not pressed, it would output "Not pressed!" in the serial monitor. If the button is pressed, it would output "pressed!" in the serial monitor.

Now start simulation and then press the serial monitor:

arduinoButton3

Copy this circuit over to your SSTuino board setup.

>**NOTE:** To prevent damage to your computer or the components, please **disconnect all power from the SSTuino board** when you are wiring up your circuit!

## Control your lights!

*This time with coding...* With the data we have read from the push button, we can use it to trigger a reaction! Set up your circuit as shown:

arduinoButton4

Next, we will need to edit the code such that the LED will light up when the button is pressed:

arduinoButton5

This will happen after you start simulation:

Copy this circuit over to your SSTuino board setup.

>**NOTE:** To prevent damage to your computer or the components, please **disconnect all power from the SSTuino board** when you are wiring up your circuit!

 Record and post a video onto Instagram and place a hashtag `#sstuino`! 

## Flashing Lights!

 arduinoButton12

 We are going to alternate the flashing of 2 different LED lights to mimick that of an emergency vehicle (e.g. Ambluance, Police Car, Fire Brigade etc.)

 Set up your circuit as shown:

arduinoButton6

 This is one of the ways to program it. What other ways can you program it?

arduinoButton7

After you are done with the assembly and programming, this is how it should look like:

arduinoButton8

Copy this circuit over to your SSTuino board setup.

>**NOTE:** To prevent damage to your computer or the components, please **disconnect all power from the SSTuino board** when you are wiring up your circuit!

arduinoButton13

Now, we are going to improve this circuit by adding a button. This allows the user to turn on the flashing lights only when he/she needs to use it. When the button is pressed, the lights will start flashing?

Set up your circuit as shown:

arduinoButton9

How would you edit the code to make it flash when the button is pressed, and to stop flashing once the button is not pressed?

arduinoButton11

How would you edit the code for the lights to flash faster?

Copy this circuit over to your SSTuino board setup.

>**NOTE:** To prevent damage to your computer or the components, please **disconnect all power from the SSTuino board** when you are wiring up your circuit!

arduinoButton14

Record and post a video onto Instagram and place a hashtag `#sstuino`! 

## Emergency vehicle coming through!

With your lights and the push button, let us attempt to insert some sound! For this section, we are going to use the included buzzer to make some sound!

Duplicate the previous circuit:

arduinoButton18

and set it up as follows:

arduinoButton19

Along with the flashing lights, we would need to program the buzzer such that it sounds correctly! This is one way to program it:

arduinoButton20

## Naming your variables

After some tinkering with your coding, you may realise that it may be an hassle to change for example a pin, like this example code:

```C++
void setup()
{
  pinMode(13, OUTPUT);
}

void loop()
{
  digitalWrite(13, HIGH);
  delay(1000); // Wait for 1000 millisecond(s)
  digitalWrite(13, LOW);
  delay(1000); // Wait for 1000 millisecond(s)
}
```

Imagine that you would have to change all the `pin 13` to another pin, and would have to scan through the entire code just to change all these values! Although Arduino Programs may be rather short, but still... *changing all of the numbers like that is kind of a hassle right?*

*Introducing... Variable names.* 

Here is a modified version of the code you saw above just now.

```C++
int LED = 13;
int wait = 1000;

void setup()
{
  pinMode(LED, OUTPUT);
}

void loop()
{
  digitalWrite(LED, HIGH);
  delay(wait); // Wait for 1000 millisecond(s)
  digitalWrite(13, LOW);
  delay(wait); // Wait for 1000 millisecond(s)
}
```

**SEE?** I have managed to change all the numbers to variable names. For example, in the event I want to adjust the `delay()` function in the code, I just have to change the `1000` at the `int wait=1000;` into a different number! Isn't that way more straightforward?

*How about you try it out?*

## How about 2 buttons?!

 We are going to introduce the AND OR operators into the program.

### Some History...

Back when technology was not this advanced, the various operators were actual hardware logic gates that were placed into the circuit. The chips looked something like this:

arduinoButton15

In this section, we are going to cover two types of operators

**AND Operator**

How it works is that if both Input 1 and Input 2 are `high`, it will give a `high` output, as illustrated in this table:

|Input 1|Input 2|Output|
|0|0|0|
|1|0|0|
|0|1|0|
|1|1|1|

**OR Operator**

How it works is that if either Input 1 **OR** Input 2 are `high`, it will give a `high` output. If both Inputs are `high`, it will also give a `high` output, as illustrated in this table:

|Input 1|Input 2|Output|
|0|0|0|
|1|0|1|
|0|1|1|
|1|1|1|

As technology has advanced leaps and bounds, these basic operators evolved from actual hardware gates to just a line of code in your program. A modern microprocessor can do so much more than what these chips used to do.

If you are interested to learn about logic gates:[https://www.electronics-tutorials.ws/logic/logic_10.html](https://www.electronics-tutorials.ws/logic/logic_10.html)

## OR Operator example:

Let us create a new circuit in TinkerCAD like this:

arduinoButton16

Next, we will need to edit the code such that the LED would light up once **one** of the buttons is pressed:

arduinoButton17

## AND Operator example:

For this, we just have to change the code to this:

arduinoButton21

Now start the simulation.

>To activate the two buttons, you would have to press and hold **SHIFT** on your keyboard while clicking the buttons to activate both buttons.

## Putting them together

Let us duplicate the circuit we have just created in the previous section.

arduinoButton22

We will need to have 3 LEDs this time, to show that:

|**Button 1**|**Button 2**|**Output**|
|Not Pressed|Not Pressed|RED LED|
|Pressed|Not Pressed|YELLOW LED|
|Not Pressed|Pressed|YELLOW LED|
|Pressed|Pressed|GREEN LED|

The circuit is built as shown:

arduinoButton23

How would you program it?

This is one of the ways it would work:

arduinoButton24

I would ask:
1. Are any of the buttons pressed? If yes go to 2, if not, Red LED.
2. Are both of the buttons pressed? If yes, Green LED, if not, Yellow LED.

So would there be other ways to do it? *Certainly!* This is just one of the ways you can do it! There are many ways to make it work the same way also!

## Toggle switch

Let us assume that we only have a button to control our lighting. Based on previous examples, if you were want to light up the LED, you would have to press and hold the LED right? What if I was to use the washroom and want the lights to be on? I would then have to press and hold the button for the lights to remain on! To prevent this from happening, we can make our button into a toggle switch with some coding...

Duplicate this circuit from the this **[tutorial](#control-your-lights)**

arduinoButton25

The circuit should look something like this:

arduinoButton26

For the program, we would have to introduce variables. To create variables, navigate here:

arduinoButton27

Create the variables `btn` and `led`. We are going to use these variables to store the state of the button and LED. What this means is that if the button is pressed, I change the state of the variable and it will remember the state, which also means that if I press and hold it, it does not spam the ON command. It will just activate once. Same with the LED.

Here is how the program can be coded:

arduinoButton28

Did you manage to do it?

## Next up...

We will be reading analog inputs into our SSTuino! 

**[Click here for the tutorial](https://d3lta-v.github.io/SSTuino/tutorials/Sec1/dataInput.html)**

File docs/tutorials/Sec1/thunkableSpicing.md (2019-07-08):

---
title: Spicing it up...
date: 2019-07-08
author: Goh Qian Zhe
---

# Spicing it up...

So we have managed to create our first app, but don't you agree that the application looks a bit... *basic*? Well not to worry, in this tutorial, we will teach you how to make your app more appealing to users!

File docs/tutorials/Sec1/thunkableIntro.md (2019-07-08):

---
title: My first mobile app!
date: 2019-07-08
author: Goh Qian Zhe
---

# My first mobile app!

thunkableLanding

So, you were probably thinking of creating a mobile application but did not know where to start. Welcome to Thunkable! Thunkable is a simple to use platform for developing applications for both Andriod and iOS as it uses block coding, which means that to build an app, all you would have to do is to drag and drop your functions in the build screen.

## Registering for Thunkable

Signing up for Thunkable is very simple. Click the Sign up button on the top right hand corner and sign up either with your Google account or email

thunkableSignup

After you are done, go to your App Store or Play store to download the Thunkable app as this app is used to visualise the app that you have built in Thunkable.

thunkableDownload

After you have downloaded the mobile app, simply sign in to the same account as the one you registered to Thunkable with.

thunkableApp

## New Project

Once you have logged in to Thunkable, click on **create new app**. Input your app name and click create. You would then see the project page.

thunkableCreateproject

thunkableProjectName

thunkableProject

## Hello World!

In your project page, you will see that there is a mobile screen and some items to the left hand side of the page. The awesome thing about Thunkable is that you can drag and drop functions that you want in your mobile app!

Let us start off with something simple. We are going to add a text to our app! In the **Add Components** menu, drag and drop the item called **label** onto the screen. Rename the label to `text` and set the font size to `24`.

After you have configured the label, on the top left hand corner of the page, navigate to the tab called **blocks**. 

ThunkableInsert

This is the place where you would do your programming!

thunkableBlock

Programming in Thunkable is very simple as it is also drag and drop. Simply navigate to the function that you would like to insert and place it inside the code section. On the sidebar, click on `Screen1` and drag out this component:

What this does is to tell the app that when this screen opens in the app, do something *(that you will define)*. Next, click on `Label1` and drag out this component:

This is to tell the label we had just created to display a certain text. In the text box, type in `Hello World`.

Next, click on **Live Test** located on the top of the page. Open your thunkable app and you should be able to see your app appearing in the screen!

## Let's add some interaction!

It would be great to interact with the app that you create, so let us create a button. Go to the design tab and then drag out the **button** object onto the screen. Rename the button to `Click to activate text`.

Go back to the **Blocks** tab and delete the Screen1 function. Instead replace it with this from `Button1`.

This function means that whenever I press the button in the app, the text would change to `Hello World`.

Try it out in your Thunkable app!

Next, we would want to add a slider into the app. Go to the design tab and then drag out the **Slider** object onto the screen.

Go back to the **Blocks** tab and drag this block of code into the coding area. After which drag the `from label set text to` function into the block. Replace the text box with the `value` block.

Now you can try it out in your Thunkable app!

## Moving your app objects

At this stage, you may want your slider, button and label to be slightly further apart as they seem too close, don't they? Unfortunately it would not be as simple as dragging and rearranging the objects. 

we will need to adjust the position properties in the **Design** tab. On the right hand side, there would be the area for you to adjust the object properties.

There is the position adjustment in that area and adjust the margin of the object. You would realise that the object would move as you edit the margin. Adjust the margins till the application objects are futher away from each other.

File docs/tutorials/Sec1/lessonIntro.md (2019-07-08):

---
title: Welcome to a world of technology!
date: 2019-07-08
author: Goh Qian Zhe
---
# Welcome to a world of technology!

This tutorial series is created for Secondary 1 students' ICT lessons. It is created by Goh Qian Zhe, Pan Ziyue and massively supported by SST teachers such as:

* Mr Aurelius Yeo
* Mr Jonathan Chua
* Mr Tan Hoe Teck

## What are these tutorials about?

The SSTuino Innovator's Kit was designed to be simple enough for anyone without any programming or electronics knowledge to use; and yet be powerful enough for anyone with Arduino knowledge to bring themselves further by having Internet of Things functionality.

As an SST alumni, we had little to none programming or electronics knowledge when we entered the school. Therefore we would like to use these tutorial series to let students know how to use this platform as a step towards their innovative education experience.

With this tutorial series we would like the students to discover:

* A brief history and the future possibilities of the technologies around them
* How design and innovation applies to technology
* Prototyping with mobile applications
* Simple electronics, programming and tinkering skills
* Interacting electronic devices with the internet and understanding the possibilities of such platform

## Useful resources

Please visit this page for a list of resources that we use to create this content.

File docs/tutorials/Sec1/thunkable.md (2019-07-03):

---
title: Getting Started with Thunkable
date: 2019-07-03
author: Goh Qian Zhe
---

# Create your first mobile app with thunkable!

If your intended product/solution includes a mobile application, there are a variety of app development environments for you to choose from. Thunkable is a simple to use platform for developing applications for both Andriod and iOS as it uses block coding, which means that to build an app, all you would have to do is to drag and drop your functions in the build screen.

## Registering for the service

Signing up for Thunkable is very simple. Click the Sign up button on the top right hand corner and sign up either with your Google account or email

After you are done, go to your App Store or Play store to download the Thunkable app as this app is used to visualise the app that you have built in Thunkable.

After you have downloaded the mobile app, simply sign in to the same account as the one you registered to Thunkable with.

## My First App!

Have a simple tutorial for the students to try out first.

## Planning your application

Assuming you already have your ideas generated and you (and your team) has confirmed on the idea, it is time to plan the layout of your application. Before you begin programming your app, it is important to visualise and plan what you would want your application users to experience!

## Integrating a Web API into your application

What is an API? API stands for **Application Programming Interface** and it basically allows applications to communicate with one another.

For this tutorial, we will be interfacing with a Web API to retrive data and then display in our app.

## App Layout

--- Insert Content ---

## Programming

--- Insert Content ---

## Control your SSTuino with your app!

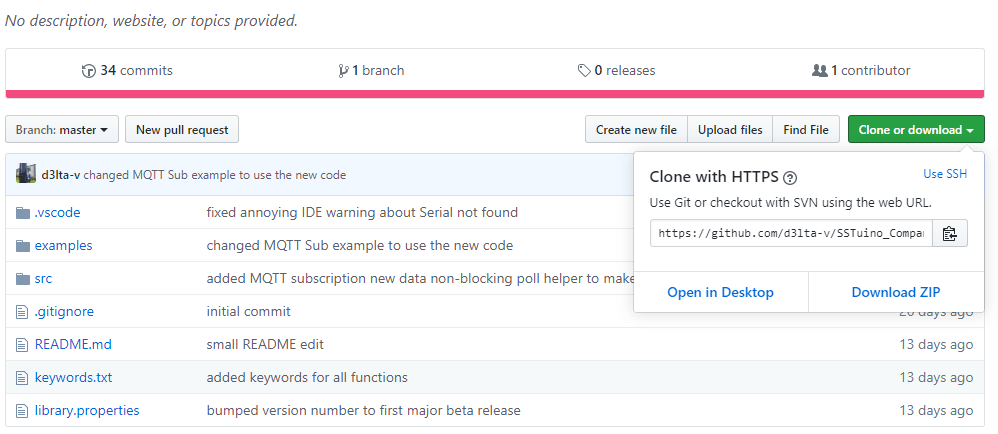
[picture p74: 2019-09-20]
docs/tutorials/Sec1/sstuinoIoT_images/SSTuinoIoT1.png

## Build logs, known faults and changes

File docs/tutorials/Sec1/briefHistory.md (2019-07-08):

---
title: A brief history...and the future!
date: 2019-07-08
author: Goh Qian Zhe
---

# A brief history...and the future!

So, you look around yourself and wonder: "I wonder how was it like before?" Technology is a very big thing, and has evolved significantly. Did you know that the SSTuino's computing abilities are a tiny fraction of what your mobile devices are like now?

## How was computing like back then?

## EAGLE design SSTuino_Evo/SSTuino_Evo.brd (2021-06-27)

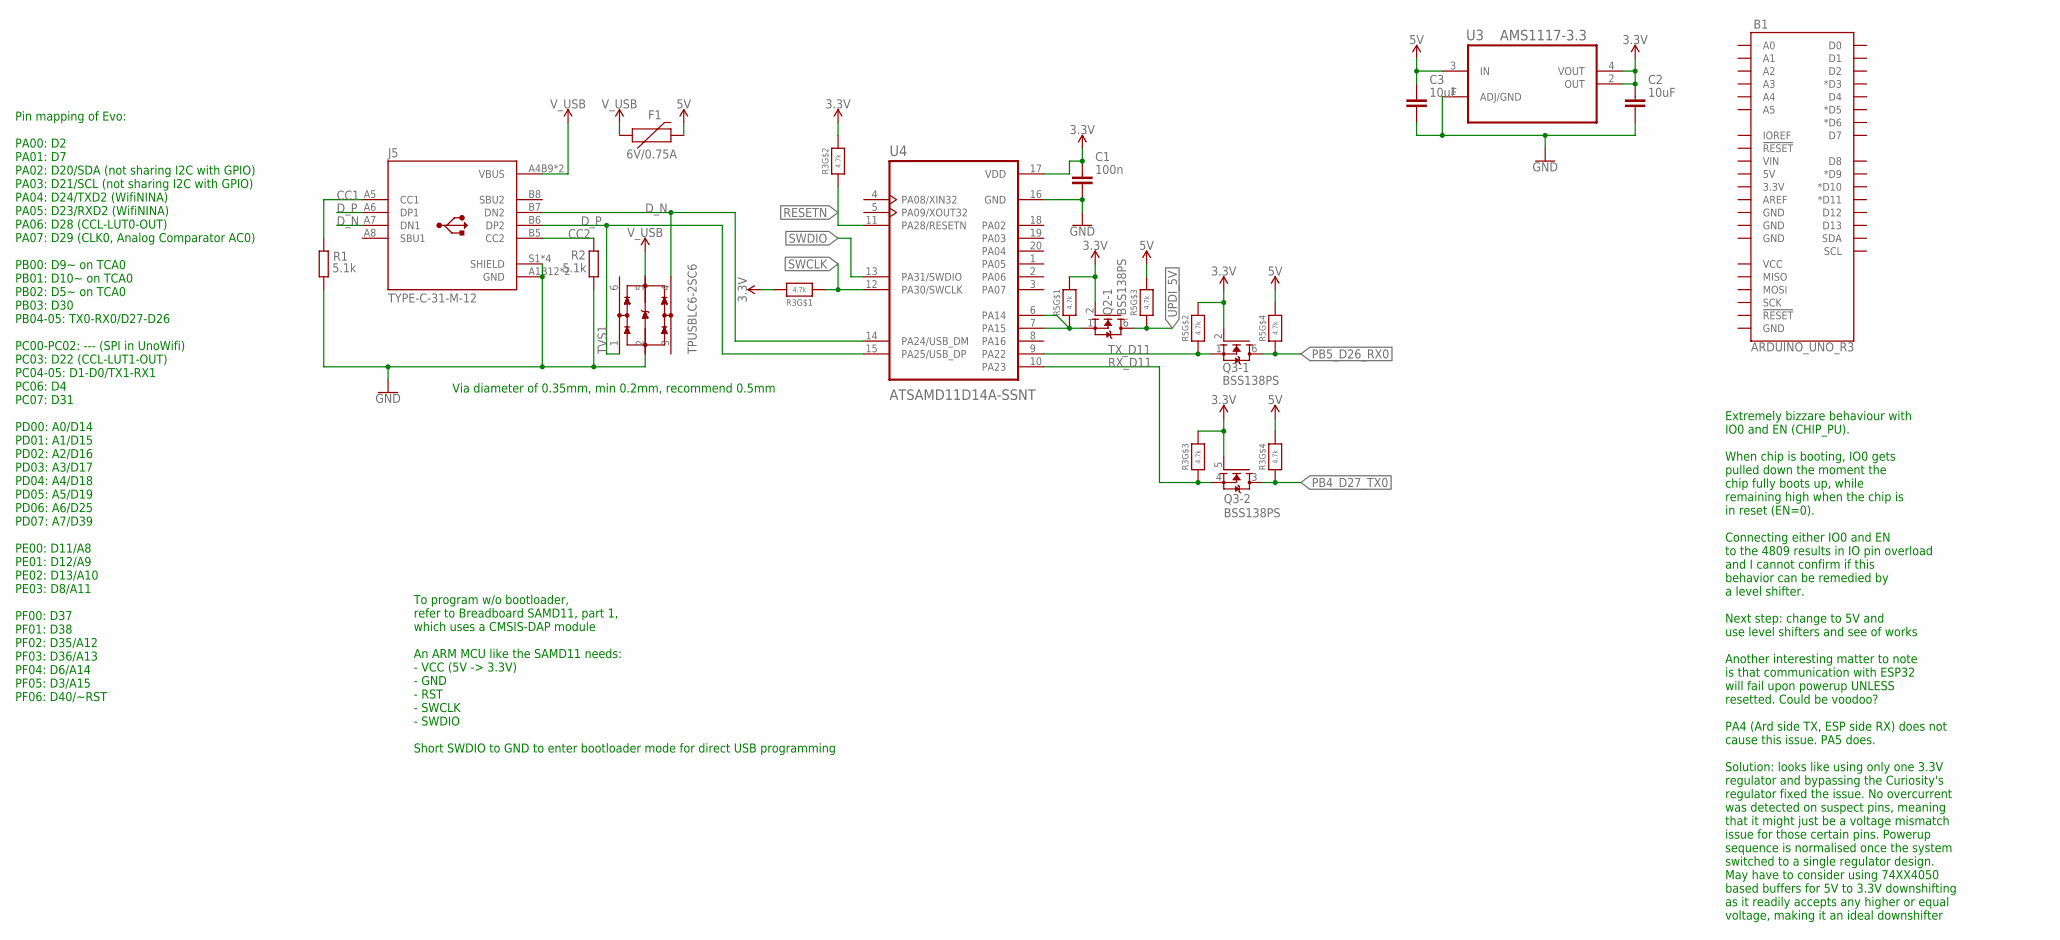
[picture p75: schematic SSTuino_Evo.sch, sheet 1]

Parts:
B1: ARDUINO_UNO_R3; ARDUINO_R3
C1: 100n; CAPC1005X60
C2, C3: 10uF; CAPC1608X85
F1: 6V/0.75A; 1206; LCSC_PART C99563
J5: TYPE-C-31-M-12; HRO_TYPE-C-31-M-12; LCSC_PART C165948
Q2, Q3: BSS138PS; ARDUINO-TRANSISTORS_SOT363; LCSC_PART C193381
R1, R2: 5.1k; RESC1005X40
R3, R5: 4.7k; RESPACK_4X0402; LCSC_PART C1980
TVS1: TPUSBLC6-2SC6; SOT95P280X110-6N; LCSC_PART C558442
U3: AMS1117-3.3; SOT230P696X180-4N; LCSC_PART C6186
U4: ATSAMD11D14A-SSNT; SOIC127P1030X265-20N; LCSC_PART C2053599

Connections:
3.3V: C1.1, C2.1, Q2.2 (G), Q3.2 (G), Q3.5 (G), R3.6 (2), R3.7 (2), R3.8 (2), R5.7 (2), R5.8 (2), U3.2 (OUT), U3.4 (VOUT), U4.17 (VDD); also elsewhere on the board
5V: C3.1, F1.2, R3.5 (2), R5.5 (2), R5.6 (2), U3.3 (IN); also elsewhere on the board
CC1: J5.A5 (CC1), R1.1
CC2: J5.B5 (CC2), R2.2
D_N: J5.A7 (DN1), J5.B7 (DN2), TVS1.4 (IO3), U4.14 (PA24/USB_DM)
D_P: J5.A6 (DP1), J5.B6 (DP2), TVS1.1 (IO1), U4.15 (PA25/USB_DP)
GND: C1.2, C2.2, C3.2, J5.A1B12 (GND), J5.B1A12 (GND), J5.S1 (SHIELD), J5.S2 (SHIELD), J5.S3 (SHIELD), J5.S4 (SHIELD), R1.2, R2.1, TVS1.2 (VSS), U3.1 (ADJ/GND), U4.16 (GND); also elsewhere on the board
PB4_D27_TX0: Q3.3 (D), R3.4 (1); also elsewhere on the board
PB5_D26_RX0: Q3.6 (D), R5.4 (1); also elsewhere on the board
RESETN: R3.2 (1), U4.11 (PA28/RESETN); also elsewhere on the board
RX_D11: Q3.4 (S), R3.3 (1), U4.10 (PA23)
SWCLK: R3.1, U4.12 (PA30/SWCLK); also elsewhere on the board
SWDIO: U4.13 (PA31/SWDIO); also elsewhere on the board
TX_D11: Q3.1 (S), R5.2 (1), U4.9 (PA22)
UPDI_3V3: Q2.1 (S), R5.1, U4.6 (PA14), U4.7 (PA15)
UPDI_5V: Q2.6 (D), R5.3 (1); also elsewhere on the board
V_USB: F1.1, J5.A4B9 (VBUS), J5.B4A9 (VBUS), TVS1.5 (VCC)

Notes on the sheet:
Pin mapping of Evo: PA00: D2 PA01: D7 PA02: D20/SDA (not sharing I2C with GPIO) PA03: D21/SCL (not sharing I2C with GPIO) PA04: D24/TXD2 (WifiNINA) PA05: D23/RXD2 (WifiNINA) PA06: D28 (CCL-LUT0-OUT) PA07: D29 (CLK0, Analog Comparator AC0) PB00: D9~ on TCA0 PB01: D10~ on TCA0 PB02: D5~ on TCA0 PB03: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
To program w/o bootloader, refer to Breadboard SAMD11, part 1, which uses a CMSIS-DAP module An ARM MCU like the SAMD11 needs: - VCC (5V -> 3.3V) - GND - RST - SWCLK - SWDIO Short SWDIO to GND to enter bootloader mode for direct USB programming
Extremely bizzare behaviour with IO0 and EN (CHIP_PU). When chip is booting, IO0 gets pulled down the moment the chip fully boots up, while remaining high when the chip is in reset (EN=0). Connecting either IO0 and EN to the 4809 results in IO pin overload and I cannot confirm if this behavior can 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
Via diameter of 0.35mm, min 0.2mm, recommend 0.5mm

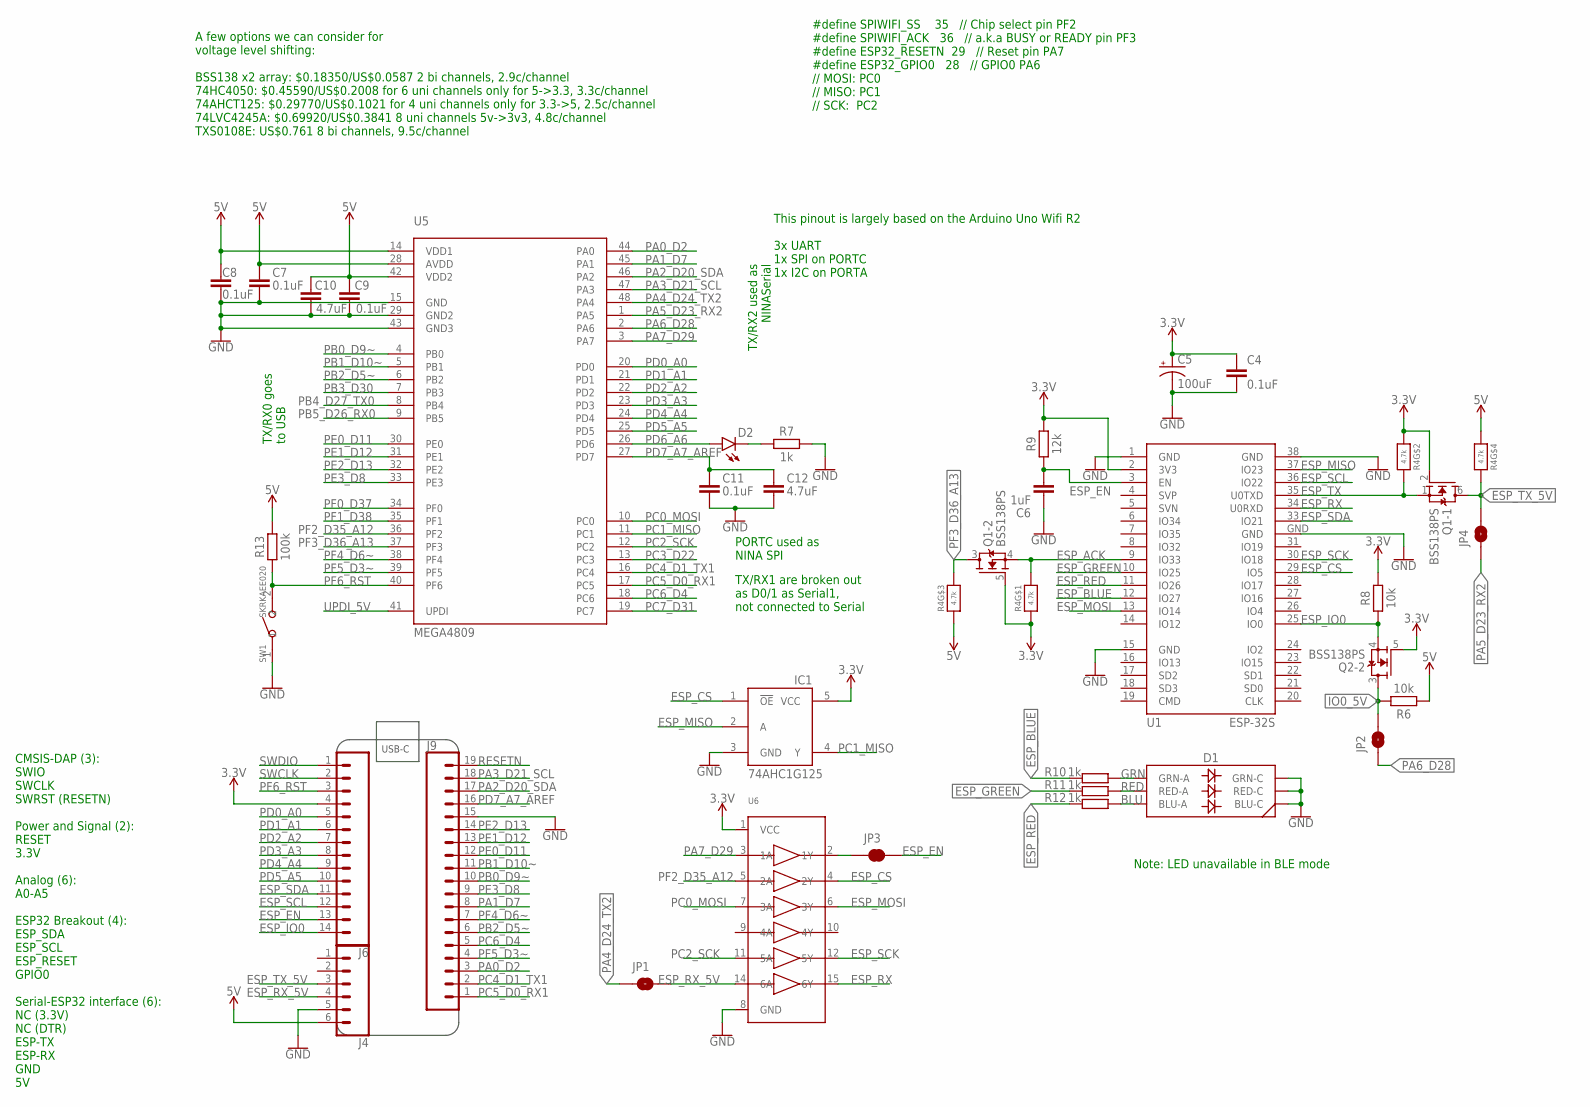
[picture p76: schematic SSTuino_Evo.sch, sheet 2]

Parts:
C4, C7, C8, C9, C11: 0.1uF; CAPC1005X60
C5: 100uF; CAPMP3216X180N
C6: 1uF; CAPC1005X60
C10, C12: 4.7uF; CAPC1005X60
D1: LED-RGBTC5050RGBF08; LED-TRICOLOR-5050
D2: LED0603; LED-0603
IC1: 74AHC1G125; SOT23-5L; LCSC_PART C124295
J4: CONN_06NO_SILK_FEMALE_PTH; 1X06_NO_SILK
J6: CONN_14NO_SILK; 1X14_NO_SILK
J9: CONN_191X19_NO_SILK; 1X19_NO_SILK
JP1, JP2, JP4: JUMPER-SMT_2_NO_SILK; SMT-JUMPER_2_NO_SILK
JP3: JUMPER-SMT_2_NC_TRACE_SILK; SMT-JUMPER_2_NC_TRACE_SILK
Q1, Q2: BSS138PS; ARDUINO-TRANSISTORS_SOT363; LCSC_PART C193381
R4: 4.7k; RESPACK_4X0402; LCSC_PART C1980
R6, R8: 10k; RESC1005X40
R7, R10, R11, R12: 1k; RESC1005X40
R9: 12k; RESC1005X40
R13: 100k; RESC1005X40
SW1: SKRKAEE020; SW2-2.6-3.9X2.9X1.5+0.4MM; LCSC_PART C115357
U1: ESP-32S
U5: MEGA4809; TQFP48; LCSC_PART C189475
U6: 74HC4050DTSSOP; TSSOP16; LCSC_PART C43181

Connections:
3.3V: C4.1, C5.1 (+), IC1.5 (VCC), J6.4, Q1.2 (G), Q1.5 (G), Q2.5 (G), R4.1, R4.2 (1), R8.2, R9.2, U1.2 (3V3), U6.1 (VCC); also elsewhere on the board
5V: C7.1, C8.1, C9.1, C10.1, J4.6, R4.3 (1), R4.4 (1), R6.1, R13.2, U5.14 (VDD1), U5.28 (AVDD), U5.42 (VDD2); also elsewhere on the board
BLU: D1.6 (BLU-A), R12.2
ESP_ACK: Q1.4 (S), R4.8 (2), U1.9 (IO33)
ESP_BLUE: R10.1, U1.12 (IO27)
ESP_CS: IC1.1 (!OE), U1.29 (IO5), U6.4 (2Y)
ESP_EN: C6.2, J6.13, JP3.2, R9.1, U1.3 (EN)
ESP_GREEN: R11.1, U1.10 (IO25)
ESP_IO0: J6.14, Q2.4 (S), R8.1, U1.25 (IO0)
ESP_MISO: IC1.2 (A), U1.37 (IO23)
ESP_MOSI: U1.13 (IO14), U6.6 (3Y)
ESP_RED: R12.1, U1.11 (IO26)
ESP_RX: U1.34 (U0RXD), U6.15 (6Y)
ESP_RX_5V: J4.4, JP1.2, U6.14 (6A)
ESP_SCK: U1.30 (IO18), U6.12 (5Y)
ESP_SCL: J6.12, U1.36 (IO22)
ESP_SDA: J6.11, U1.33 (IO21)
ESP_TX: Q1.1 (S), R4.7 (2), U1.35 (U0TXD)
ESP_TX_5V: J4.3, JP4.2, Q1.6 (D), R4.5 (2)
GND: C4.2, C5.2 (-), C6.1, C7.2, C8.2, C9.2, C10.2, C11.2, C12.2, D1.1 (BLU-C), D1.2 (RED-C), D1.3 (GRN-C), IC1.3 (GND), J4.5, J9.15, R7.2, SW1.1, U1.1 (GND), U1.15 (GND), U1.38 (GND), U1.GND, U5.15 (GND), U5.29 (GND2), U5.43 (GND3), U6.8 (GND); also elsewhere on the board
GRN: D1.4 (GRN-A), R10.2
IO0_5V: JP2.2, Q2.3 (D), R6.2
unnamed: D2.C, R7.1
unnamed: JP3.1, U6.2 (1Y)
PA0_D2: J9.3, U5.44 (PA0)
PA1_D7: J9.8, U5.45 (PA1)
PA2_D20_SDA: J9.17, U5.46 (PA2)
PA3_D21_SCL: J9.18, U5.47 (PA3)
PA4_D24_TX2: JP1.1, U5.48 (PA4)
PA5_D23_RX2: JP4.1, U5.1 (PA5)
PA6_D28: JP2.1, U5.2 (PA6)
PA7_D29: U5.3 (PA7), U6.3 (1A)
PB0_D9~: J9.10, U5.4 (PB0)
PB1_D10~: J9.11, U5.5 (PB1)
PB2_D5~: J9.6, U5.6 (PB2)
PB3_D30: U5.7 (PB3)
PB4_D27_TX0: U5.8 (PB4); also elsewhere on the board
PB5_D26_RX0: U5.9 (PB5); also elsewhere on the board
PC0_MOSI: U5.10 (PC0), U6.7 (3A)
PC1_MISO: IC1.4 (Y), U5.11 (PC1)
PC2_SCK: U5.12 (PC2), U6.11 (5A)
PC3_D22: U5.13 (PC3)
PC4_D1_TX1: J9.2, U5.16 (PC4)
PC5_D0_RX1: J9.1, U5.17 (PC5)
PC6_D4: J9.5, U5.18 (PC6)
PC7_D31: U5.19 (PC7)
PD0_A0: J6.5, U5.20 (PD0)
PD1_A1: J6.6, U5.21 (PD1)
PD2_A2: J6.7, U5.22 (PD2)
PD3_A3: J6.8, U5.23 (PD3)
PD4_A4: J6.9, U5.24 (PD4)
PD5_A5: J6.10, U5.25 (PD5)
PD6_A6: D2.A, U5.26 (PD6)
PD7_A7_AREF: C11.1, C12.1, J9.16, U5.27 (PD7)
PE0_D11: J9.12, U5.30 (PE0)
PE1_D12: J9.13, U5.31 (PE1)
PE2_D13: J9.14, U5.32 (PE2)
PE3_D8: J9.9, U5.33 (PE3)
PF0_D37: U5.34 (PF0)
PF1_D38: U5.35 (PF1)
PF2_D35_A12: U5.36 (PF2), U6.5 (2A)
PF3_D36_A13: Q1.3 (D), R4.6 (2), U5.37 (PF3)
PF4_D6~: J9.7, U5.38 (PF4)
PF5_D3~: J9.4, U5.39 (PF5)
PF6_RST: J6.3, R13.1, SW1.2, U5.40 (PF6)
RED: D1.5 (RED-A), R11.2
RESETN: J9.19; also elsewhere on the board
SWCLK: J6.2; also elsewhere on the board
SWDIO: J6.1; also elsewhere on the board
UPDI_5V: U5.41 (UPDI); also elsewhere on the board

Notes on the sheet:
A few options we can consider for voltage level shifting: BSS138 x2 array: $0.18350/US$0.0587 2 bi channels, 2.9c/channel 74HC4050: $0.45590/US$0.2008 for 6 uni channels only for 5->3.3, 3.3c/channel 74AHCT125: $0.29770/US$0.1021 for 4 uni channels only for 3.3->5, 2.5c/channel 74LVC4245A: $0.69920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
This pinout is largely based on the Arduino Uno Wifi R2 3x UART 1x SPI on PORTC 1x I2C on PORTA
TX/RX2 used as NINASerial
PORTC used as NINA SPI
TX/RX1 are broken out as D0/1 as Serial1, not connected to Serial
TX/RX0 goes to USB
#define SPIWIFI_SS 35 // Chip select pin PF2 #define SPIWIFI_ACK 36 // a.k.a BUSY or READY pin PF3 #define ESP32_RESETN 29 // Reset pin PA7 #define ESP32_GPIO0 28 // GPIO0 PA6 // MOSI: PC0 // MISO: PC1 // SCK: PC2
Note: LED unavailable in BLE mode
USB-C
CMSIS-DAP (3): SWIO SWCLK SWRST (RESETN) Power and Signal (2): RESET 3.3V Analog (6): A0-A5 ESP32 Breakout (4): ESP_SDA ESP_SCL ESP_RESET GPIO0 Serial-ESP32 interface (6): NC (3.3V) NC (DTR) ESP-TX ESP-RX GND 5V

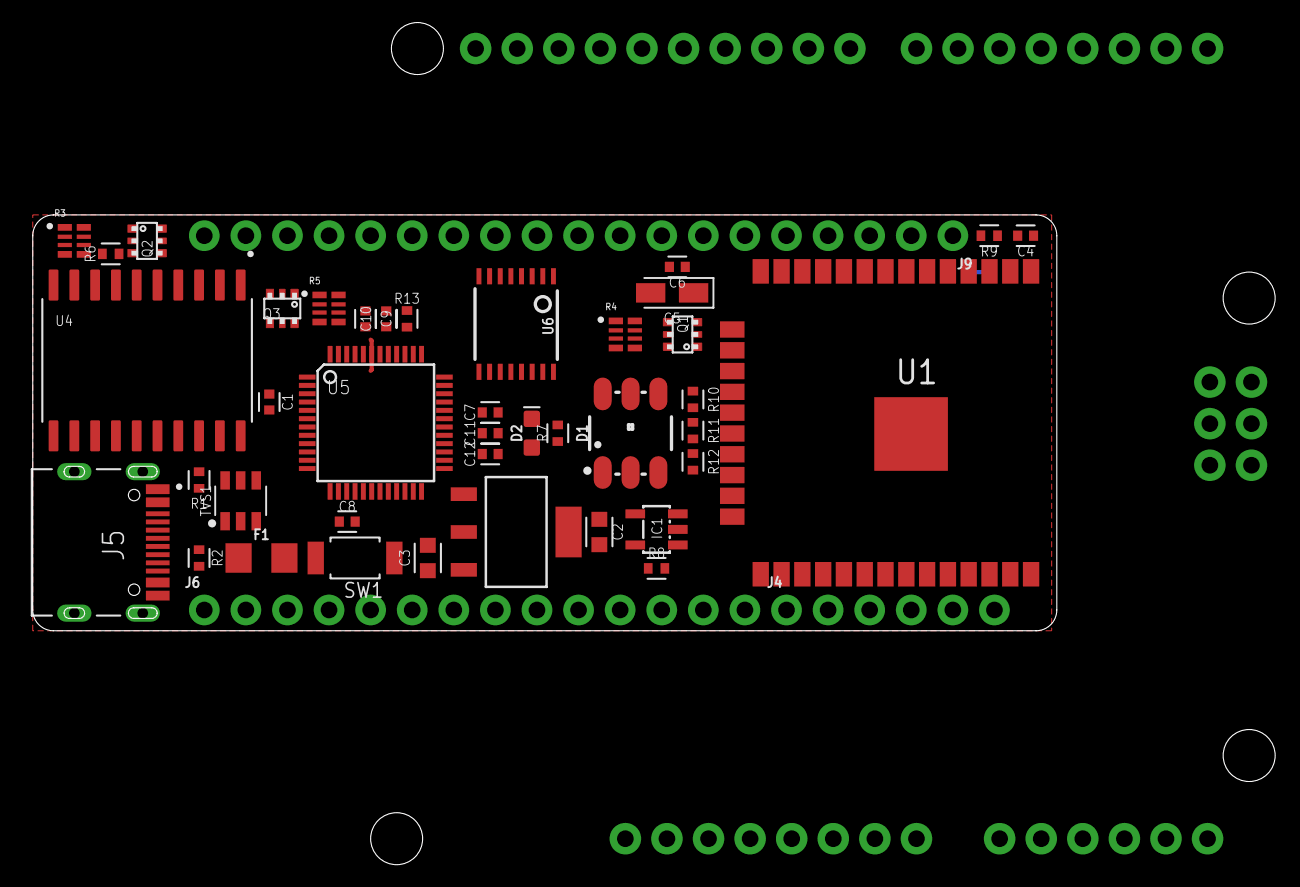
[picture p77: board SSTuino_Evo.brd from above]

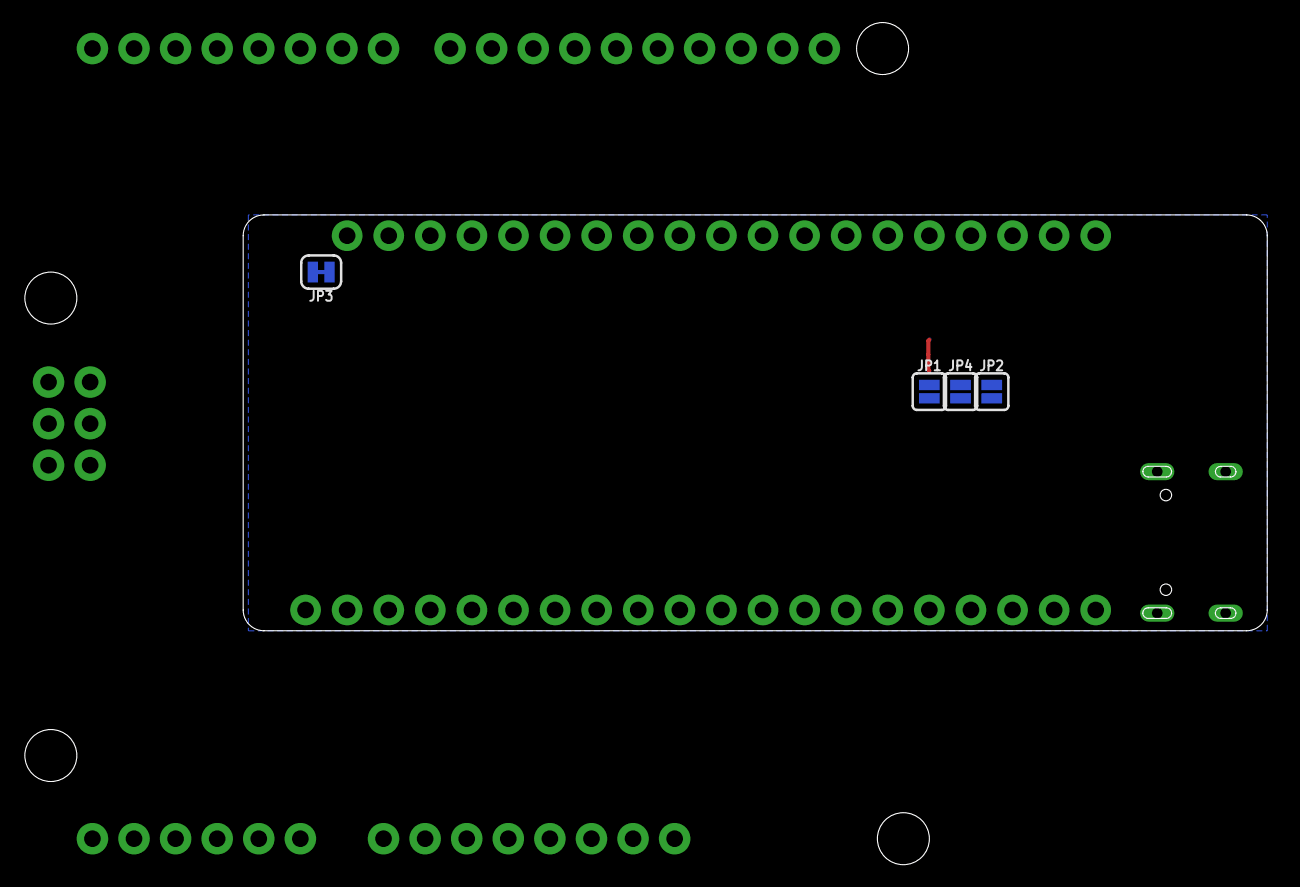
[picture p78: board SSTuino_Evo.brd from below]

Board: 2 copper layers, 62.5 x 25.4 mm, 48 parts (4 on the bottom side), 73 nets.

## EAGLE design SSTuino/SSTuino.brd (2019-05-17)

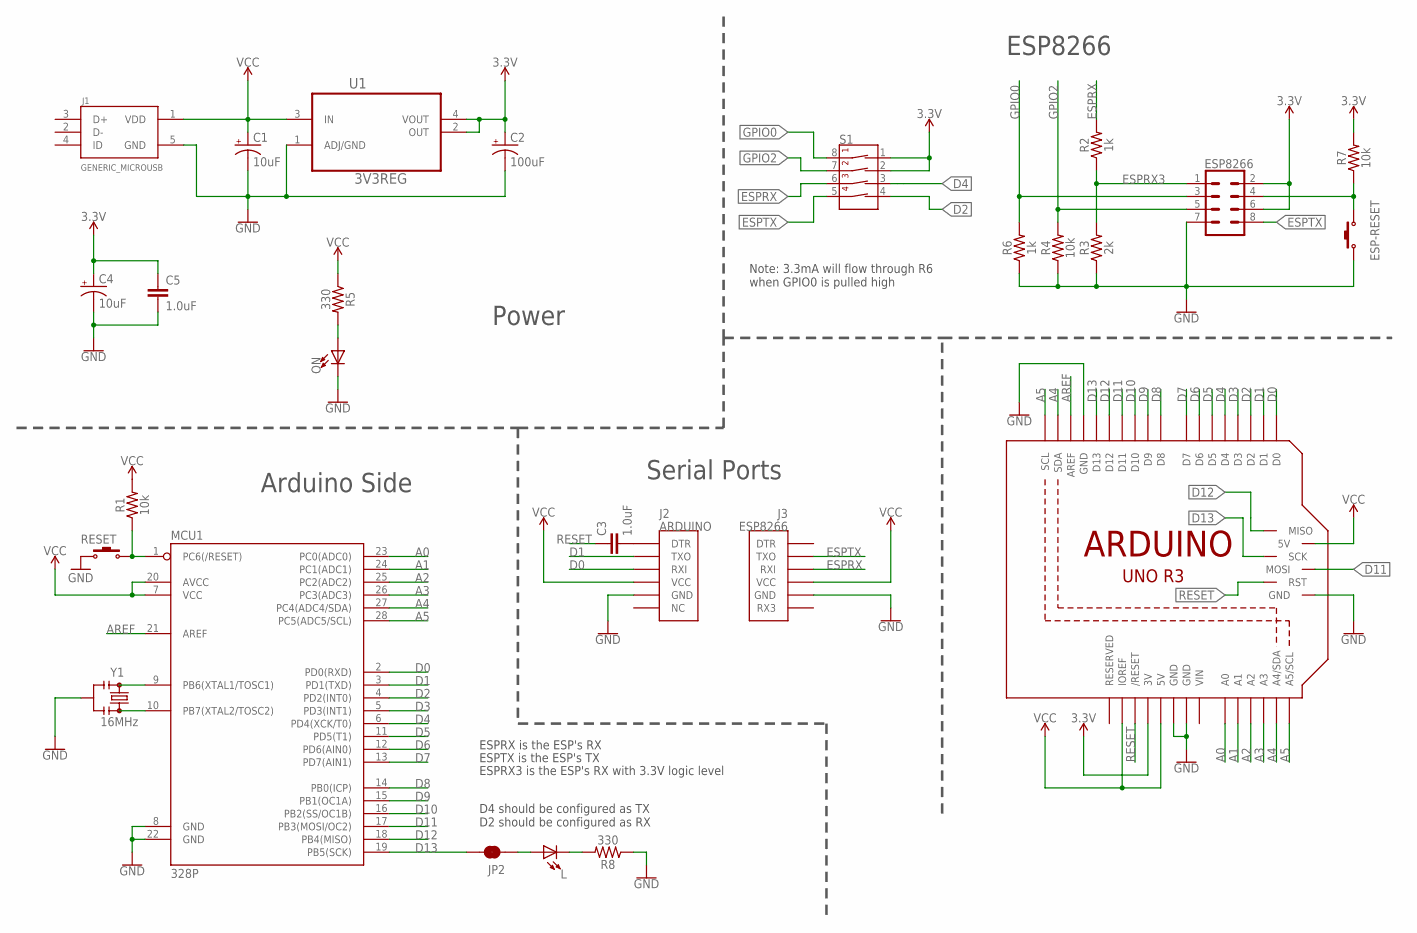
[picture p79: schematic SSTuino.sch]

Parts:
C1: 10uF; EIA3528
C2: 100uF; PANASONIC_D
C3, C5: 1.0uF; 1206
C4: 10uF; EIA3216
ESP8266: CONN_04X2; 2X4
ESP-RESET: SW-PB_(KAN0641); S-SP-4N-KAN0641
J1: GENERIC_MICROUSB; FRAMATOME_10118194-0001LF
J2: ARDUINO; CP2102_DEVICE_MICROUSB
J3: ESP8266; CP2102_DEVICE_MICROUSB_ESP8266
JP2: JUMPER-SMT_2_NC_TRACE_SILK; SMT-JUMPER_2_NC_TRACE_SILK
L: LED3MM
M1: ARDUINO_R3_ICSPSST; ARDUINOR3_ISCP_SST
MCU1: 328P; DIP28
ON: LED3MM
R1, R4, R7: 10k; 1206
R2, R6: 1k; 1206
R3: 2k; 1206
R5, R8: 330; 1206
RESET: SW-PB_(KAN0641); S-SP-4N-KAN0641
S1: DIP-04SMD; DIPSWITCH-04-SMD
U1: 3V3REG; SOT230P696X180-4N
Y1: 16MHz; RESONATOR-SMD-3.2X1.3

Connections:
3.3V: C2.+, C4.+, C5.1, ESP8266.2, ESP8266.6, M1.3V, R7.2, S1.1 (1A), S1.2 (2A), U1.2 (OUT), U1.4 (VOUT)
A0: M1.A0, MCU1.23 (PC0(ADC0))
A1: M1.A1, MCU1.24 (PC1(ADC1))
A2: M1.A2, MCU1.25 (PC2(ADC2))
A3: M1.A3, MCU1.26 (PC3(ADC3))
A4: M1.A4 (A4/SDA), M1.SDA, MCU1.27 (PC4(ADC4/SDA))
A5: M1.A5 (A5/SCL), M1.SCL, MCU1.28 (PC5(ADC5/SCL))
AREF: M1.AREF, MCU1.21 (AREF)
D0: J2.RXI, M1.D0, MCU1.2 (PD0(RXD))
D1: J2.TXO, M1.D1, MCU1.3 (PD1(TXD))
D2: M1.D2, MCU1.4 (PD2(INT0)), S1.4 (4A)
D3: M1.D3, MCU1.5 (PD3(INT1))
D4: M1.D4, MCU1.6 (PD4(XCK/T0)), S1.3 (3A)
D5: M1.D5, MCU1.11 (PD5(T1))
D6: M1.D6, MCU1.12 (PD6(AIN0))
D7: M1.D7, MCU1.13 (PD7(AIN1))
D8: M1.D8, MCU1.14 (PB0(ICP))
D9: M1.D9, MCU1.15 (PB1(OC1A))
D10: M1.D10, MCU1.16 (PB2(SS/OC1B))
D11: M1.D11, M1.MOSI, MCU1.17 (PB3(MOSI/OC2))
D12: M1.D12, M1.MISO, MCU1.18 (PB4(MISO))
D13: JP2.2, M1.D13, M1.SCK, MCU1.19 (PB5(SCK))
DTR: C3.2, J2.DTR
ESPRESET: ESP8266.4, ESP-RESET.3 (2), ESP-RESET.4 (2), R7.1
ESPRX: J3.P$4 (RXI), R2.2, S1.6 (3B)
ESPRX3: ESP8266.1, R2.1, R3.2
ESPTX: ESP8266.8, J3.P$3 (TXO), S1.5 (4B)
GND: C1.C (-), C2.-, C4.-, C5.2, ESP8266.7, ESP-RESET.1, ESP-RESET.2 (1), J1.5 (GND), J2.GND, J3.P$5 (GND), M1.GND, M1.GND@1 (GND), M1.GND@2 (GND), M1.GND@3 (GND), MCU1.8 (GND), MCU1.22 (GND), ON.K (C), R3.1, R4.1, R6.1, R8.1, RESET.1, RESET.2 (1), U1.1 (ADJ/GND), Y1.2
GPIO0: ESP8266.3, R6.2, S1.8 (1B)
GPIO2: ESP8266.5, R4.2, S1.7 (2B)
unnamed: MCU1.10 (PB7(XTAL2/TOSC2)), Y1.3
unnamed: L.K (C), R8.2
unnamed: JP2.1, L.A
unnamed: ON.A, R5.2
unnamed: MCU1.9 (PB6(XTAL1/TOSC1)), Y1.1
RESET: C3.1, M1.RESET (/RESET), M1.RESET_ICSP (RST), MCU1.1 (PC6(/RESET)), R1.1, RESET.3 (2), RESET.4 (2)
VCC: C1.A (+), J1.1 (VDD), J2.5V (VCC), J3.P$6 (VCC), M1.5V, M1.5V_ICSP (5V), M1.IOREF, MCU1.7 (VCC), MCU1.20 (AVCC), R1.2, R5.1, U1.3 (IN)
VIN: M1.VIN

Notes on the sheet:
ESPRX is the ESP's RX
ESPTX is the ESP's TX
D4 should be configured as TX D2 should be configured as RX
ESPRX3 is the ESP's RX with 3.3V logic level
Power
Arduino Side
Serial Ports
ESP8266
Note: 3.3mA will flow through R6 when GPIO0 is pulled high

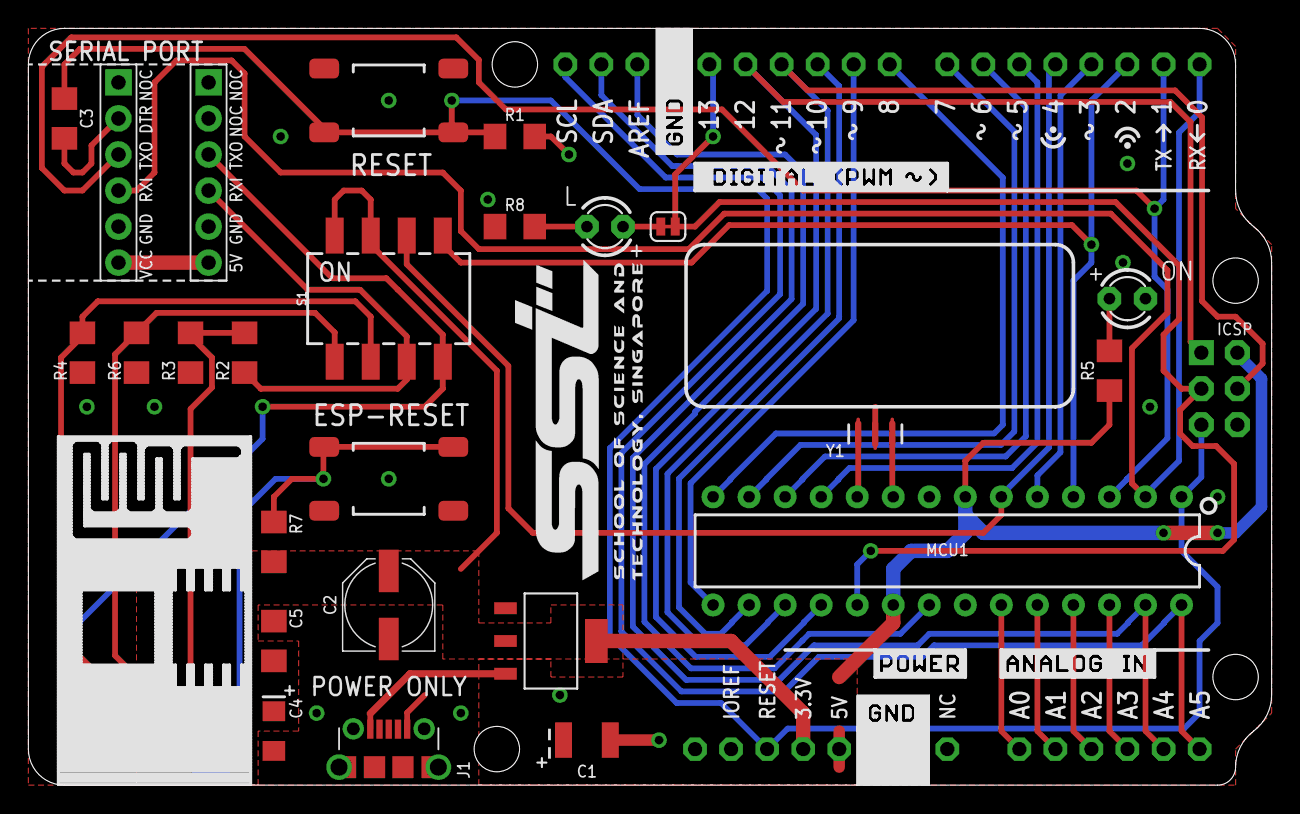
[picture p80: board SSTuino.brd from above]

Board: 2 copper layers, 87.6 x 53.3 mm, 30 parts (0 on the bottom side), 37 nets.

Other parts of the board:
U$1: ESP8266-NEGASILK
U$2: SST-MED
U$3: SST-HEXAGON-INV-BMP

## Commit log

2019-04-12 Switched with IMH-7481.jpg
2019-04-12 changed button designs
2019-05-14 Updated index and landingpage.md
2019-05-14 Updated SSTuino website landing page
2019-05-14 edited landingpage.md
2019-05-17 minor updates to board
    [SSTuino.brd, SSTuino.sch]
2019-05-26 Create Dupont Wires.jpg
2019-07-05 minor formatting to content in temperature sensor section
2019-07-08 insert images to thunkableIntro.md
2019-07-08 updated formatting for attached image asset
2019-07-16 edited resistor content in electronicBasics.md
2019-07-16 fixed header link for LED
2019-07-16 Upload of resistor pictures
2019-07-16 Insertion of media for metal and carbon resistor comparison
2019-09-19 Split actions on my fingertips to two sections to simplify tutorial
2019-09-20 added gerber files
    [SSTuino.GBL, SSTuino.GBO, SSTuino.GBP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]
2019-09-22 Inserted code for iot tutorial
2020-10-29 changed RGB led image size for ElectronicBasics
2021-01-15 Update partsList.md
    Updated amount of RGB LEDs included with the kit
2021-04-09 fixed broken library reference
    [SSTuino.sch]
2021-06-10 modified EVO
    [SSTuino_Evo.brd, SSTuino_Evo.sch]
2021-06-27 last update before routing
    [SSTuino_Evo.brd, SSTuino_Evo.sch]

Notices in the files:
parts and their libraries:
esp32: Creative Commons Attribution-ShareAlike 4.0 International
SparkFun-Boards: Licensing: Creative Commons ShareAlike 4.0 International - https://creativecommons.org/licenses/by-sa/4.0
